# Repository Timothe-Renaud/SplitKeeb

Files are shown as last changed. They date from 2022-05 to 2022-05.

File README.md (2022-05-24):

## SplitKeeb

Repo global de recherche sur les possibles creation de clavier macniques personnalisé type "split".
 Credit a tout les auteurs sauf moi c'est juste que j'ai la mega flemme de cherché leur depots H24
 
Liste des ref necessaire pours monter un ergodone:

 - [ ] keycaps *76 or 80 - anywere you want
 - [ ] Switches *76 or 80 - anywere you want
 - [ ] PCB *2 (2pieces or 1 set of two) - jlpcb.com + gerber files for the pcb
 - [ ] 1 expander mcp23018-E/SP
 - [ ] 2 socket TRRS 3,5mm type FC68129 or 2 CP-43514-ND 
 - [ ] 1 teensy 2,0 without / withoutpins - https://fr.aliexpress.com/item/4001105190306.html?spm=a2g0o.cart.0.0.39ad3c00QT3ftt&mp=1
 - [ ] 24 pins - https://fr.aliexpress.com/item/32552698181.html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,scm-url:1007.13339.169870.0,pvid:e1cd3605-2846-4530-83bc-7d73d2fb3bb8,tpp_buckets:668%230%23131923%2347_668%23888%233325%2313_668%232846%238116%232002_668%232717%237559%2365_668%231000022185%231000066059%230_668%233468%2315618%23985
 - [ ] Diodes *76 or *80 (those are NOT  surface mount) 1N4148 DO-35 - https://fr.aliexpress.com/item/32947233235.html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,searchweb201602_,searchweb201603_
 - [ ] 2 resistances 2,2k ohm, 5% [RRRGold] - https://fr.aliexpress.com/item/32847096736.html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,searchweb201602_,searchweb201603_
 - [ ] 3 leds like T1 3mm - https://fr.aliexpress.com/item/32620034766.html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,searchweb201602_,searchweb201603_
 - [ ] 3 resistances 220 ohm, [ 5% RRBlackGold ] - https://fr.aliexpress.com/item/32847096736.html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,searchweb201602_,searchweb201603_
 - [ ] 1 condensator ceramic 100 nanoF ou 0,1*µF - https://fr.aliexpress.com/item/32971478818.html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,searchweb201602_,searchweb201603_
 - [ ] 1 usb mini b female (the metal thingy)
 - [ ] 1 USB cable male A to male mini B
 - [ ] 1 USB mini B plugUSB mini B plug
 - [ ] jack cable 3,5mm TRRS
 - [ ] case [ or 3d printed yourself ]

 TUTO:
 - http://www.geekymartian.com/articles/building-an-ergodox/
 - 
 TODO:
  - mettre les vraix lien vers les createur & auteur des designe etc

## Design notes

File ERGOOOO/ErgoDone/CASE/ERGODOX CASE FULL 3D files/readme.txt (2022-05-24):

lien des files https://www.thingiverse.com/thing:2533064/files

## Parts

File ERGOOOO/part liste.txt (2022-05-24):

Parts list:

    1x Pair of pcbs (one for each hand) - kk
    1x Teensy USB Board, Version 2.0 - kk
    24x Teensy header pins, male (unless pre-installed)
    1x Microcontroleur MCP23018-E/SP I/O expander - kk
    76-80x 1N4148 diodes, SOD-123 package (Surface mount) or DO-35,(0.3” pitch) (through hole) (again, the amount needed will depend on your layout)
    2x 2.2k Ω resistors (red, red, red)
    3x 3mm T1 LEDs
    3x 220 Ω resistors, or match to LED. (red, red, brown)
    5x Short jumpers (You can also use the clipped off legs from your resistors)
    1x 0.1 µF ceramic capacitor (marked “104” for 10*104 picofarad). Not strictly necessary but suggested
    1x USB mini B connector WM17115
    1x USB mini B plug with short cable (such as H2955)
    1x USB cable male A to male mini B
    2x 3.5 mm TRRS sockets, CP-43514. FC68129 will also work if its extra pins are snipped off
    1x Cable with two 3.5 mm TRRS plugs
    76-80x Cherry MX switches, (depending on your layout)
    76-80x MX Keycaps

+++++https://www.ebay.com/sch/i.html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

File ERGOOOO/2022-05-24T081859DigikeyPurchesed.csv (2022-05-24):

Index | Quantity | Part Number | Manufacturer Part Number | Description | Customer Reference | Available | Backorder | Unit Price | Extended Price EUR
1 | 5 | MCP23018-E/SP-ND | MCP23018-E/SP | IC I/O EXPANDER I2C 16B 28SDIP |  | 5 | 0 | 2,06000 | 10,30
2 | 5 | WM17115-ND | 0548190519 | CONN RCPT USB2.0 MINI B 5P R/A |  | 5 | 0 | 2,11000 | 10,55
3 | 11 | CP-43514-ND | SJ-43514 | CONN JACK 4COND 3.5MM R/A |  | 11 | 0 | 0,85800 | 9,44
4 | 6 | BC2665CT-ND | K104K10X7RF5UH5 | CAP CER 0.1UF 50V X7R RADIAL |  | 0 | 6 | 0,29000 | 1,74
5 | 25 | 220QBK-ND | CFR-25JB-52-220R | RES 220 OHM 5% 1/4W AXIAL |  | 25 | 0 | 0,04520 | 1,13
6 | 25 | 2.2KQBK-ND | CFR-25JB-52-2K2 | RES 2.2K OHM 5% 1/4W AXIAL |  | 25 | 0 | 0,04520 | 1,13

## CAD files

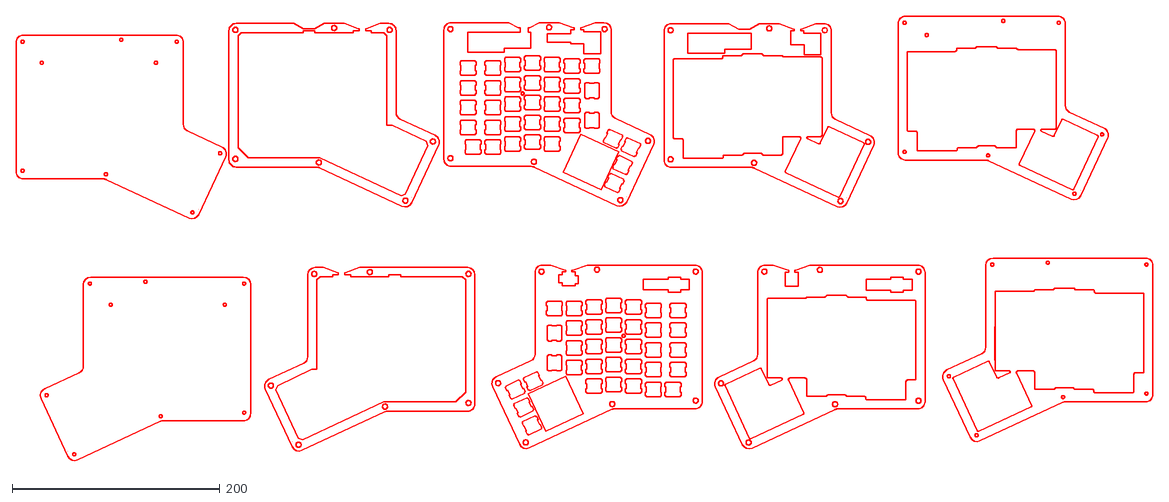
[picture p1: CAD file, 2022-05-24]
ERGOOOO/ErgoDone/CASE/ErgoDoneCase/ergodonecaseoriginal_standard.dxf
1095.3 x 429.0

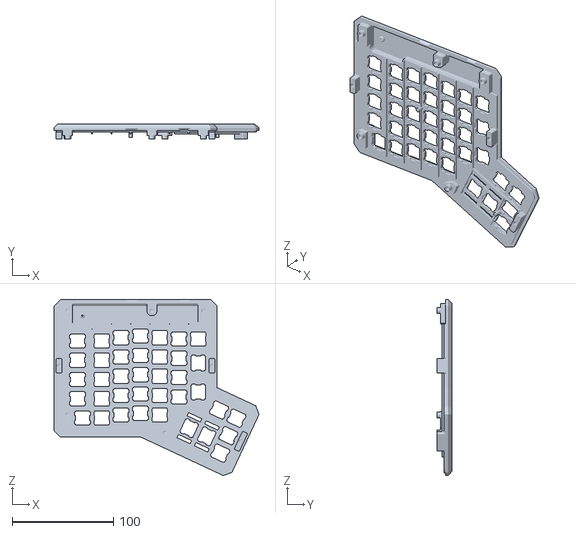
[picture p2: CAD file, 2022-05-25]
ERGOOOO/ErgoDone/CASE/ERGODOX CASE FULL 3D files/MergePlateTopRight.stl
202.4 x 15.2 x 173.8

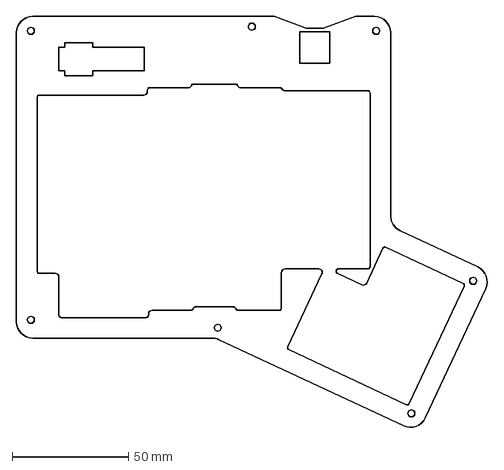
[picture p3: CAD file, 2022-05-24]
ERGOOOO/ErgoDox/ErgoDox Acrylic Case/ErgoDOX Acrylic Case - Designed by Litster/Standard/Left/ErgoDOX Case Layer 2 Spacer - Left.dxf
202.8 x 177.8 mm

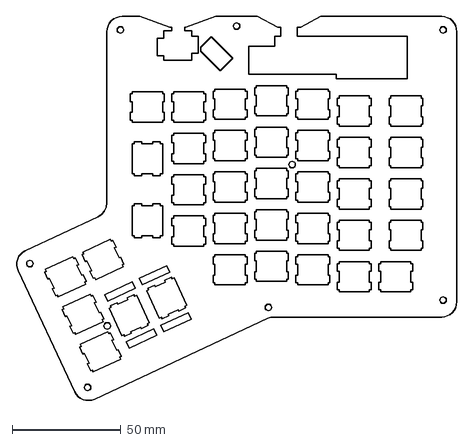
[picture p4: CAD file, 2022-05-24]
ERGOOOO/ErgoDox/ErgoDox Acrylic Case/ErgoDOX Acrylic Case - Designed by Litster/Standard/Right/ErgoDOX Case Layer 3 Plate - Right.dxf
202.8 x 177.8 mm

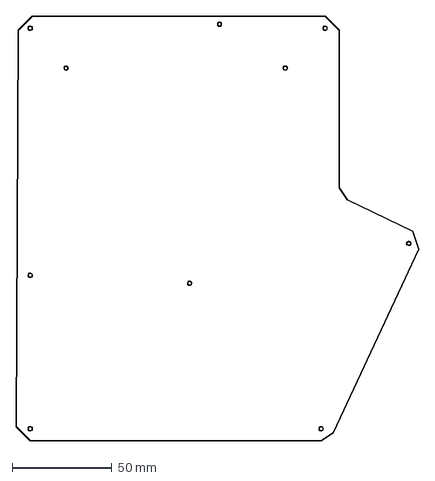
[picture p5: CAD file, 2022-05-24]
ERGOOOO/ErgoDox/ErgoDox Acrylic Case/ErgoDOX Acrylic Case - Designed by Litster/with Wrist Rest/Left/ErgoDOX Case Layer 5 Bottom - Left.dxf
202.0 x 213.0 mm

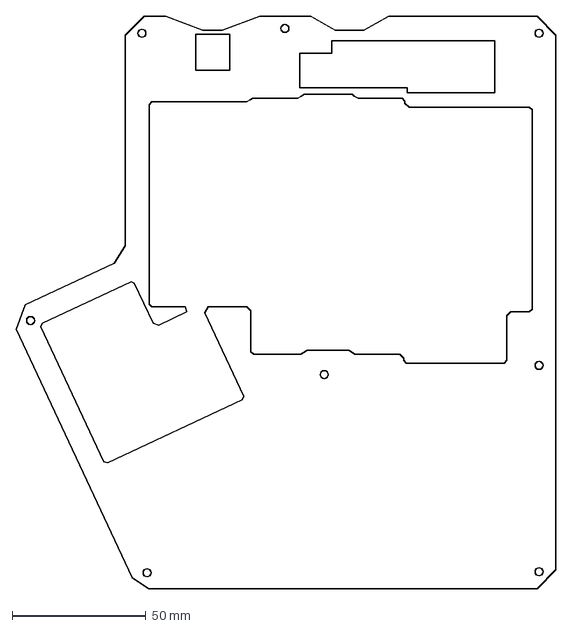
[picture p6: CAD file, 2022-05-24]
ERGOOOO/ErgoDox/ErgoDox Acrylic Case/ErgoDOX Acrylic Case - Designed by Litster/with Wrist Rest/Right/ErgoDOX Wrist Rest Case Layer 2 Spacer - Right.dxf
202.0 x 214.1 mm

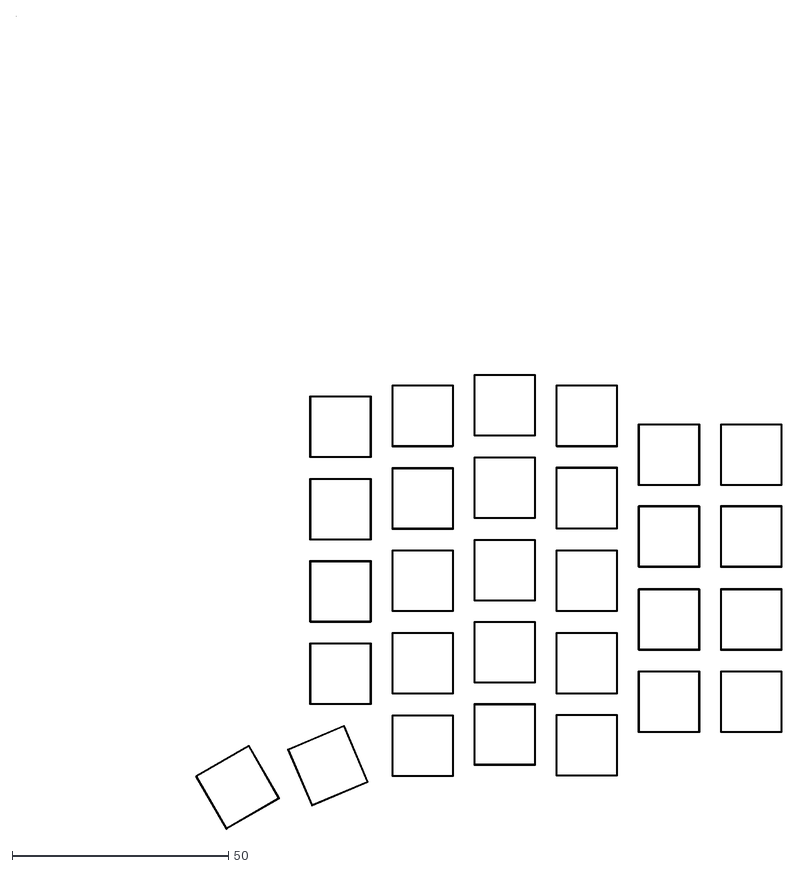
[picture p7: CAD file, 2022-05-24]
OtherTypeOf Keyboard/SOFLE/Design/v2/SofleKeyboard-Eco2_User.dxf
177.2 x 188.0

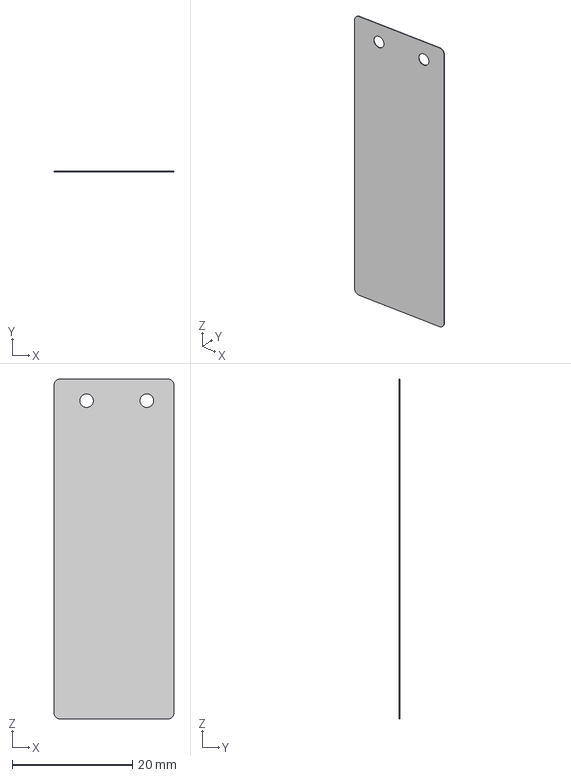
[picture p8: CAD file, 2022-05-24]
OtherTypeOf Keyboard/SOFLE/Sofle_v2/Case/sofle_v2_oled_cover_0.1.step
19.9 x 0.1 x 56.5 mm

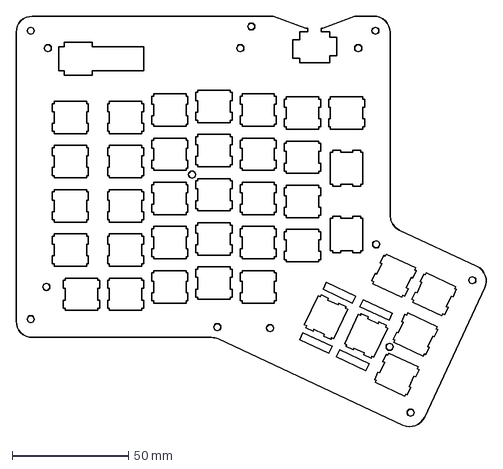
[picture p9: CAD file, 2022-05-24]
ERGOOOO/ErgoDox/ErgoDox Acrylic Case/ErgoDOX Acrylic Case - Designed by Litster/Standard/Left/ErgoDOX Case Layer 3 Plate - Left.dxf
202.8 x 177.8 mm

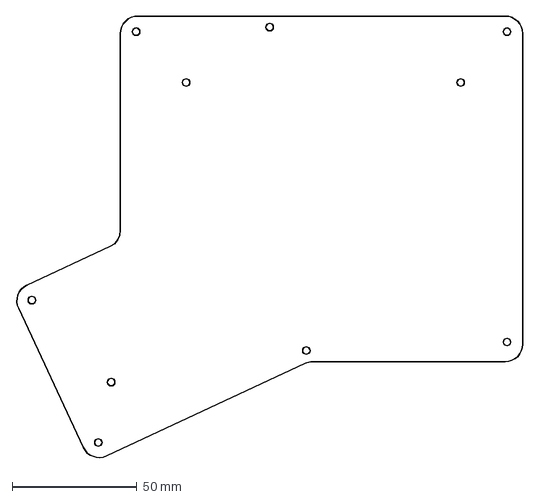
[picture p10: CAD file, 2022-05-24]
ERGOOOO/ErgoDox/ErgoDox Acrylic Case/ErgoDOX Acrylic Case - Designed by Litster/Standard/Right/ErgoDOX Case Layer 5 Bottom - Right.dxf
202.8 x 177.8 mm

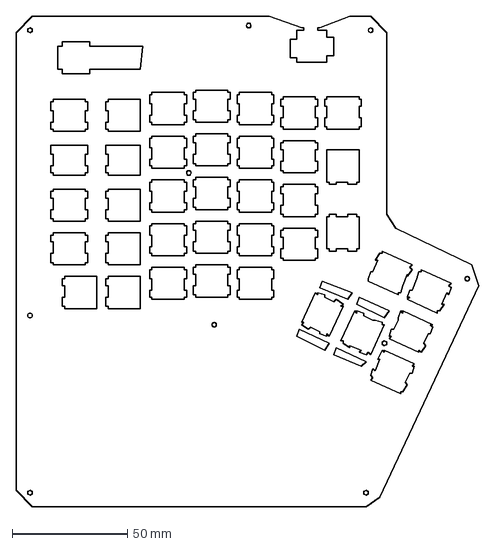
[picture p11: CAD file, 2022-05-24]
ERGOOOO/ErgoDox/ErgoDox Acrylic Case/ErgoDOX Acrylic Case - Designed by Litster/with Wrist Rest/Left/ErgoDOX Case Layer 3 Plate - Left.dxf
201.0 x 213.0 mm

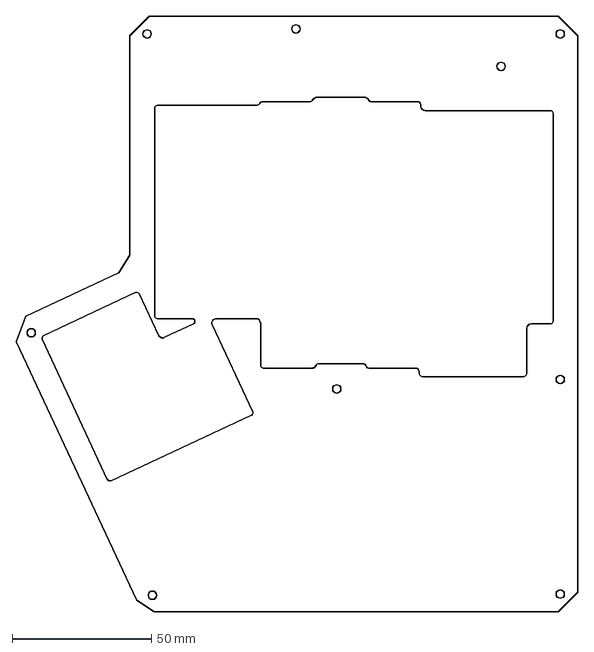
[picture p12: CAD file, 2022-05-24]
ERGOOOO/ErgoDox/ErgoDox Acrylic Case/ErgoDOX Acrylic Case - Designed by Litster/with Wrist Rest/Right/ErgoDOX Wrist Rest Case Layer 1 Top - Right.dxf
202.0 x 214.1 mm

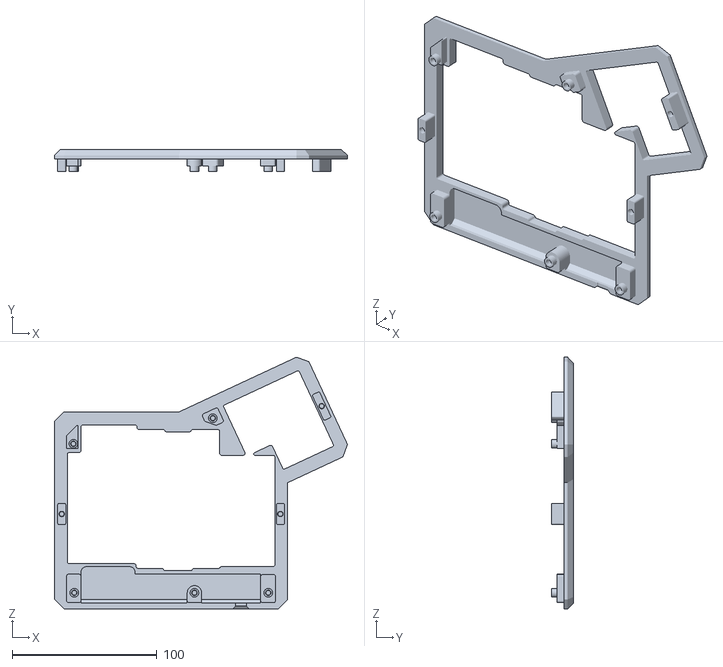
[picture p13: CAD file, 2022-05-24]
ERGOOOO/ErgoDone/CASE/ERGODOX CASE FULL 3D files/LeftTop.stl
202.4 x 15.2 x 173.8

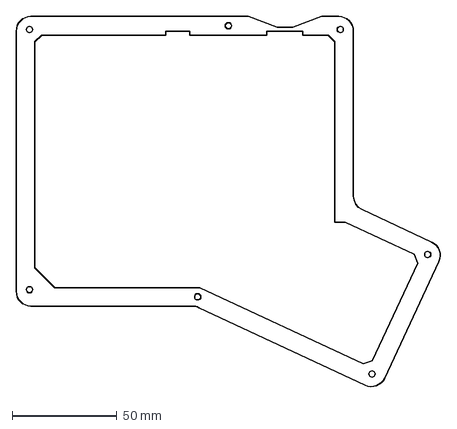
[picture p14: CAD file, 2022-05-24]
ERGOOOO/ErgoDox/ErgoDox Acrylic Case/ErgoDOX Acrylic Case - Designed by Litster/Standard/Left/ErgoDOX Case Layer 4 Spacer - Left.dxf
202.8 x 177.8 mm

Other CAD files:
ERGOOOO/ErgoDone/CASE/ERGODOX CASE FULL 3D files/MergePlateTopLeft.stl
ERGOOOO/ErgoDox/ErgodoxCaseEcoMode/MergePlateTopLeft.stl
ERGOOOO/ErgoDox/ErgoDox Acrylic Case/ErgoDOX Acrylic Case - Designed by Litster/Standard/Right/ErgoDOX Case Layer 1 Top - Right.dxf
ERGOOOO/ErgoDone/CASE/ERGODOX CASE FULL 3D files/LeftPlate.stl
ERGOOOO/ErgoDone/CASE/ERGODOX CASE FULL 3D files/RightPlate.stl
ERGOOOO/ErgoDone/CASE/ERGODOX CASE FULL 3D files/RightTop.stl
ERGOOOO/ErgoDox/ErgoDox Acrylic Case/ErgoDOX Acrylic Case - Designed by Litster/Standard/Left/ErgoDOX Case Layer 1 Top - Left.dxf
ERGOOOO/ErgoDox/ErgoDox Acrylic Case/ErgoDOX Acrylic Case - Designed by Litster/Standard/Left/ErgoDOX Case Layer 5 Bottom - Left.dxf
ERGOOOO/ErgoDox/ErgoDox Acrylic Case/ErgoDOX Acrylic Case - Designed by Litster/Standard/Right/ErgoDOX Case Layer 2 Spacer - Right.dxf
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

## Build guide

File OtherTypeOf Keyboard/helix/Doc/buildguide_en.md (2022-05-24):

# Helix Beta Build Guide

## Parts

The list below is for one half. To build both halves, you will need two sets of these parts.

| Name | Quantity | Notes |
| ---- | ---- | --- |
| PCB | 1 | |
| Pro Micro | 1 | |
| TRRS Jack | 1 | |
| Tactile Switch | 1 | |
| Spring-loaded pin headers 12-pin | 2 | Regular headers will also work |
| Plate (Acrylic or Stainless) | 1 set | |
| Display Cover Plate | 1 | |
| M2 Spacer 4mm | 6 | For low-profile switches |
| M2 Spacer 7mm | 6 | For MX-style switches |
| M2 Spacer 8mm | 2 | |
| M2 Screw 3mm| 14 | |
| M2 Low Profile Screw 5mm| 2 | |
| Rubber Bump-Ons | 6 |  |
| Diodes | 32 | SMD diodes are required for low-profile switches. |
| Keyswitches | 32 | Either Cherry MX or Kailh Low-Profile compatible |
| Keycaps | 32 | Whichever caps suit the switches |
| 3.5mm Aux Cable | 1 | For the split connection |
| MicroUSB Cable | 1 | |
| Insulating Sheet | 1 | For stainless steel plates (Optional) |
| WS2812B Strip (6 LEDs) | 1 | For underglow (Optional) |
| SK6812mini | 32 | For backlight (Optional) |
| OLED Module | 1 | For OLED display (Optional) |
| Socket, 4-Pin | 1 | For OLED display (Optional) |
| Headers, 4-Pin | 1 | For OLED display (Optional) |

## Necessary Tools

| Name | Notes |
| ---- | ---- |
| Soldering Iron | If using backlight LEDs, it must be temperature-controllable. |
| Thin solder | ~0.8mm diameter recommended |
| Tweezers | For SMD part assembly |

## Selecting Options
Before beginning assembly, it will be necessary to decide on the options for the build.

### Row Quantity (5 or 4)
By breaking away the bottom row, you can select the row quantity.

### LED Selection (Underglow or Backlight)
Either the per-key backlight or below-PCB underglow may be selected.

## Building the Helix

The guide will focus on the left half. For the right, simply flip the PCB.

Imgur

__It is strongly recommended to read the ENTIRE build guide first before beginning work.__

### Preparing the PCB

If installing the optional OLED display, jumpers must be connected.
Please solder the four jumpers on the __upper side__ of the PCB on both halves.
(Do not solder jumpers on both the front and rear.)

Imgur

### Installing Parts

#### Diodes

Install diodes onto the __bottom__, whether through-hole or surface mount.  Note: if using choc low profile switches surface mount diodes are recommended as through hole diode legs would need to be flush on the top of the board to allow the top plate to sit correctly.  See issue [22](https://github.com/MakotoKurauchi/helix/issues/22) for details and work arounds.

Make sure all diodes are installed in the correct orientation.
Even when the silk label is invisible, all diodes face the same orientation.

Imgur

Imgur

#### Backlight LED (Optional)

Backlight LEDs are installed from the **bottom** of the PCB. Verify the orientation of the LEDs when installing - the largest pad should align with the corner marked with the circle on the silkscreen layer.

There are some places where this silkscreen is invisible; however, all LEDs of each row face the same orientation. However, **not all rows share the same orientation** (they switch orientation by 180 degrees each row).

Using a variable temperature soldering iron, solder the LEDs into place at roughly 220C (428F). __Overheating the LEDs will destroy the LEDs.__

Imgur

Imgur

An efficient method is to solder the largest pads on the entire row, then to do the rest of the pads.

#### TRRS Jack

Install from the topside following the silkscreen.

Imgur

#### Reset Switch

Install from the topside as marked by silkscreen.

Imgur

#### Pro Micro

Solder the spring loaded header to the pro micro, making sure that the bottom side faces upwards.

Imgur

The recommended orientation is the following.

Imgur

The smaller windows should be on the Pro Micro side.
Also, install so both sets of headers have the small windows facing the same orientation.

Imgur

Imgur

Installing in the wrong orientation or applying significant force before soldering will lead to the pins ejecting. Also, the legs are easily bent; please take care when inserting and removing the Pro Micro from the PCB.

With the bottom side up, insert the header-loaded Pro Micro onto the through-hole pads. Even without soldering, it should lock into place.

Imgur

#### OLED Module (Optional)

Install sockets on the topside, and solder the headers onto the OLED module.
Install the OLED module so it covers the Pro Micro below.

Imgur

Imgur

#### RGB Underglow Strip

After verifying orientation, either solder into place or solder using jumper wires.

Imgur

#### Switches

Install switches to the plate, then to the PCB, and solder.
Be careful of solder bridges when other parts are close by.

Imgur

* At this point, it is recommended to flash the [firmware](firmware_en.md), and to verify that everything functions properly.

### Final Assembly

Install two 8mm standoffs on the topside, and screw into place.

Imgur

Using 4mm standoffs on low-profile and 7mm for MX, secure the bottom plate into place as to sandwich the PCB.

Imgur

Install the display-protecting plate using the low-profile screws.

Imgur

Install bump-ons.

Imgur

The build is complete.

Imgur

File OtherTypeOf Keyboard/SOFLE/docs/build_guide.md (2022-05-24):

---
layout: default
title: Sofle Keyboard - build guide (v1/v2)
---

This guide suits both version **V1** and **V2** of the standard (**non-RGB**) Sofle Keyboard. Most of the photos are for v1 and the differences are explained in the text as needed.

The **RGB** version has [dedicated build guide][rgbbuildguide].

The **Choc** version has [dedicated build guide][chocbuildguide].

If you don't have all the necessary parts, please read about [how to source the parts][sourcing].

## Bill of materials

The following is needed to build the keyboard. You can find [links for the most of the components in the sourcing parts section][sourcing].

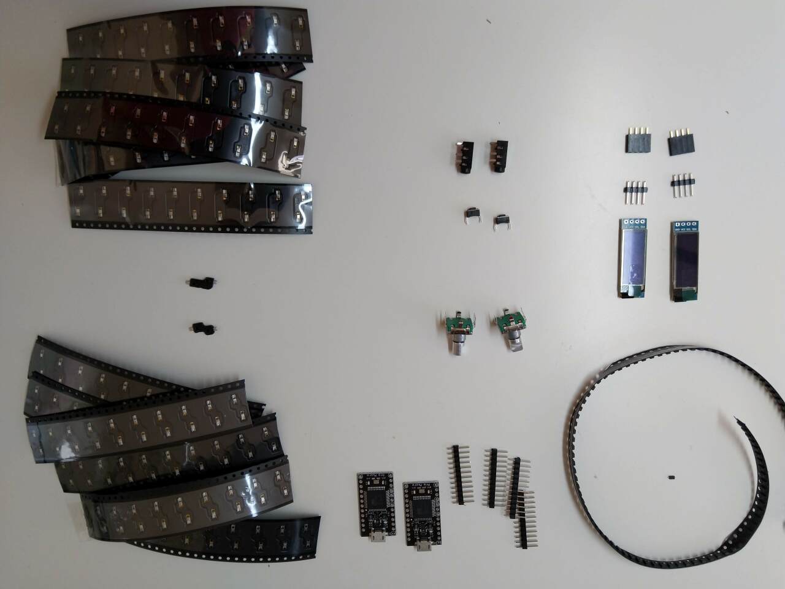
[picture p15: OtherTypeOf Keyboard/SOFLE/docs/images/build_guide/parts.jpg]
SofleKeyboard parts


- **2 PCBs** (see [sourcing][sourcing])
- **2 top plates**, **2 bottom plates** for a sandvich-case build. (see [sourcing][sourcing])
- **58 keyboard switch sockets by Kailh**. The PCB supports either sockets for traditional MX switches or sockets for Kailh Choc switches. **Note that version 2 supports only MX.** They are available on Aliexpress, KBDFans and others. 
- **58 keyboard switches** of your preference, either MX or [Kailh Choc][choc]. Just make sure you have matching sockets for them. **Note that version 2 supports only MX**.
- **58 keycaps**. You can use either all in `1u` size but it looks nicer with two `1.5u` for the thumb keys.
- **58 diodes  1N4148W**. They are surface mount diodes in SOD123 package.
- **2 TRRS connectors**. The same type which is used for Corne, Lily58 etc. Technically even TRS should work[^1] if you stick to (default) serial communication. 
- **2 tactile buttons** through-hole, 2 pins. Technically optional: you can use metal tweezers whenever you need to reset the microcontroller. There's also a reset key on default layout so as long as you have firmware flashed and working you shouldn't need reset button on the board. 
- **1 TRRS cable**. TRS should work[^1] if you stick with Serial. 
- **10 (+4) M2 spacers**. 10 are going to hold the bottom and the top together. Their height depends on which switches you use. A build guide Lily58 Pro suggests `4mm` for Choc and `7mm` for MX. I was not able to get `7mm`, but `6mm` worked well for me with MX switches. I used brass ones but you can also buy nicer from anodised aluminium. Another 4 would be needed to hold transparent OLED cover but even though there are mounting holes in the PCB.
- **20 (+8) M2 screws**. 20 are going to hold the boards together (via spacers). I used some I had in my stock so I am not going to tell you exact length. But they need to be long enough to fix a `1.6mm` thick PCB to the spacer and short enough so two of them can fit in one spacer (might be trickier with 4mm spacers for Choc switches)
- **8 - 10 adhesive rubber feet**. They are really important, trust me.
- **2 ssd1306 128x32 OLED display module**. Very common everywhere. 
- **2 OLED covers** Optional. OLED cover should be cut from transparent acrylic. Source file for [version 1 is avalalble in the repostiory](https://github.com/josefadamcik/SofleKeyboard/tree/master/Sofle_v1/Case). There is no OLED cover for version 2 available yet.
- **2 Rotary encoders EC11**, optional. So far I have used only one but 2 are supported. If you are not sure take EC11E. Some other variants (EC11K) may have some additional plastic pins for and require mounting holes for them (which are not included on the PCB).
- **A matching knob** for each encoder. 
- **2 Pro Micro**board or clone. With 2x12 pins and ATmega32U4 microcontroller. Just make sure you **don't** buy something like Arduino Micro (a different pinout) or Arduino Mini (different microcontroller). You could also use Elite-C which basically Pro Micro with USB-C.
- **4x12 pin header (and optionally socket)** for Pro Micros. There are several ways how to mount Pro Micros to the board. Either the male PIN headers you most likely got with the board from the supplier could be used to solder it directly to the board. Build guides for Helix, Corne and Lily58 suggest [those spring pin headers][springpinheader] which are very compact and give you non-permanent connection (you can remove or replace Pro Micros). Another possible approach [is described at splitkb.com][promicrosocketing].
- **2x4 pin header (and optionally socket)** for OLEDs. I have used the most common 1x4 female pin sockets which are quite tall but they also fit the height of ProMicro with the sockets I have used. Unfortunately, the pin headers on my OLED modules (again those very common square male headers you would get with the modules) are loose in the sockets. It works but it's fiddly. I'll have to find a better solution.
- **Micro USB Cable** to connect the keyboard to a computer.

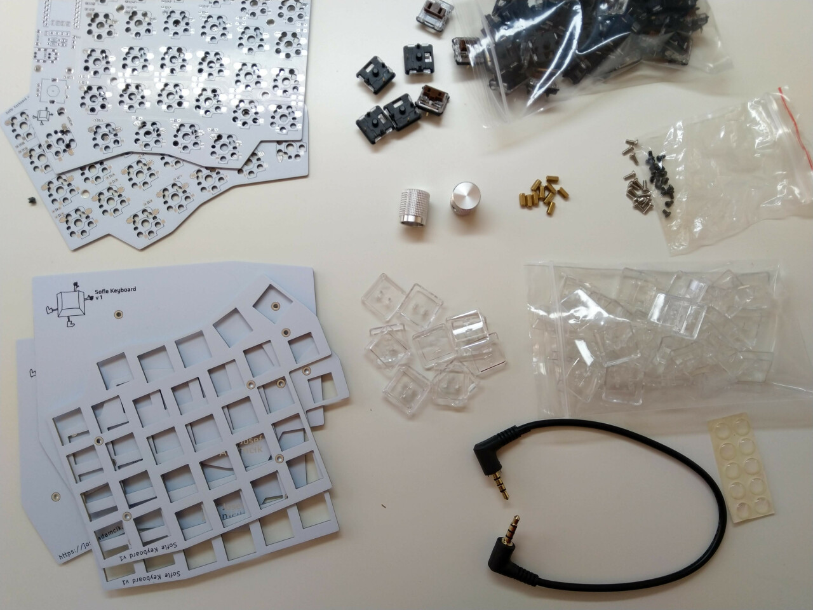
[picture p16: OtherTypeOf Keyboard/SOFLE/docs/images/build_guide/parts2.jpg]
SofleKeyboard parts 2


That's it. There are no RGB LEDs on the board. But if you really need underglow it is be possible to connect an RGB LED strip since there are 3 pads (VCC, GND and data) on the board. You would need to add support to the firmware on your own.

## Tools and materials

- soldering iron
- solder 
- good tweezers
- masking tape
- isopropyl-alcohol for cleaning 
- screwdriver

## Warnings and disclaimers

- Think twice, solder once. Desoldering is frustrating and it's easy to mess up things.
- Don't connect or disconnect the TRRS cable when the keyboard is powered. It may short out. Always disconnect the USB cable first.
- Be gentle with the USB on your microcontroller. They are easy to break.
- Keep in mind that this is a prototype of a DIY keyboard. It's not a polished product.

## Steps

### Prepare

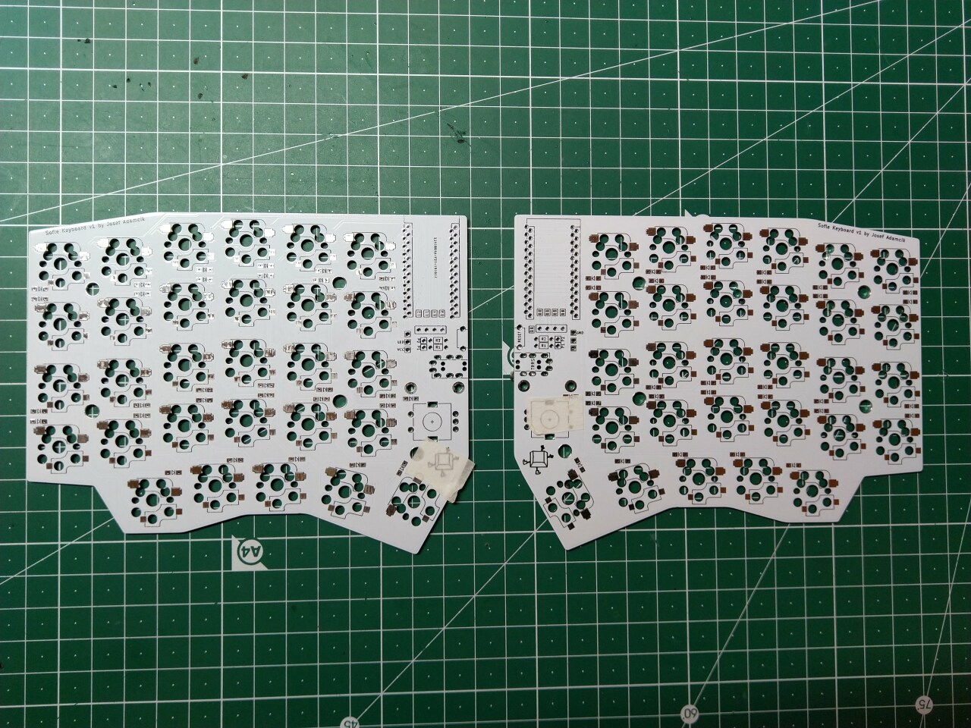
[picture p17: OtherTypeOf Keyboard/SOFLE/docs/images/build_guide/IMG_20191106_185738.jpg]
Step 1


Both sides of the keyboard ready. The front sides marked by pieces of tape in order to remember which side is which.

### Components on the backside 

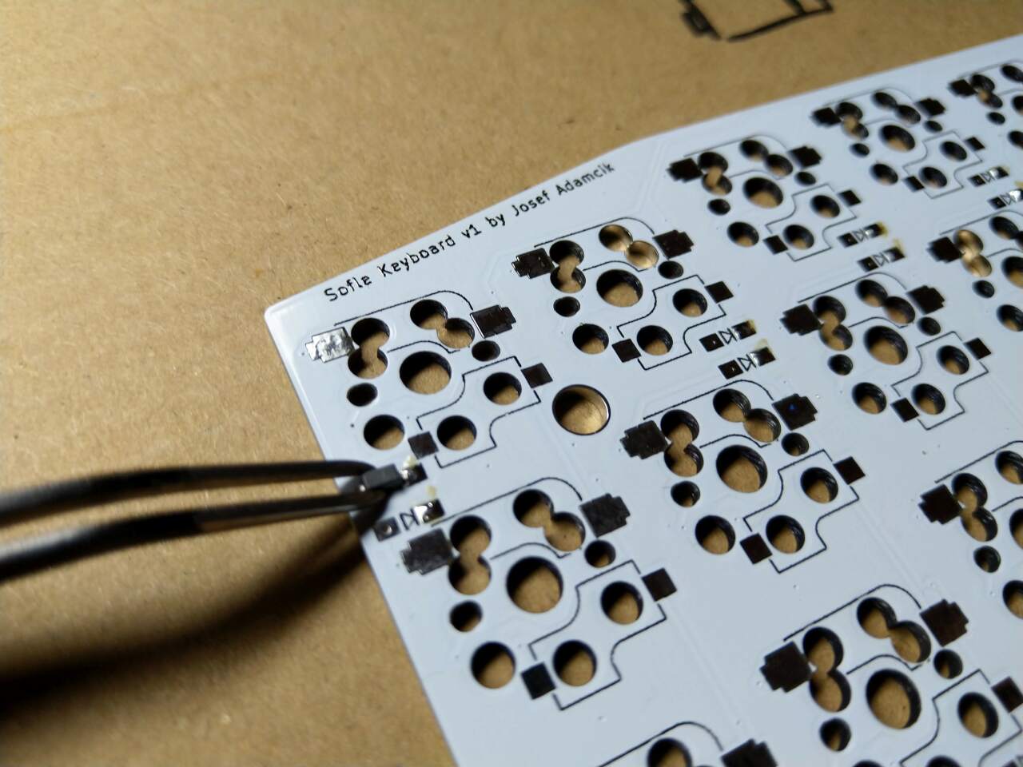
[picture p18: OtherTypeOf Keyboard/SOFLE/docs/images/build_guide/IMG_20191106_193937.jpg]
Step 2


Starting with the diodes. They belong to the backside of the PCB. Make sure you have orientation right - they are all oriented to the same side. The end with the thin line is Cathode (-) and it should go in the direction of the "arrow" symbol on the PCB.

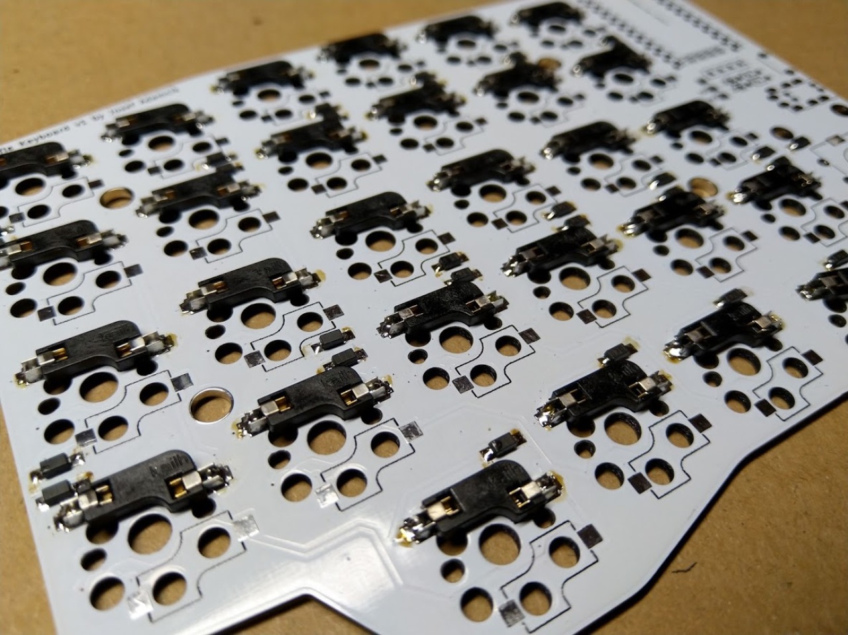
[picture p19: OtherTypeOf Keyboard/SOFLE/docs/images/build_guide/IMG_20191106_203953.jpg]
Step 3


Sockets for switches belong again on the back side, the same side as diodes. Make sure they are flush with PCB. Watch the markings on the silkscreen which show the correct orientation.

### Components on the front side

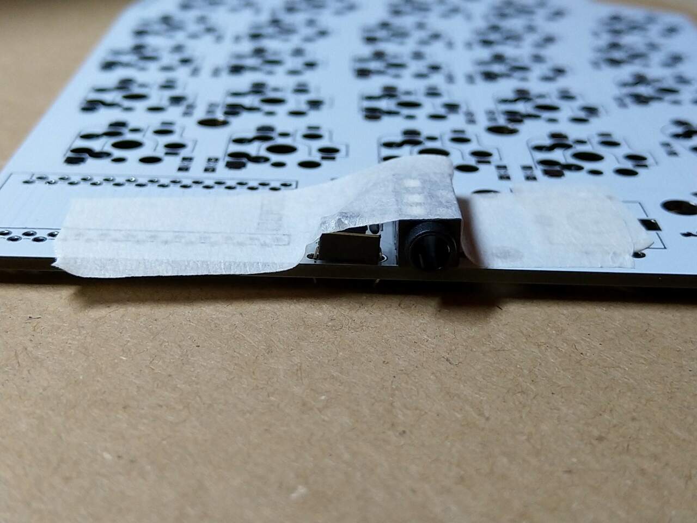
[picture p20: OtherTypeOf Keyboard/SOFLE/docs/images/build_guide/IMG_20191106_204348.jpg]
Step 4


Button and TRRS sockets belong to the top. Use a piece of tape to fix them and apply solder from the bottom side.

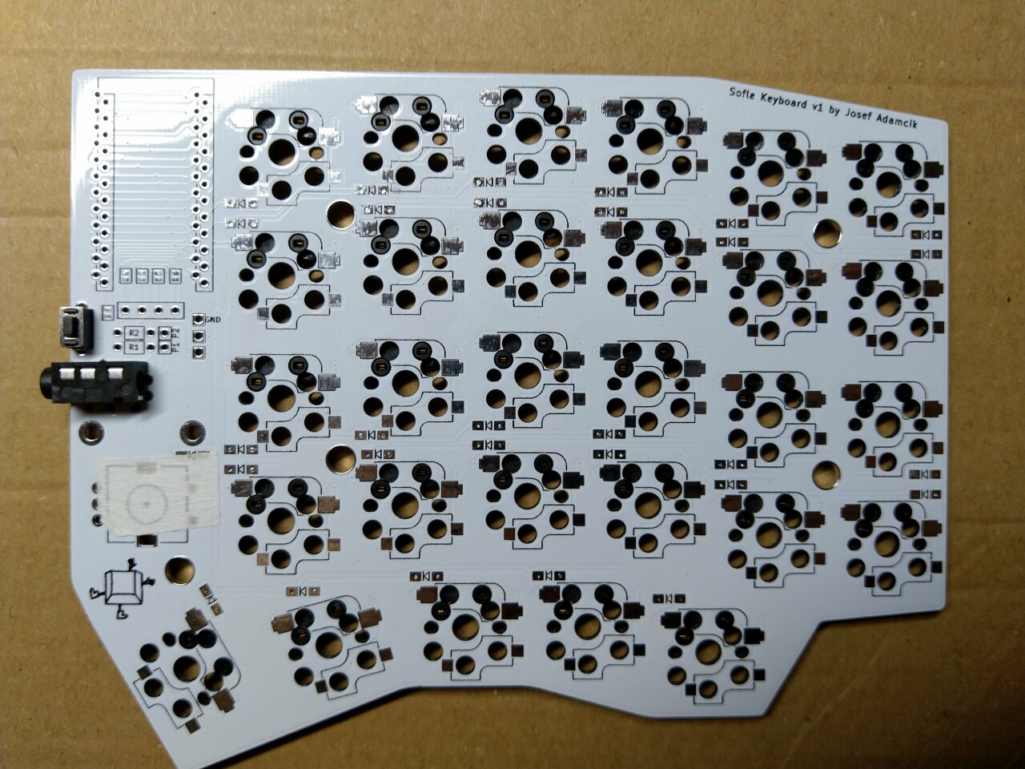
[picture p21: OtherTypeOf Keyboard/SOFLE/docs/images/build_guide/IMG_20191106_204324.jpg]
Step 5


This is how the right half should look from the top.

### Pro Micro and displays

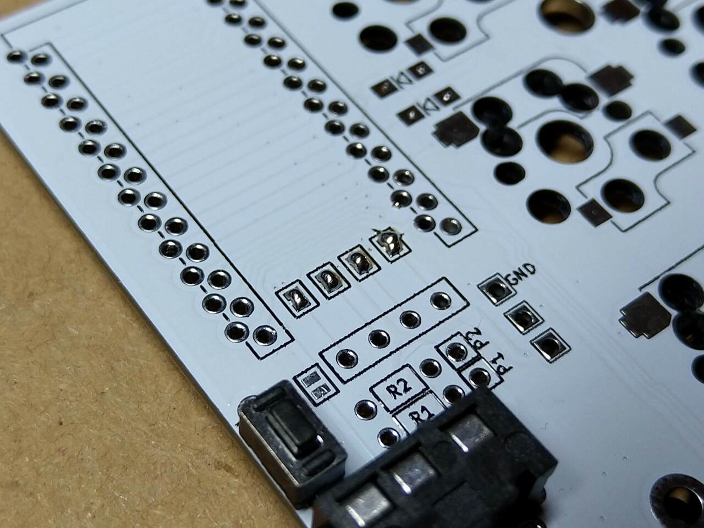
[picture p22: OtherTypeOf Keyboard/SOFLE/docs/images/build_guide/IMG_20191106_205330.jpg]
Step 6


Bridge 4 jumper pads on the top side. They are necessary for OLED support and if you don't socket you Pro Micro you will not be able to do it later.

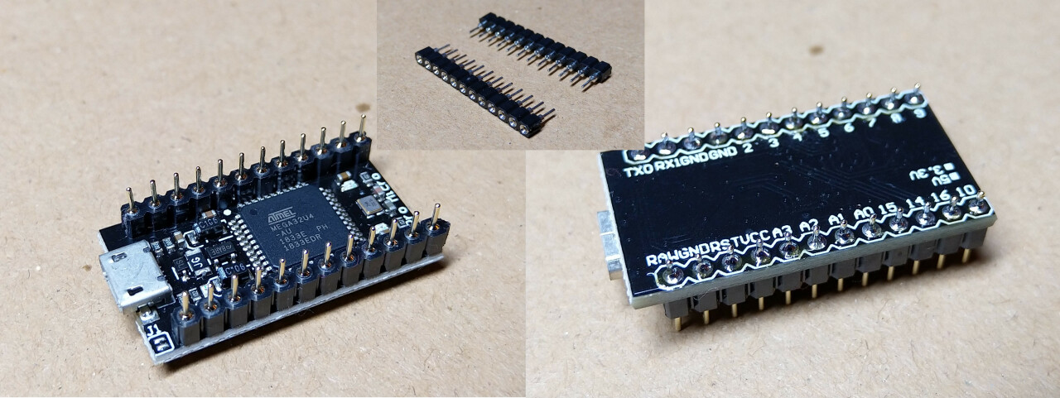
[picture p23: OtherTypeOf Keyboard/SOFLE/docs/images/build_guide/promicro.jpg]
Step 7


Prepare the Pro Micro. There are several ways how to do it. I have used rounded pin headers. A bit more information about [socketing of Pro Micro is on the sourcing parts page][sourcing]. 

**Keep in mind the orientation**: 

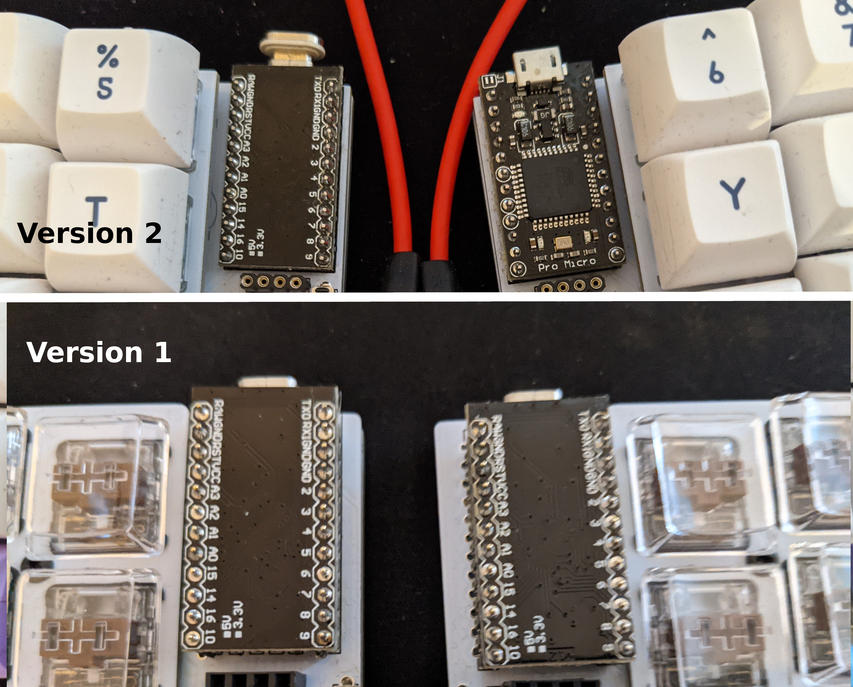
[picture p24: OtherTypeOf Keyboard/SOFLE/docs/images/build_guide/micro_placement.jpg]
Pro micro orienation


Version 1: the Pro Micro board should be mounted "bottom-up". Its clean side should be at the top, visible. The side with chips and other electronics should be at the bottom facing the main PCB. 

Version 2: The left side as for version 1. The right half has the pro micro mounted up-side up so it's mounted differently on each half. 

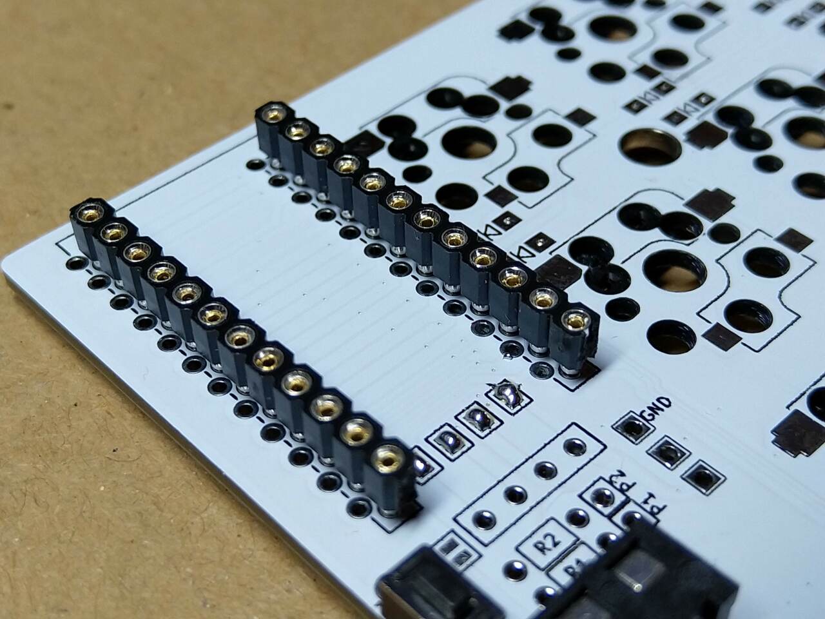
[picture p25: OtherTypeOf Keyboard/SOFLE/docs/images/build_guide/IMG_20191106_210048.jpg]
Step 8


And corresponding sockets (if used) on the front side of the board. Version 1: Make sure you insert them into the holes which are marked by the rectangles. Version 2: there's only one option so it is straightforward.

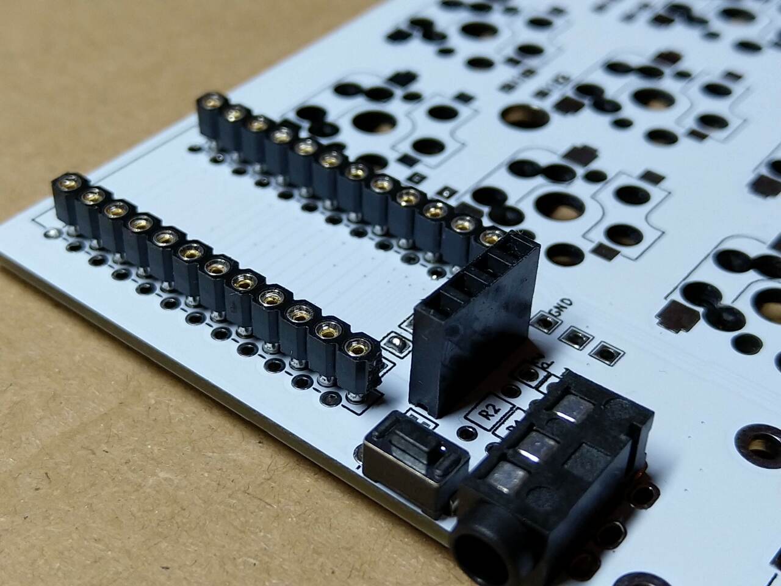
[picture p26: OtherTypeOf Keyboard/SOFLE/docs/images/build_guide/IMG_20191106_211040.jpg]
Step 9


Add socket for OLED display. Keep in mind height of your Pro Micro which may be different based on if/which socket's you have used for Pro Micro. Check everything before soldering.

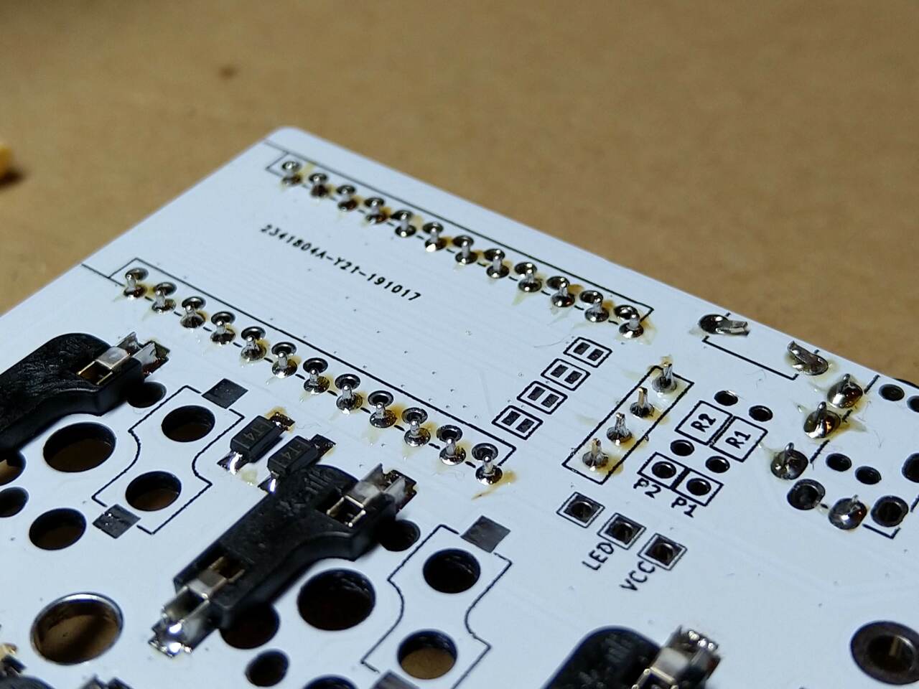
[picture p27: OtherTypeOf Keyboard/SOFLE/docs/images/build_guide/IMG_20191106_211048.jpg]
Step 10


This is how the backside (bottom) should look at this stage.

### First test

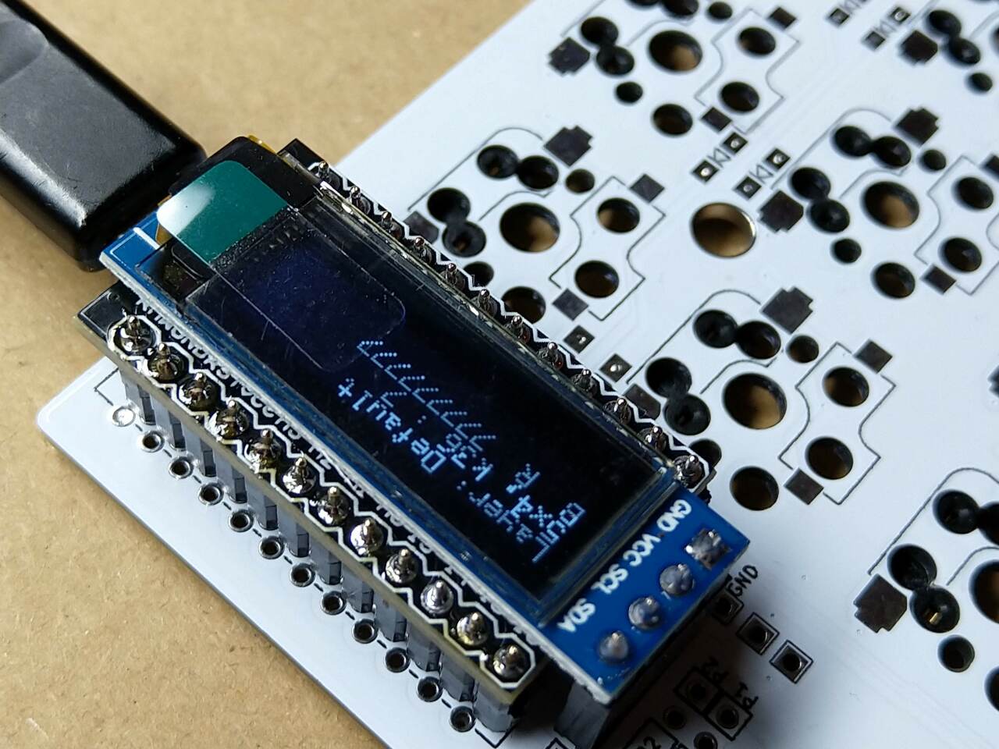
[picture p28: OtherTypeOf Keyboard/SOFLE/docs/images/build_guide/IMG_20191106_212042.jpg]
Step 11


Now it is already possible to connect the ProMicro and OLED display to the board, flash the firmware and check if all keys work using a piece of wire or tweezers.

### Rotary encoders

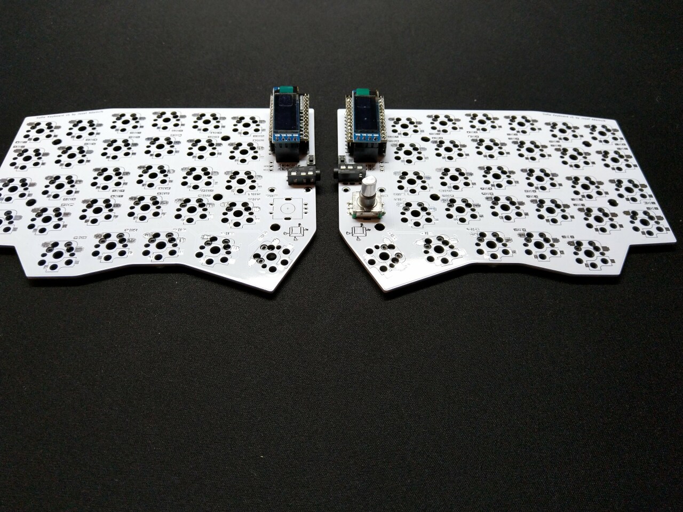
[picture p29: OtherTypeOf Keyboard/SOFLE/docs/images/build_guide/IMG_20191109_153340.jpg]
Step 12


Both halves assembled, a rotary encoder can be added on both, one or none. I have also cleaned flux residue from the back side using some isopropyl alcohol, cotton buds and paper towels.

### Keyboard switches and plates

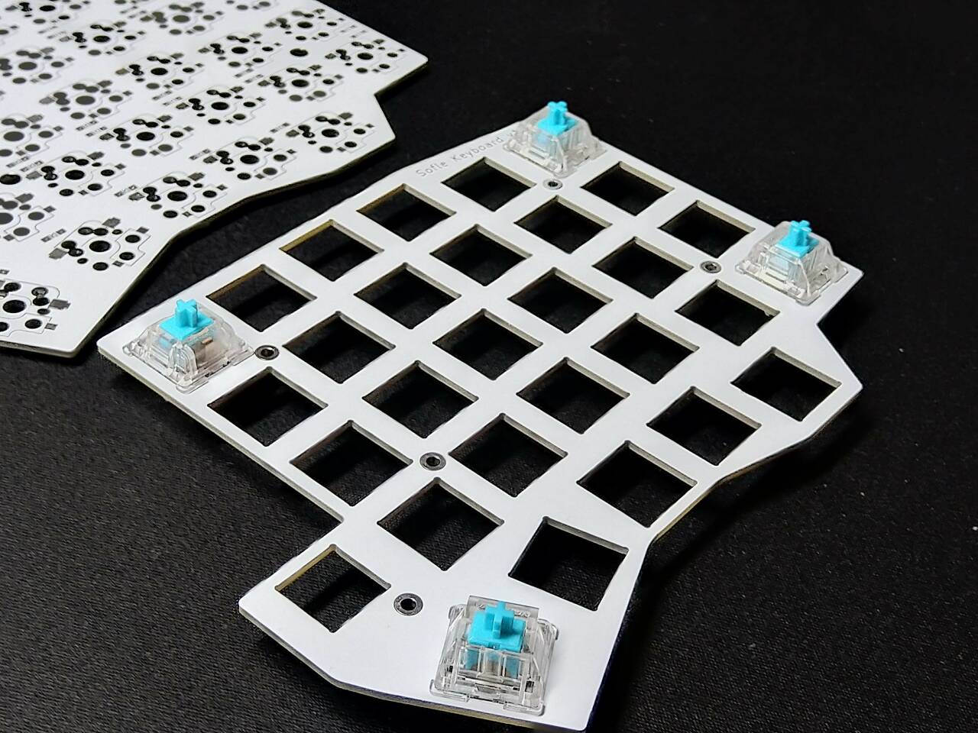
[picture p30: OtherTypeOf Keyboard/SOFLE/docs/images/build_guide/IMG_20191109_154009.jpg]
Step 14


Snap first switches into corners.

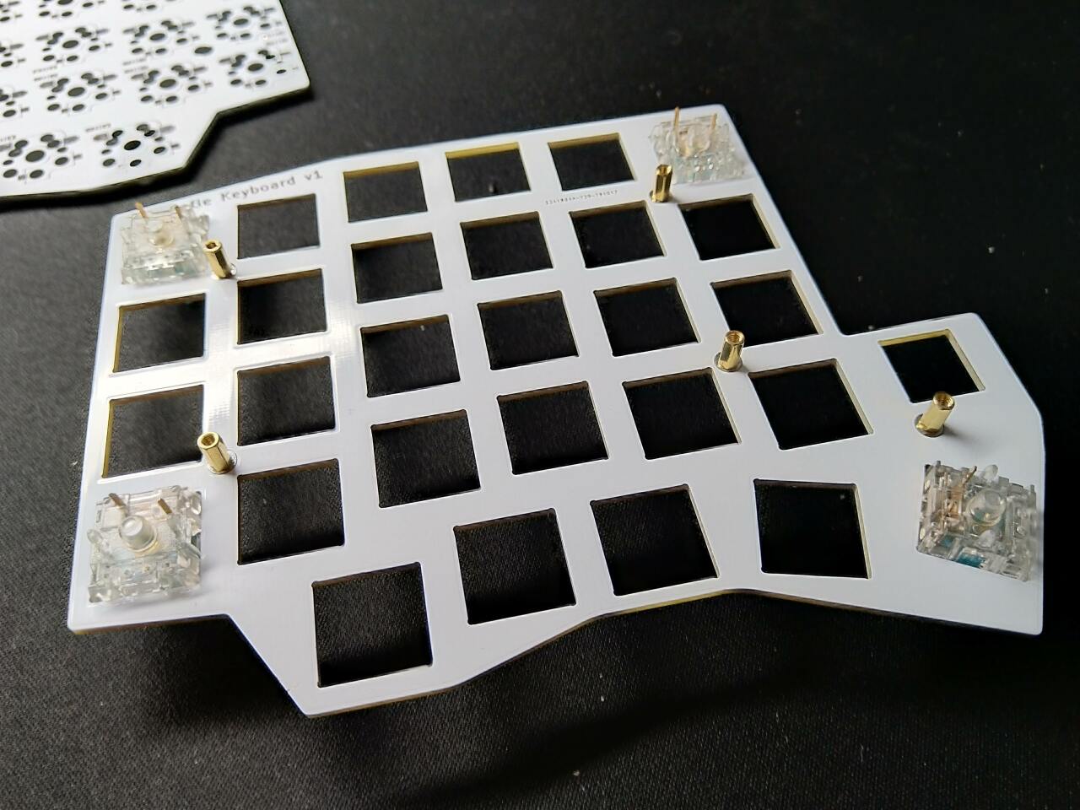
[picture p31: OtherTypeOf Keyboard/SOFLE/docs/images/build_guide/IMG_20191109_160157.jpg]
Step 15


Mount the stand-offs to the top plate.

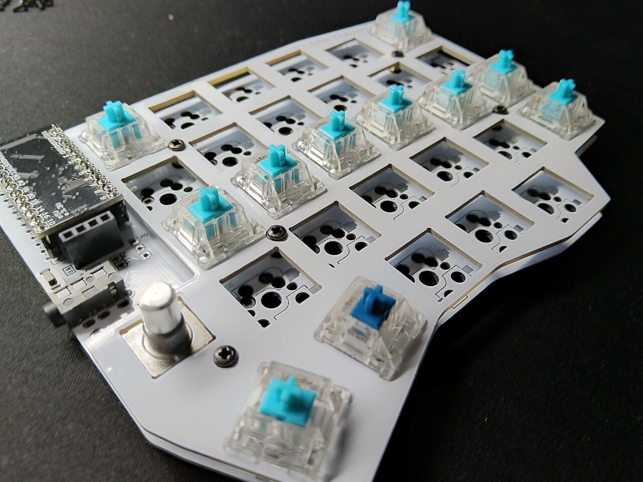
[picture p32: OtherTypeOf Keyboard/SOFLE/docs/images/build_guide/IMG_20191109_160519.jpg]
Step 16


Carefully snap the first switches to the sockets. Be careful so you don't bend their contacts. Add more.

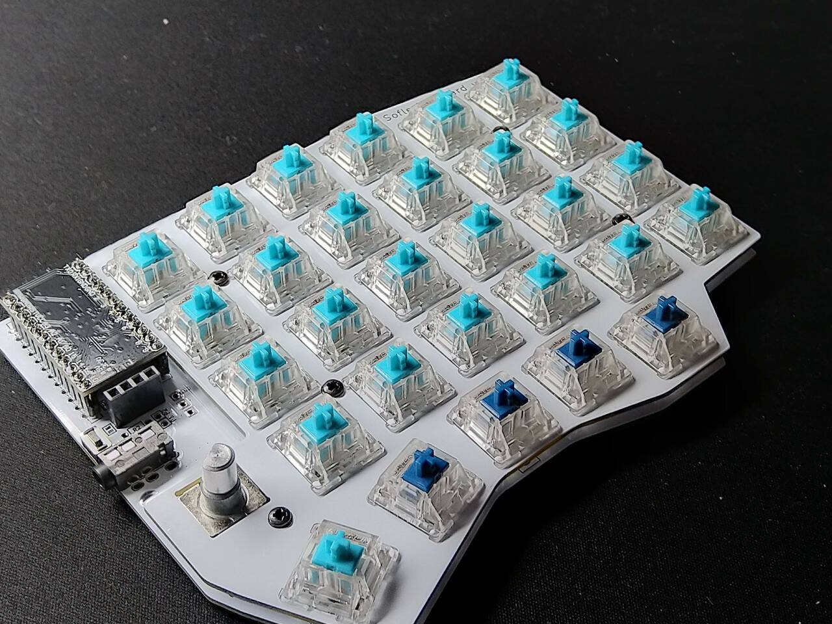
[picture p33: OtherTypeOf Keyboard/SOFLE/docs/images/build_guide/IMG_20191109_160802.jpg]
Step 17


Until they are all in place.

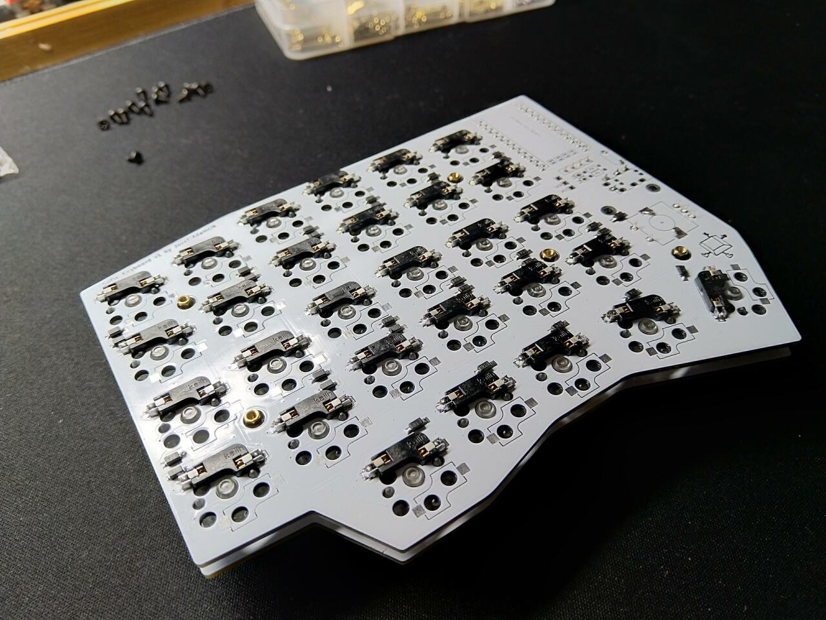
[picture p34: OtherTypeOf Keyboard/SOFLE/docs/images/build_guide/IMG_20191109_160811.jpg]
Step 18


Double-check the bottom. You should see all the contacts in sockets.

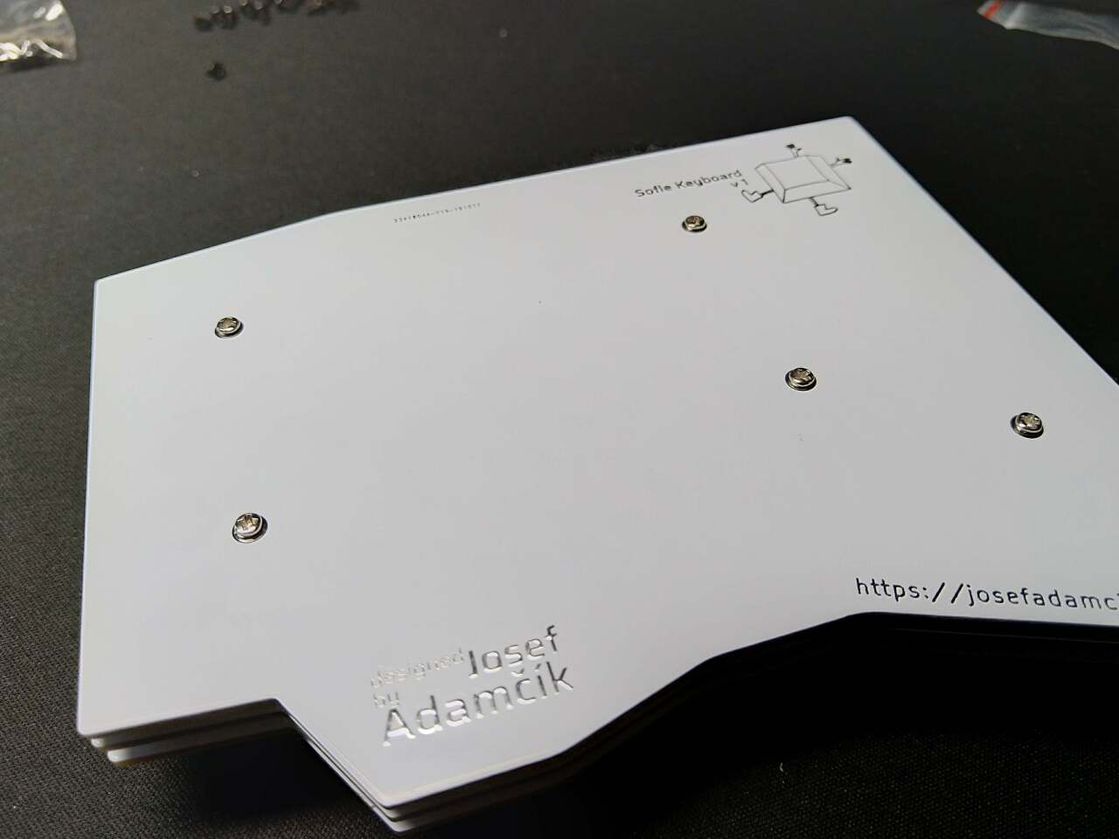
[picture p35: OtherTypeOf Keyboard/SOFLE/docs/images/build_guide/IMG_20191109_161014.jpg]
Step 19


And mount the bottom plate.

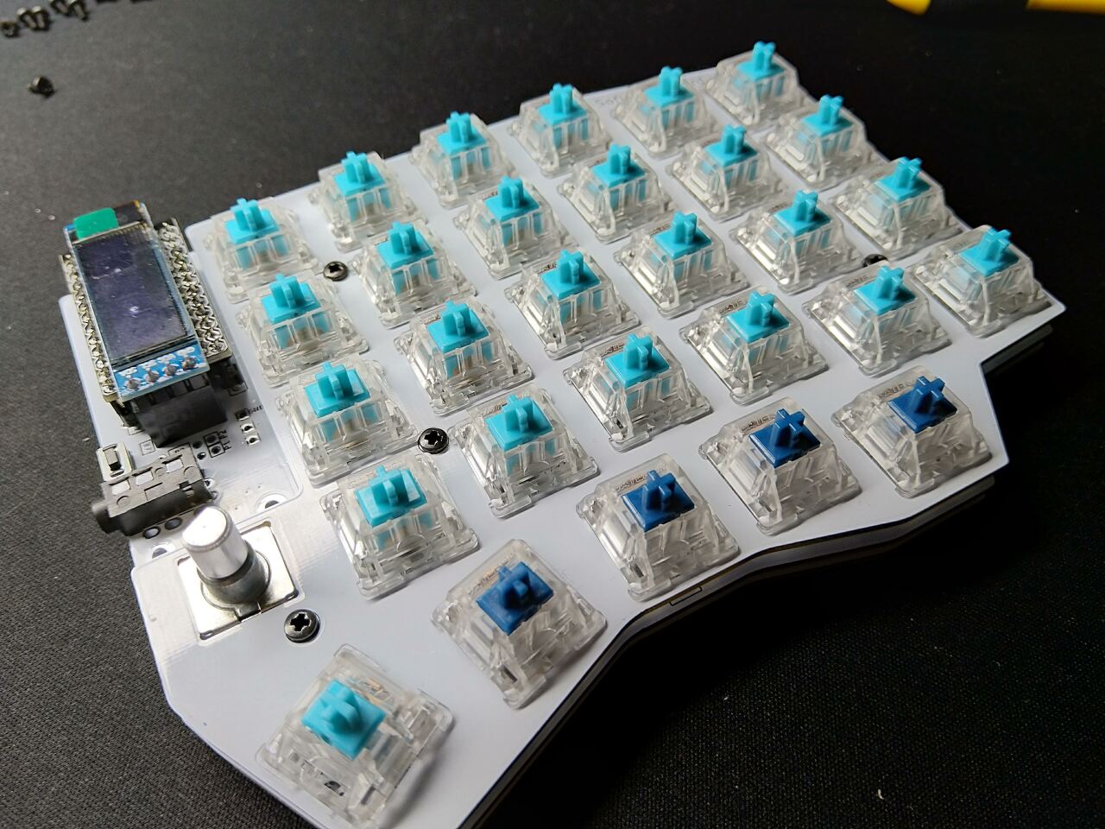
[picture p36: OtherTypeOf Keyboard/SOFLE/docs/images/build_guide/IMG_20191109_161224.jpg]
Step 20


Completed half of the keyboard waiting for keycaps.

### Finishing touches

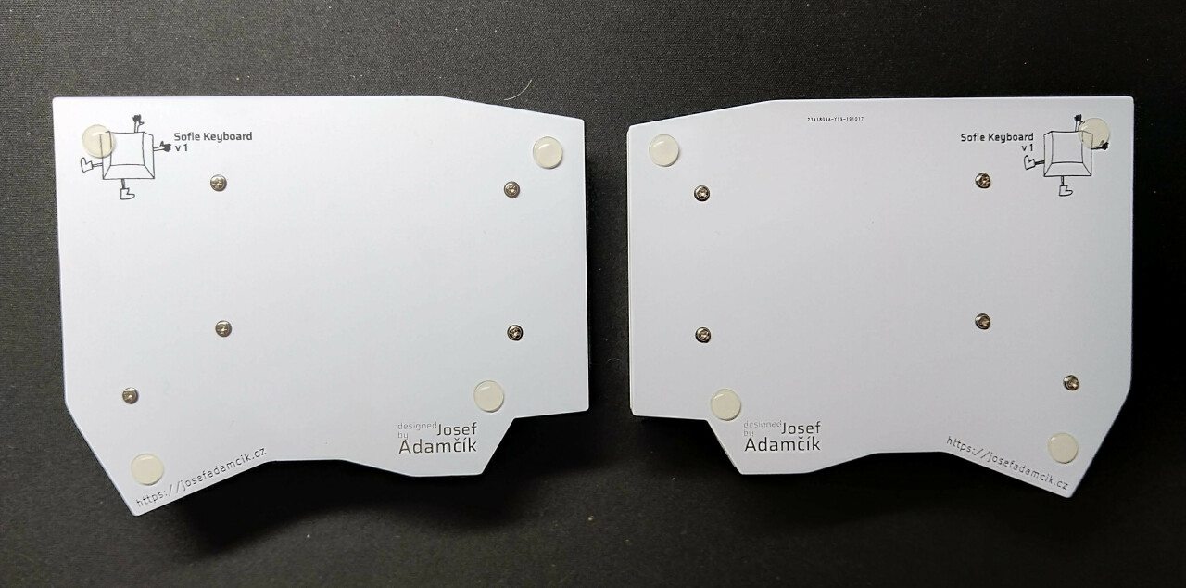
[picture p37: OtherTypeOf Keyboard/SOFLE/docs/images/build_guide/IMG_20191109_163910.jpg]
Step 21


Put at least 4 adhesive rubber feet in the corners so the keyboard is not moving when you type.

## Warnings and disclaimers

- Don't connect or disconnect the TRRS cable when the keyboard is powered. It may short out. Always disconnect the USB cable first.
- Be gentle with micro USB ports on your microcontrollers. They are easy to break.
- Keep in mind that this is a prototype of a DIY keyboard. It's not a polished product.

## Firmware and programming

Sofle keyboard uses [QMK Firmware][qmk_firmware] and support for the board is part of the main QMK repository. There's also a basic support in [QMK Configurator][qmk_configurator] but there's no default layout yet and encoders are not supported.

Suggested approach is to build the firmware yourself. You should be familiar with QMK and be able to make it work on your local environment. If not, please [follow the instructions in the documentation][qmkintro].

- Make sure your QMK environment [is setup][qmkintro].
- Make sure halves are not connected together with TRRS cable.
- Connect one half to USB, flash the firmware (always follow the actuall instructions in the QMK documentation! The command might look something like this: `qmk flash -kb sofle/rev1 -km default`). Use the reset button to reset the keyboard when you are asked to in console. 
- Connect the second half and flash it in the same way as the previous one.
- Disconnect the USB cable. Connect both halves together with TRRS cable.
- Connect USB cable to the **left** side[^2]. 
- Enjoy SofleKeyboard!

## Troubleshooting

### Elite-C v3.0

Elite-C v3.0 had problems when used with split boards (on both halves). Those are fixed in version 3.1. For v3.0 add `#define SPLIT_USB_DETECT` to `config.h` file. I don't have Elite-C so this is untested, but should work.

### Typing lag when used without OLED 

If you chose to not use OLED for both halves you should disable support for oled (set `OLED_DRIVER_ENABLE` to `no` in `keymaps/defualt/rules.mk`).

If you don't use OLED only on one half you are need to do **one** of the following to fix the lag:

- Solder pull-up resistors (4k7) to the PCB (R1, R2) without OLED.
- Use a workaround explained [in this issue][nooledlag].
- Stop using OLED completely and turn it off as described above.

## Modifications

### Inverted silkscreen

If you fancy an [inverted silkscreen there's a great guide available](https://github.com/josefadamcik/SofleKeyboard/issues/3#issuecomment-683192038).

## Links

- [Github with KiCad projects][soflegithub]
- [Layout in KeyboardLayout editor][soflelayout]
- [QMK Firmware][qmk_firmware]
- [QMK Configurator][qmk_configurator]

## Footnotes

[^1]: Serial is the default behaviour. If serial is used, you don't need TRRS cable (4 contacts, used for headphones with a microphone) but just TRS (stereo audio jack). 
[^2]: This can be changed, look for [setting handednesss][qmkhandedness] in QMK documentation.
[^3]: There was a design issue where the cutout for the encoder is big enough only for the base of the encoder but not for its legs. That is perfectly ok when you build the board with MX switches since the plate sits above the legs. But for low profile Kailh Choc switches there's no longer any gap between plates. If you have unfixed plate (the problem was fixed in v1.1.) and wish to use an encoder, you'll need to file off a bit of PCB material to get the legs of encoder through (see the guide above).

[layoutarticle]: <https://josef-adamcik.cz/electronics/in-search-of-the-best-custom-keyboard-layout.html> "In search of the best custom keyboard layout"
[introductionarticle]: <https://josef-adamcik.cz/electronics/let-me-introduce-you-sofle-keyboard-split-keyboard-based-on-lily58.html> "Let me introduce you SofleKeyboard - a split keyboard based on Lily58 and Crkbd"
[soflelayout]: http://www.keyboard-layout-editor.com/#/gists/76efb423a46cbbea75465cb468eef7ff "Sofle Keyboard layout at keyboard-layout-editor.com"
[soflegerber]: https://github.com/josefadamcik/SofleKeyboard/releases "SofleKeyboard - gerber files"
[qmk_firmware]: https://github.com/qmk/qmk_firmware/ "QMK firmware"
{:target="_blank"}
[qmk_configurator]: https://config.qmk.fm/#/sofle/rev1/LAYOUT "QMK configurator"
{:target="_blank"}
[springpinheader]: <https://yushakobo.jp/shop/a01mc-00/> "Spring pin headers - Japaneese"
{:target="_blank"}
[qmkprotonc]: https://qmk.fm/proton-c/ "QMK Proton-C"
{:target="_blank"}
[promicrosocketing]: <https://docs.splitkb.com/hc/en-us/articles/360011263059> "How do I socket a microcontroller? by splitkb.com"
{:target="_blank"}
[qmkintro]: <https://beta.docs.qmk.fm/tutorial/newbs_getting_started> "QMK getting started"
{:target="_blank"}
[qmkhandedness]: <https://docs.qmk.fm/#/feature_split_keyboard?id=setting-handedness> "QMK firmware - setting handedness"
{:target="_blank"}
[manufacturingproblems]: https://josef-adamcik.cz/electronics/corne-keyboard-build-log.html#manufacturing-at-jlcpcb---update-27112019 "Possible problems when manufacturing top plate for Corne"
[nooledlag]: https://github.com/qmk/qmk_firmware/issues/7522 "No OLED lag bug"
[soflegithub]: https://github.com/josefadamcik/SofleKeyboard "SofleKeyboard - KiCad project on Github.com"
[sourcing]: <{{ site.baseurl }}/sourcing_parts.html> "Sourcing parts"
[rgbbuildguide]: <{{ site.baseurl }}/build_guide_rgb.html> "Sofle RBG build guide"

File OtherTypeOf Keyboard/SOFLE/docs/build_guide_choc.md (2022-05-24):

---
layout: default
title: Sofle Keyboard - build guide (Choc)
---

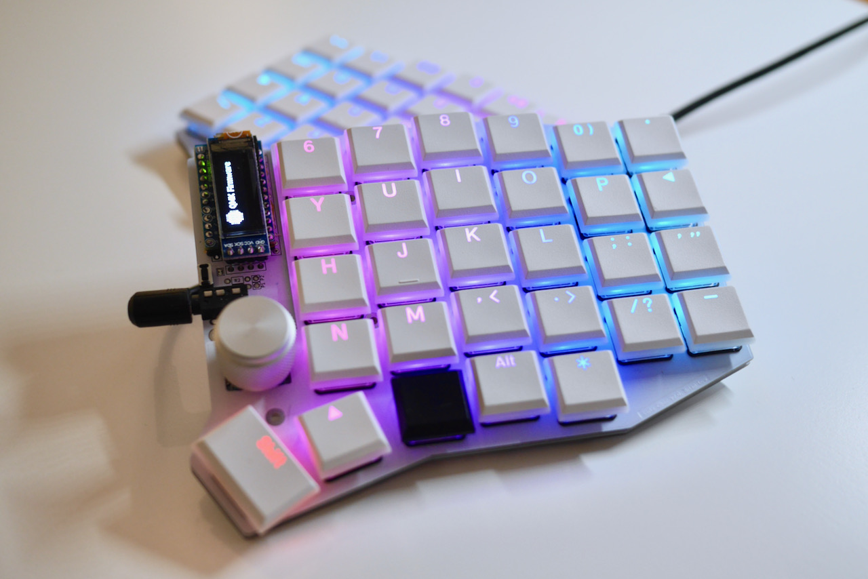
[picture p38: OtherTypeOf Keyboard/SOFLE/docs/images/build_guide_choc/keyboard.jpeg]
Keyboard

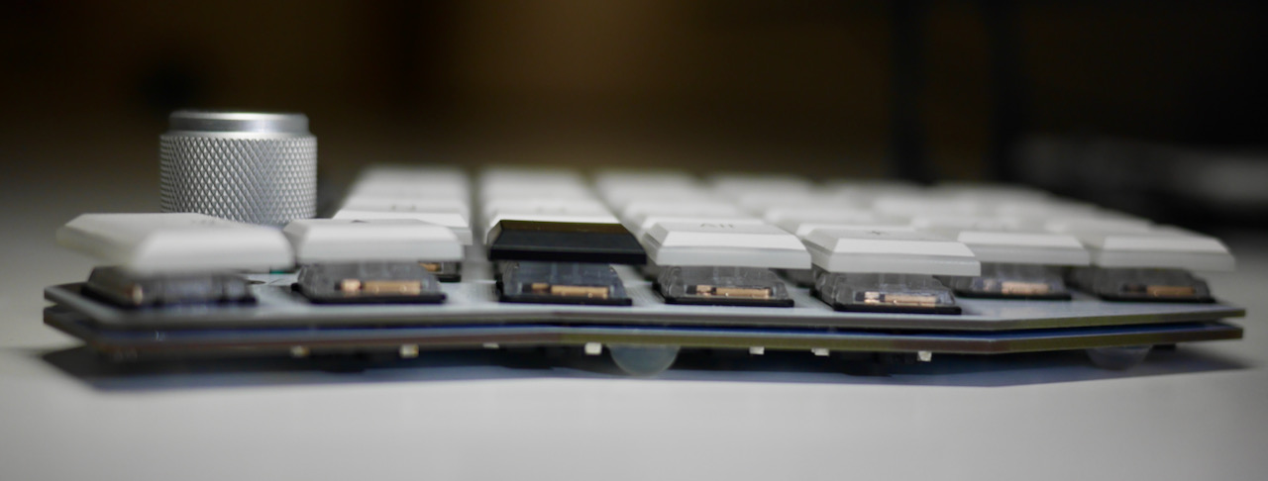
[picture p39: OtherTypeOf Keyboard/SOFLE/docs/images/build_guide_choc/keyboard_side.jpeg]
Keyboard Side View


The Sofle Choc is a variation of the Sofle with:

   - low-profile, Kailh Choc switches
   - hotswap sockets
   - per-key RGB
   - thin, 15mm from desktop to top of keycaps
   - Sofle RGB switch layout with pinky stagger in between v1 and v2

This version supports [Kailh Choc v1 switches](https://deskthority.net/wiki/Kailh_PG1350_series). Kailh hotswap sockets are required. Per-key RGB is optional and uses the relativey easy to solder SK6812 MINI-E LEDs.

The top plates are not compatible with Sofle v1, v2 or RGB versions. There is no bottom plate to minimize thickness.

The Sofle Choc was designed by [Brian Low](https://github.com/brianlow) and based on the excellent Sofle RGB by [Dane Evans](https://github.com/DaneEvans) which was based on the original Sofle v2 by [Josef Adamčík](https://github.com/josefadamcik).

## Updated Build Guide and Kits

I am maintaining a newer version of the build guide and usually have kits available at:

[http://choc.brianlow.com](http://choc.brianlow.com)

## Bill of materials

The following is needed to build the keyboard:

- **2 PCBs**. Send the zip from `/Gerbers/Choc_v2/choc-v2-gerber-pcb.zip` to a PCB fabrication service. The PCB should be 1.6mm thick [though 1.2mm may be better](https://github.com/josefadamcik/SofleKeyboard/issues/136#issuecomment-1045965676). Otherwise I used JLCPCB's default settings only customizing the PCB color. See [sourcing][sourcing].

- **2 top plates**. Send the zip `/Gerbers/Choc_v2/choc-v2-gerber-top.zip` to a PCB fabrication service. The top plate holds the switches in place. The top plate should be 1.2mm thick. Otherwise I used JLCPCB's default settings only customizing the PCB color. See [sourcing][sourcing].

- **2 Pro Micro** boards or clones. 5v, 2x12 pins, ATmega32U4 microcontroller. **Don't** buy the Arduino Micro (a different pinout) or Arduino Mini (different microcontroller). You could also use Elite-C which basically Pro Micro with USB-C.

- **4x 12 pin headers (and optional sockets)** for Pro Micros. There are several ways to mount Pro Micros to the board. The male pin headers you most likely got with the board can be used to solder it directly to the board. This makes it hard to replace the board if it fails. The micro-USB connector is known to tear off. I socketed the Pro Micro using the diode legs approach [described at splitkb.com][promicrosocketing] with two 12-pin female headers. This is the option descibed in the build guide here. Lastly, [these spring pin headers][springpinheader] are used on similar keyboards and should give a compact, non-permanent connection but have been out of stock for a long time.

- **58 Kailh Choc keyboard switches**. Must be [Kailh Choc v1 switches (PG1350)](https://deskthority.net/wiki/Kailh_PG1350_series) of any color. The `PG` prefix is often omitted. **Don't** buy [Kailh Choc v2](https://deskthority.net/wiki/Kailh_PG1353_series), [Kailh Mini Choc](https://deskthority.net/wiki/Kailh_PG1232_series) or [Cherry MX](https://deskthority.net/wiki/Cherry_MX).

- **58 Kailh Choc keyboard switch sockets**. Sockets are specific to the PG1350 switch. The PCB requires sockets. Switches cannot be soldered directly to the board.

- **58 keycaps**. You can use either all in `1u` size but it looks nicer with two `1.5u` for the thumb keys.

- **58 diodes 1N4148W**. Surface mount diodes in SOD123 package. Pick any common variation. I used `1N4148WTR` (Digi-Key 1655-1360-1-ND).

- **2 TRRS connectors**. The same type which is used for Corne, Lily58 etc. Technically even TRS should work if you stick to the default serial communication.

- **2 buttons** momentary, tactile, through-hole, 2 pins, I used one for DIP switches, 3x6x4.3mm. Technically optional: you can use metal tweezers whenever you need to reset the microcontroller.

- **1 TRRS cable**. TRS should work if you stick with the default serial communications.

- **8 - 10 silicone bumpers**. Used for feet to keep the keyboard from moving

- **Micro USB Cable** to connect the keyboard to a computer.

Optional components:

- **OLED/s**
  - **2 SSD1306 128x32 OLED display module**. 4-pin, I2C, 0.91". Very common.
  - **2x 4 pin header (and optionally socket)** for OLEDs. These came pre-soldered to the OLED unit. You can solder the OLED directly to the board. Ideally use a socket so you can replace and/or get at the ProMicro underneath. I found 4 pin female headers with half height (~4mm) insulation worked well
  - **2 OLED covers** This should be compatible with the Sofle RGB cover but have not verified

- **Rotary encoders**
  - **2 Rotary encoders EC11**. If you are not sure take EC11E. Some other variants (EC11K) may have some additional plastic pins for and require mounting holes for them which are not included on the PCB. Perfer short shaft. I used encoders with 10mm, D-shaped shaft and 30 positions from AliExpress. I also tried a high quality Bourns encoder (PEC11 series) but found it required a bit too much effort to twist.
  - **2 matching knobs** for each encoder. Make sure the knob matches the encoder's shaft diameter, depth and shape.
  - **2 diodes 1N4148W** the encoder shafts are pushable and can be used as configurable keys.

- **LEDs**
  - **58 SK6812 MINI-E RGB LEDs**. The LED body 3.2x2.8x1.7mm and with legs is 5.8x2.8. Avoid the non-MINI-E version without the legs. Purchase extra as they are delicate. I ended up replacing 6 during my build.

- **Resistors**
  - **2x 4.7kOhm through hole resistors** These only needed if you want to use the less common I2C communication protocol between halves. They are installed in the R1/R2 spots. I have not tested an I2C setup. The firmware on this page uses serial communication and does not require the resistors.

Components that are common on other Sofle variants but are **not** used on this Softle Choc: bottom plate, M2 spacers and screws.

## Tools and materials

- soldering iron and solder
- no-clean flux makes soldering easier
- solder wick or desoldering pump to correct mistakes
- good tweezers
- flush cutters to trim diode legs when socketing the ProMicro
- masking, kapton or electrical tape
- isopropyl-alcohol for cleaning
- screwdriver
- 1.5mm hex key for the set screw on the encoder knob
- mulitmeter for troubleshooting

## Steps

### Prepare

Make sure you know which side you are working on, and don't make two left hand sides by mistake. Stick a piece of tape on the front side of both PCBs to help remember.

This guide is written in the order I like to install components.

We will start with the components on the back, shortest to tallest:
  - diodes
  - LEDs
  - switch sockets

Then install the components on the front:
  - OLED jumpers
  - ProMicro & socket
  - OLED & socket
  - reset switch
  - TRRS connector
  - encoder

The order of assemby does not matter **except** for these 3 components because they stack on top of one another:
  1. the four OLED jumpers
  2. the Pro Micro
  3. the OLED screen

The build guides for the Sofle and Sofle RGB have some good tips and photos. However there are differences so use this page as your primary reference. In particular, use the ProMicro orientation described on this page.

### Switch Sockets and Diodes

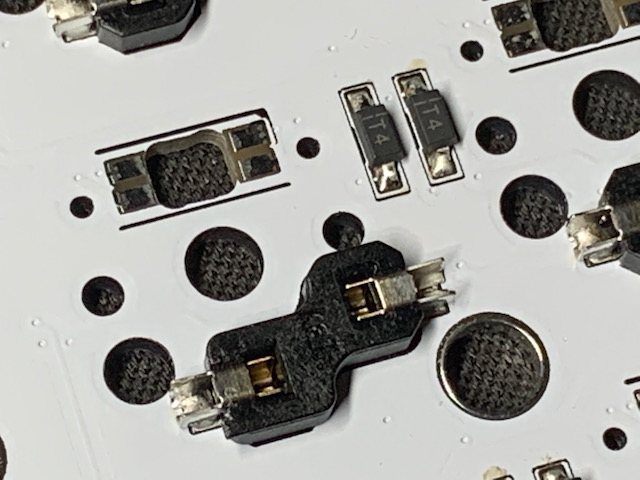
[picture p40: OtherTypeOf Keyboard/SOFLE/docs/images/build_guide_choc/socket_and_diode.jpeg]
Switch sockets and diodes


These components are placed on the back of the PCB.

Diodes must be oriented with the white band in the direction of the "arrow" symbol on the PCB. I typically tin one pad, place the diode on, apply the soldering iron to the diode leg until it melts the solder underneath and sinks flush with the PCB. Then come back and solder the other leg.

The sockets are the largest and easiest to solder. They are installed on the back of the PCB facing up towards the front of the PCB. Make sure they are flush with the PCB. Heat the metal connector, apply solder and look for the solder to wick down to the PCB. You want a solid joint since this may take some mechanical strain from switch installation and removal.

### The LEDs

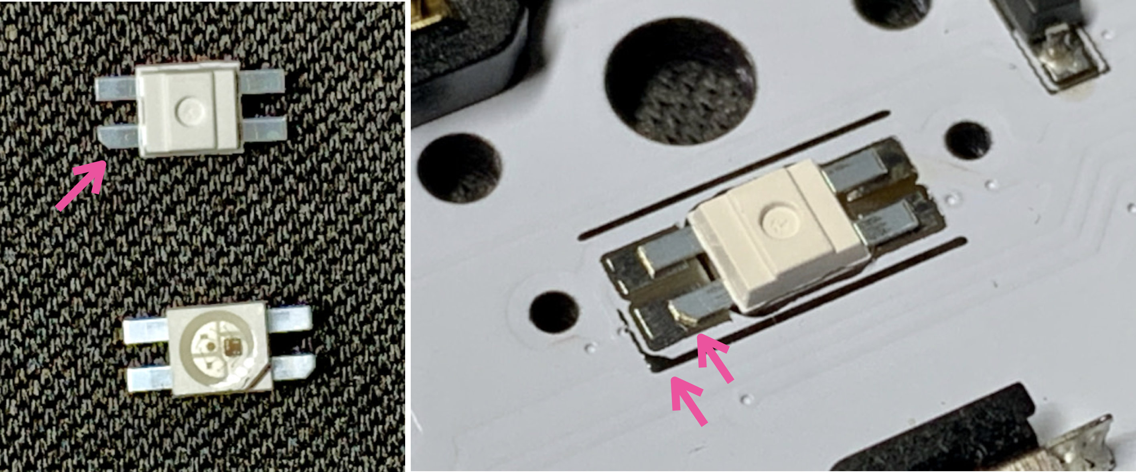
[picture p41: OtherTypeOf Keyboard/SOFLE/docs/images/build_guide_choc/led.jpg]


LEDs are placed on the back of the PCB. The lens should point up through the PCB so they shine into the bottom of the switch. One leg will have a diagonal cut. This cut leg should be aligned with the triangular marking on the PCB.

To solder: tin one pad, place the LED and hold using tweezers, apply heat to the leg until the solder melts and the LED is flush with the board. Now the remaining legs can be soldered without the component moving. The LEDs are sensitive to heat. Let the LED cool between soldering each leg. Use the lowest heat needed for your solder.

The LEDs are wired in one long chain. If a LED is not working, replace the LED and the LED preceeding it. Sometimes just the output of a LED is damaged. The full chain does not need to be installed if you want to test a partially built board.

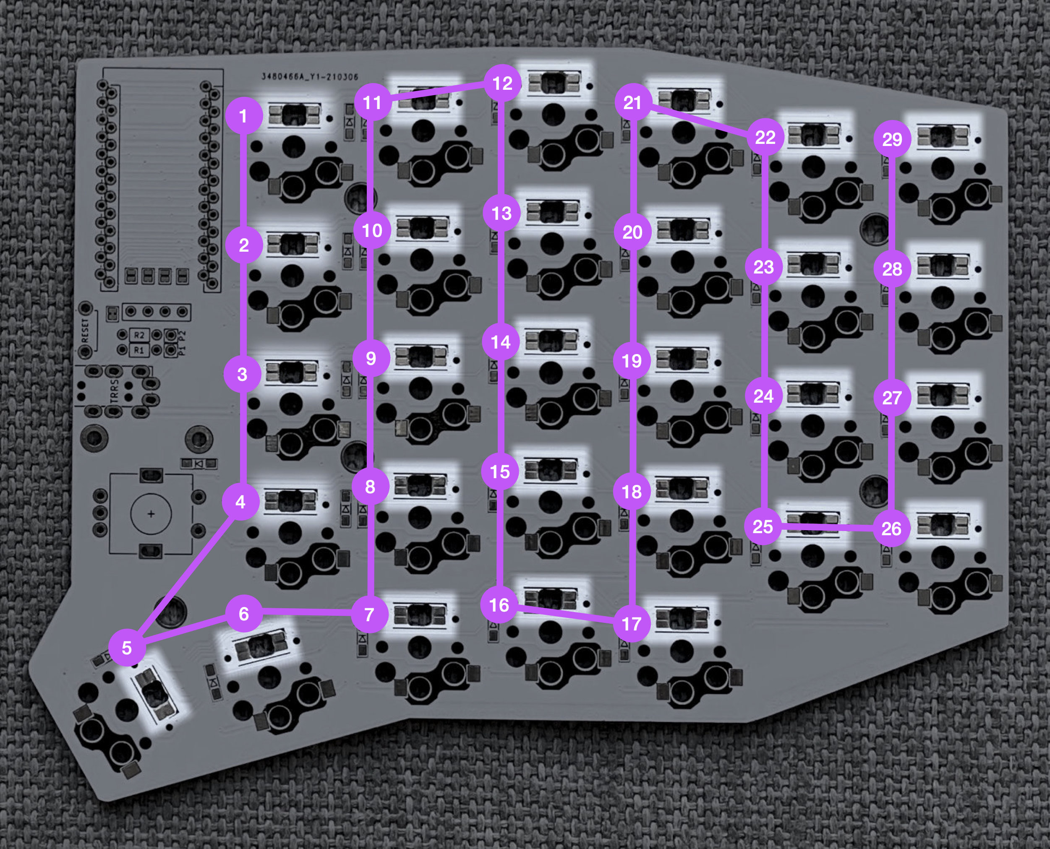
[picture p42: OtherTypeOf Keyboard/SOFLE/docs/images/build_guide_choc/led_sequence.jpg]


### OLED Jumpers

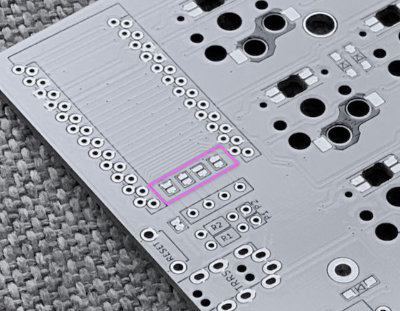
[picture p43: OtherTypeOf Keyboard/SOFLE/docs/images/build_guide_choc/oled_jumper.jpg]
OLED Jumpers


Now we move to the front of the PCB.

The jumpers in the photo should be bridged if using an OLED dispay. The jumpers may not be accessible later in the build depending on how the Pro Micro is attached. Bridge the jumpers on the top side of the board, the same side the ProMicro will be mounted on.

### Pro Micro

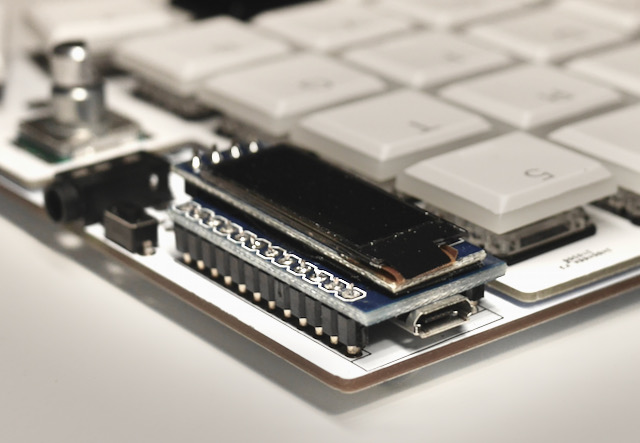
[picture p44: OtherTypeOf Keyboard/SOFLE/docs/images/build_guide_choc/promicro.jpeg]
Pro Micro


The Pro Micro is installed on the top of the board, upside down and in the marked holes.

* Top of the board: this is the side of the PCB opposite the diodes, LEDs and switch sockets
* Upside down: both Pro Micro components should face the PCB with the mostly plain back facing out
* Marked holes: there are two sets of holes in the PCB, use the holes with the rectangular outline on the top of the board

Double-check your work here. This step is hard to reverse if a mistake is made.

To install a socketed Pro Micro using the diode leg approach [from splitkb.com][promicrosocketing]:

  1. Install the 12-pin female headers on the top of the board in the outlined through holes. Use some tape to temporarily tack them in place. Flip the board over onto a flat, hard surface. While soldering the first pins, push down on the PCB to ensure the headers are perpendicular and fully seated.

  2. Flip the board upright again. Optionally place some tape over the sockets to protect against fusing parts together. Place the Pro Micro upside down on top. Push diodes though the Pro Micro holes, through the tape and seated into the socket below.

  3. Solder the legs to the Pro Micro. Snip off the legs above the Pro Micro.

If you ever need to remove the Pro Micro: do it by gently prying the board up in small increments, working your way around the board. Avoid pressure on the USB connector. The diode leags are quite weak and will usually bend if you pull the Pro Micro off in one action.

### OLED

Install the OLED so it overhangs the Pro Micro. I added electrican's tape to the bottom of the OLED module where it might contact the Pro Micro.

If you are socketing the OLED, install the 4 pin, half height female header on the top of the PCB. Then push the OLED pins into the socket. You may need to trim the OLED pins so the insulation on the female and male headers mate and the OLED sits just above the Pro Micro. The downside to socketing is the OLED isn't as secure in the half height socket. When turning the keyboard upside down I find the OLED will lever away from the Pro Micro somewhat.

### Solder misc components

Use tape to tack each component in place while flipping the board over to solder.

Solder the reset switch.

Solder the TRRS connector. You may need to bend the TRRS connector pins 90 degrees so they point down into the PCB. The R1 and R2 locations should remain empty.

Solder the encoder.

### Assemble

- Snap a few switches into the top plate, the corner switches work best

- Place the PCB on a flat surface. This will save some strain on the solder joints in the next step (though they should be able handle it).

- Carefully lower the top plate with switches on the main PCB and push into sockets. Ensure pins are aligned.

- Snap the remaining switches into the top plate pressing into the sockets.

- There are no standoff between the PCB and top plate

- Place the encoder knob on the shaft. Tighten the set screw with a hex key. A small screwdriver for glasses may do in a pinch.

- Optionally add oled covers

- Put at least 4 adhesive rubber feet in the corners so the keyboard is not moving when you type.

## Warnings and disclaimers

- Don't connect or disconnect the TRRS cable when the keyboard is powered. It may short out. Always disconnect the USB cable first.
- Be gentle with micro USB ports on your microcontrollers. They are easy to break.
- Keep in mind that this is a prototype of a DIY keyboard. It's not a polished product.

## Firmware and programming

The Sofle Choc uses [QMK Firmware][qmk_firmware]. Support is not in the main QMK repository [yet](https://github.com/qmk/qmk_firmware/pull/16736). Instead use the [brianlow/qmk_firmware](https://github.com/brianlow/qmk_firmware) fork.
Suggested approach is to build the firmware yourself. You should be familiar with QMK and be able to make it work on your local environment. If not, please [follow the instructions in the documentation][qmkintro]. Note QMK setup is fairly invasive (upgrade every homebrew package on your system) so you might want to consider the [QMK Docker image](https://beta.docs.qmk.fm/using-qmk/guides/development-environments/getting_started_docker) for compiling.

To flash:

- Clone [https://github.com/brianlow/qmk_firmware](https://github.com/brianlow/qmk_firmware)
- Switch to the `choc2` branch with `git checkout choc2`
- Make sure your QMK environment [is setup][qmkintro].
- Make sure halves are not connected together with TRRS cable.
- Connect one half to USB, flash the firmware (always follow the current instructions in the QMK documentation! The command might look something like this: `qmk flash -kb sofle_choc -km default`). Use the reset button to reset the keyboard when you are asked to in console. Some Pro Micros require double-clicking the reset button to enter bootloader mode.
- Connect the second half and flash it in the same way as the previous one.
- Disconnect the USB cable. Connect both halves together with TRRS cable.
- Connect USB cable to the **left** side.
- Enjoy SofleKeyboard!

There is also a firmware version that uses [VIA](https://caniusevia.com/). VIA allows you to quickly change your keymap without flashing or a QMK build environment. I highly recommend it for experimenting. There are few downsides:
- it doesn't support custom logic like a key for switching betwen Mac/Win
- the exporting/importing keymaps has some problems with some multi-chord keys though typically I don't find I need to export/import
- lighting configuration keys only seem to affect lighting on the master side. If you don't change lighting much, a workaround is to plug just the right side in to the computer, change the lighting then plug everrything back normally

To use the VIA firmware

- Clone https://github.com/brianlow/qmk_firmware
- Switch to the `choc-brian` branch with `git checkout choc-brian`
- When flashing use the `choc_brian` keymap: `qmk flash -kb sofle/rev1 -km choc-brian`
- Download the VIA app from https://caniusevia.com/, it should recognize the keyboard when it opens

## Troubleshooting

See the Sofle build guide.

## Links

- [Github with KiCad projects][soflegithub]
- [Layout in KeyboardLayout editor][soflechoclayout]
- [QMK Firmware][qmk_firmware]
- [QMK Configurator][qmk_configurator]

## Default layout

The default layout for the Sofle Choc is in the QMK fork and demonstrates some LED functions.

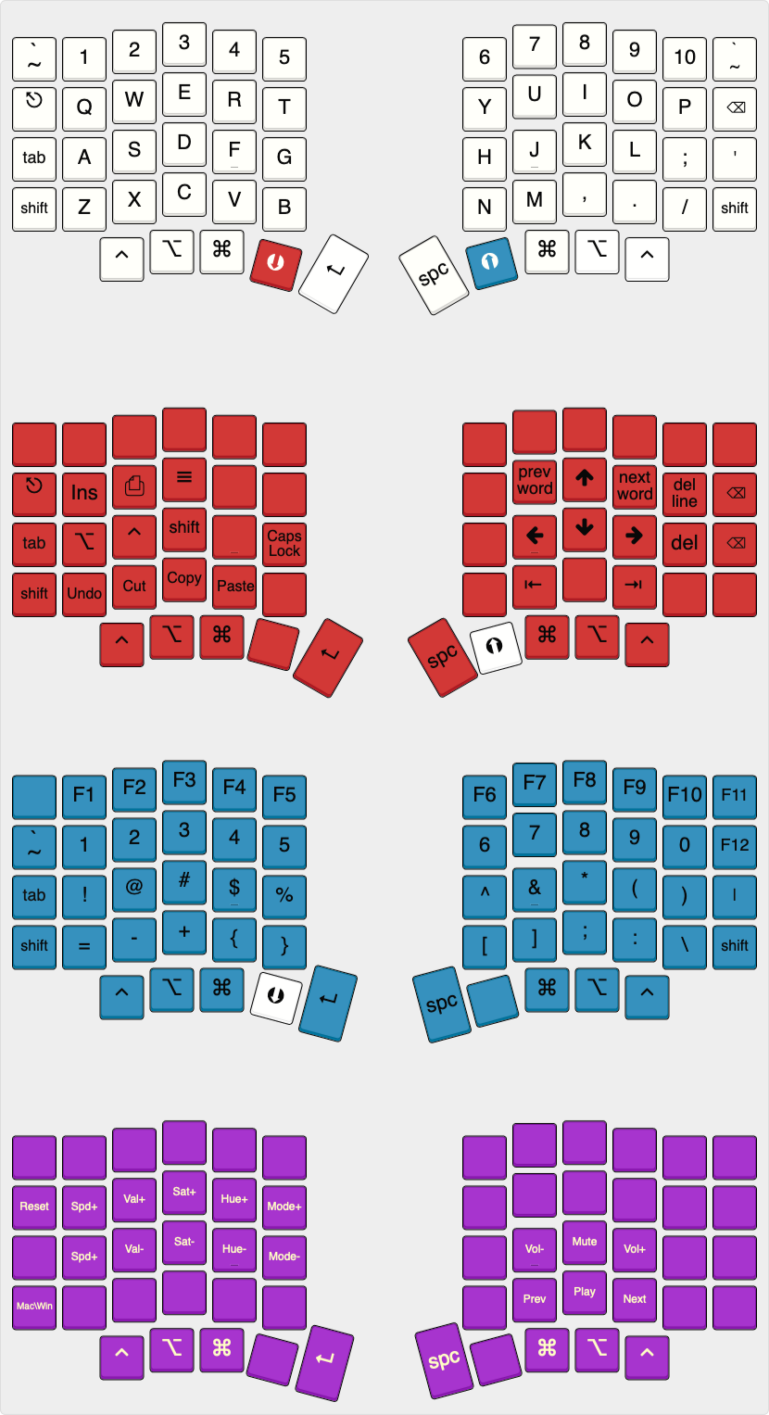
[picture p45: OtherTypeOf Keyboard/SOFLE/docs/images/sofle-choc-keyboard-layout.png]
Default layout for Sofle Choc Keyboard


## Images of keyboard

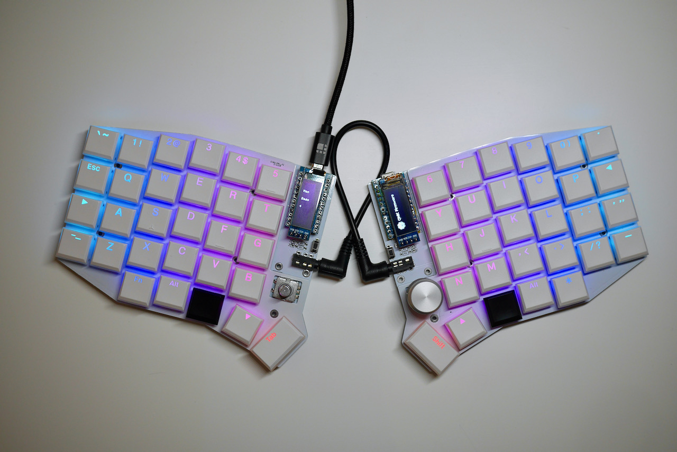
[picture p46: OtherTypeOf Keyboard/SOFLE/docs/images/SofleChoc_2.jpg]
Keyboard Photo 1


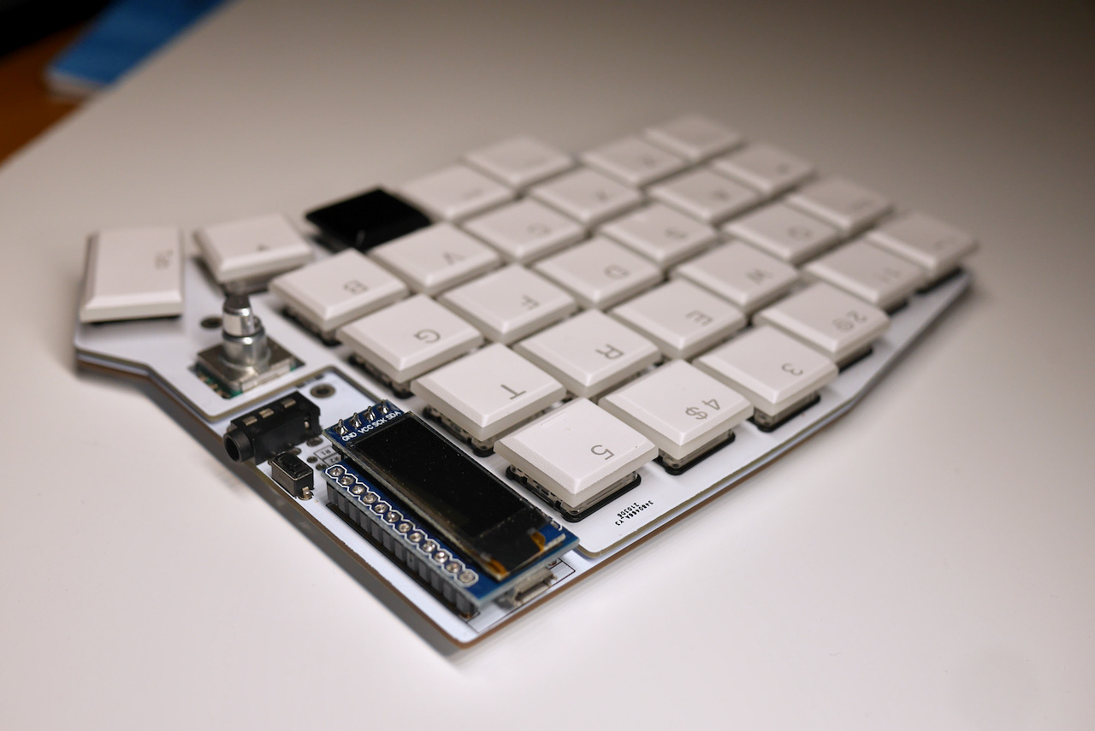
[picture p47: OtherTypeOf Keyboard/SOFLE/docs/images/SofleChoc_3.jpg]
Keyboard Photo 2


## Version History

* v2.1.1 - Top plate: moved the version label to less visible location, widened the area above the encoder. PCB version remains at v2.1
* v2.1 - First published version

## Footnotes
[layoutarticle]: <https://josef-adamcik.cz/electronics/in-search-of-the-best-custom-keyboard-layout.html> "In search of the best custom keyboard layout"
[introductionarticle]: <https://josef-adamcik.cz/electronics/let-me-introduce-you-sofle-keyboard-split-keyboard-based-on-lily58.html> "Let me introduce you SofleKeyboard - a split keyboard based on Lily58 and Crkbd"
[soflelayout]: http://www.keyboard-layout-editor.com/#/gists/76efb423a46cbbea75465cb468eef7ff "Sofle Keyboard layout at keyboard-layout-editor.com"
[soflechoclayout]: http://www.keyboard-layout-editor.com/#/gists/5604075ad16c10a8c634828c5911d2b6 "Sofle Choc Keyboard layout at keyboard-layout-editor.com"
[soflegerber]: https://github.com/josefadamcik/SofleKeyboard/releases "SofleKeyboard - gerber files"
[qmk_firmware]: https://github.com/qmk/qmk_firmware/ "QMK firmware"

[qmk_configurator]: https://config.qmk.fm/#/sofle/rev1/LAYOUT "QMK configurator"
[springpinheader]: <https://yushakobo.jp/shop/a01mc-00/> "Spring pin headers - Japanese"
[qmkprotonc]: https://qmk.fm/proton-c/ "QMK Proton-C"
[promicrosocketing]: <https://docs.splitkb.com/hc/en-us/articles/360011263059> "How do I socket a microcontroller? by splitkb.com"
[qmkintro]: <https://beta.docs.qmk.fm/newbs/newbs_getting_started> "QMK getting started"
[qmkhandedness]: <https://docs.qmk.fm/#/feature_split_keyboard?id=setting-handedness> "QMK firmware - setting handedness"
[manufacturingproblems]: https://josef-adamcik.cz/electronics/corne-keyboard-build-log.html#manufacturing-at-jlcpcb---update-27112019 "Possible problems when manufacturing top plate for Corne"
[nooledlag]: https://github.com/qmk/qmk_firmware/issues/7522 "No OLED lag bug"
[soflegithub]: https://github.com/josefadamcik/SofleKeyboard "SofleKeyboard - KiCad project on Github.com"
[sourcing]: <{{ site.baseurl }}/sourcing_parts.html> "Sourcing parts"

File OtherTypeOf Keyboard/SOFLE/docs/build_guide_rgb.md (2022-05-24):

---
layout: default
title: Sofle Keyboard - build guide (RGB)
---

The Sofle RGB is a copy of the Sofle V2 with the addition of up to 36 RGB leds per side. If you are just looking to try out that layout, and are using the cherry sockets only, then this will work for you. Please mind that the layout has slight modifications, mainly the pinkie stagger is less aggresive than for non-RGB Sofle V2.

This version rolls back the original pro-micro pinout (to the state it was for V1) and improves routing.

## This Build Guide

This build guide is based on a copy of the main [build guide][buildguide]. We suggest to revisit the main [build guide][buildguide] for general process and tips about technique. But this build guide is the main source of important details for your build - like Pro-Micro orientation, component placement etc.

**&#9888; Keyhive version: Pay attention, if you purchased Sofle RGB from Keyhive**

One keyboard vendor - Keyhive - is selling their own fork of Sofle RGB. This version is **modified** in way that makes it **incompatible** with the **firmware** for the official designs. Also this build guide no longer applies to their version. 

**&#9888; If you purchased their modified version, you have to use the firmware provided by the vendor and [the build guide provided by them as well][keyhivebuildguide].**

Please, don't report problems with the design by Keyhive and or firmware to the official Sofle Keyboard repository. Their modification is not part of the repository and therefore we can't fix any problems and we can't help with any problems you might have with the design. Contact the vendor instead. In the end, you are their client.

## Bill of materials

The following is needed to build the keyboard.

- **2 PCBs**, ** NOTE: ** There is an issue with the v2.0 boards. See the Troubleshooting section at the bottom of the page for further details if you were unlucky enough to get a board made with these files. 
- **2 top plates**, **2 bottom plates** for a sandwich-case build.

- **2 Pro Micro** board or clone. With 2x12 pins and ATmega32U4 microcontroller. Just make sure you **don't** buy something like Arduino Micro (a different pinout) or Arduino Mini (different microcontroller). You could also use Elite-C which basically Pro Micro with USB-C.
- **4x12 pin header (and optionally socket)** for Pro Micros. There are several ways how to mount Pro Micros to the board. Either the male PIN headers you most likely got with the board from the supplier could be used to solder it directly to the board. Build guides for Helix, Corne and Lily58 suggest [those spring pin headers][springpinheader] which are very compact and give you non-permanent connection (you can remove or replace Pro Micros). Another possible approach [is described at splitkb.com][promicrosocketing].

- **58 keyboard switch sockets by Kailh**. The PCB supports sockets for traditional MX switches. They are available on Aliexpress, KBDFans and others.
- **58 keyboard switches** of your preference, MX. Just make sure you have matching sockets for them.
- **58 keycaps**. You can use either all in `1u` size but it looks nicer with two `1.5u` for the thumb keys.
- **58 diodes  1N4148W**. They are surface mount diodes in SOD123 package.
- **2 TRRS connectors**. The same type which is used for Corne, Lily58 etc. Technically even TRS should work[^1] if you stick to (default) serial communication. 
- **2 tactile buttons** through-hole, 2 pins. Technically optional: you can use metal tweezers whenever you need to reset the microcontroller. There's also a reset key on default layout so as long as you have firmware flashed and working you shouldn't need reset button on the board. 
- **1 TRRS cable**. TRS should work if you stick with Serial. 
- **10 (+4) M2 spacers**. 10 are going to hold the bottom and the top together. Their height depends on which switches you use. A build guide Lily58 Pro suggests  `7mm` for MX. I was not able to get `7mm`, but `6mm` worked well for me with MX switches. I used brass ones but you can also buy nicer from anodised aluminium. 
- **20 (+8) M2 screws**. 20 are going to hold the boards together (via spacers). I used some I had in my stock so I am not going to tell you exact length. But they need to be long enough to fix a `1.6mm` thick PCB to the spacer and short enough so two of them can fit in one spacer (might be trickier with 4mm spacers for Choc switches)
- **8 - 10 adhesive rubber feet**. They are really important, trust me.
- **Micro USB Cable** to connect the keyboard to a computer.

**Optional**
- **OLED/s**
	- **2 ssd1306 128x32 OLED display module**. Very common everywhere. 
	- **2x 4 pin header (and optionally socket)** for OLEDs. I have used the most common 1x4 female pin sockets which are quite tall but they also fit the height of ProMicro with the sockets I have used. Unfortunately, the pin headers on my OLED modules (again those very common square male headers you would get with the modules) are loose in the sockets. It works but it's fiddly. I'll have to find a better solution.
	- **2 OLED cover** This is available in [the repository (oled_cover.svg)](https://github.com/josefadamcik/SofleKeyboard/tree/master/Sofle_RGB/Case/)
	
- **Rotary encoders**
	- **2 Rotary encoders EC11**, If you are not sure take EC11E. Some other variants (EC11K) may have some additional plastic pins for and require mounting holes for them (which are not included on the PCB).
	- **A matching knob** for each encoder. 
	
- **LEDs**
	- **SK6812 mini rgb leds (3.5mmx3.5mm size)** make sure that you get the style with irregular shaped pads that are flush to the led, and make very sure that you know what the pinout for your variant is. There are at least  2 common pinouts, thankfully just rotated 180 degrees, but for you the pin 1 marking may be on pin 3.
		- **2x forward facing layer indicator**
		- **12x rear facing drop lights**
		- **58x per key lights** 

## Tools and materials

- soldering iron
- solder 
- good tweezers
- masking tape
- isopropyl-alcohol for cleaning
- screwdriver

## Steps

### Prepare

Make sure you know which side you are working on, and don't make two left hand sides by mistake 

### The LEDs
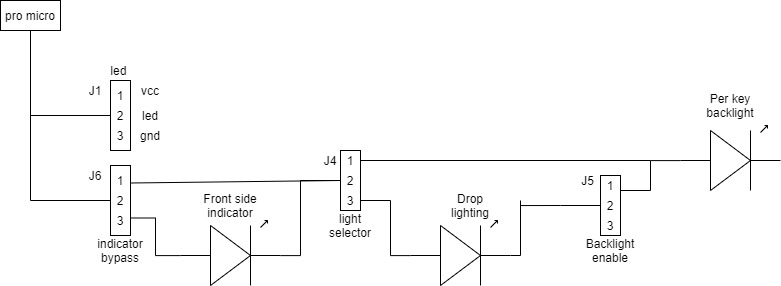
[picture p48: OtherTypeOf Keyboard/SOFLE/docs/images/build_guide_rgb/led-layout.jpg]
SofleKeyboard


Work out what leds you wish to have, I have endeavoured  to provide plenty of flexibility, and all led configurations are available using the headers available. If you wish to experiment, use 2.54mm headers and jumpers. If you know what you want, use a solder bridge to enable the leds required.  
The traditional LED header is available, and can be used alone, or theoretically fed back in to one of the other headers if so desired. 

Make sure you know which way around your leds are, different brands have different pin 1 positions. Thankfully it appears that the pad pattern underneath is consistent, so use it. I recommend doing one LED and testing it before continuing. This unfortunately suggests soldering the micro on first, despite it making the back side harder to solder. A good alternative would be to use an existing keyboard with leds to inject the signal and power through the LED header.

#### LED pinouts

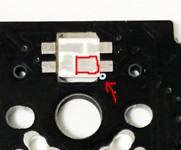
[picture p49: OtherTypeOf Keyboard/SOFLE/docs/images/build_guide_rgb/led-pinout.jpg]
LED pinout from the crkbd build guide. I've found this to be the only consistent method


The above picture is from the crkbd guide shows pin 4 on the table (the table is viewed from the top of the LED). 

**The sofle RGB uses the following table, with the silkscreen marking at pin 1 (Dout)**
| pin | net | net | pin |
| --- | --- | --- | --- |
| 1 | Dout | Vcc | 4 | 
| 2 | Gnd  | Din | 3 | 

Using the base pattern is the only consistent pattern between at least two different models with different pin 1 definitions and markings.

The following two datasheet excerpts show two versions of the led with different numbering pattern. But shows the same layout and net labels on the bottom.

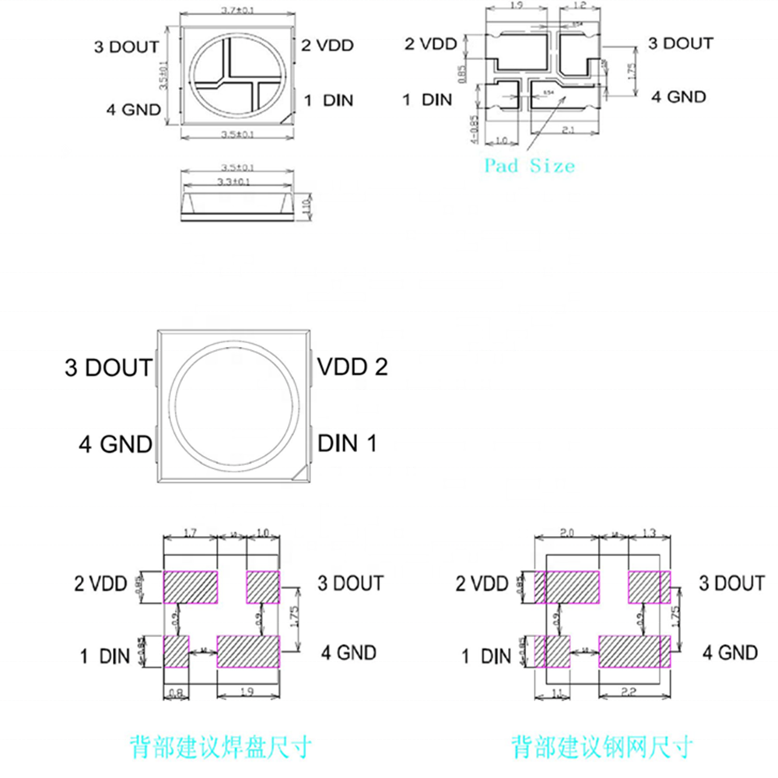
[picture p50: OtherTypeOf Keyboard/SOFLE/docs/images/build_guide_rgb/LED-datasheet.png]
datasheet


**Soldering** 

The surface mount LEDs are easier to solder, and there are only 1+6 of them on each side, so are a good place to start if you aren't used to soldering them. Use a fairly low temperature (240c) and lots of flux. Place the led in position, heat one of the pads on the board for several seconds before moving the iron to touch the pin on the led , then add solder. Moving the iron back and forth from the pin can help to flow the solder under the LED, 

I have added a single LED to the top surface to act as a layer indicator, this is enabled by bridging 2-3 on J6(indicator bypass).

To enable drop lighting, short pins 2-3 of J4(Light select), to enable only per key lighting short pins 1-2 of J4. 
If you wish to use per key lighting, you also need to short pins 1-2 of 5. 

| Indicator | Drop lighting | Per key 	| j6(Ind Bypass) 	| j4(Light select) 	|j5(Backlight) 	| 
| :---: | :---: | :---: | :---: | :---: | :---: |
|  N  |  N  |  N  | |	| |
|  N  |  N  |**Y**| 1-2 | 1-2 	| |
|  N  |**Y**|  N  | 1-2 | 2-3 	| |
|  N  |**Y**|**Y**| 1-2 | 2-3	| 1-2 |
|**Y**|  N  |  N  | 2-3 |	| |
|**Y**|  N  |**Y**| 2-3 | 1-2 	| |
|**Y**|**Y**|  N  | 2-3 | 2-3 	| |
|**Y**|**Y**|**Y**| 2-3 | 2-3	| 1-2 |

The per key lighting is painful and slow. For these it is definitely best to do them in order, and test regularly. Use as low a temperature as you can manage, place the board flat on a table, and drop an led in. Create a solder bridge from the led to the board, not spending too much time with the iron on the led (few seconds) otherwise it will burn out. 

If the part of the string stops working, resolder the last working one, and the first to fail, then if needed replace them. 

#### LED Layouts 
** Indicator + drop lighting  **
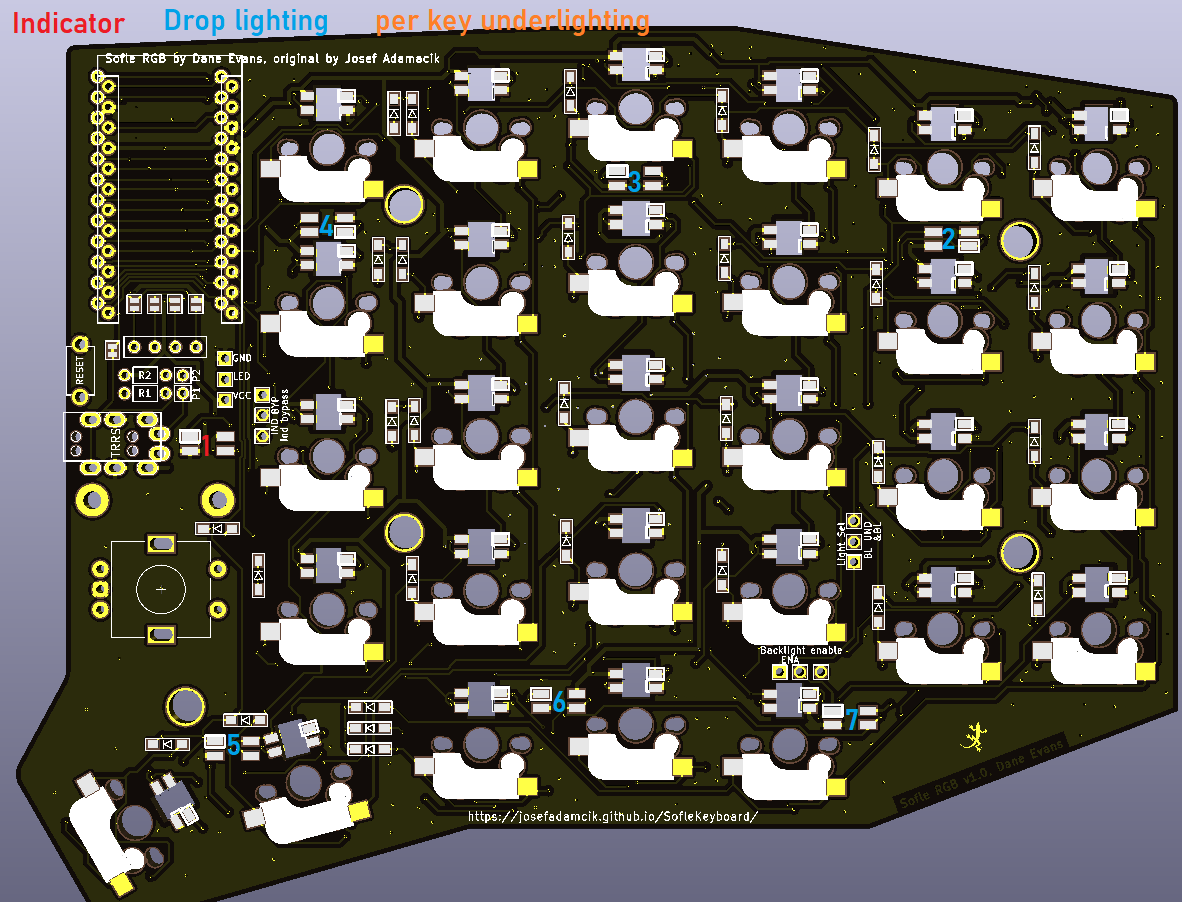
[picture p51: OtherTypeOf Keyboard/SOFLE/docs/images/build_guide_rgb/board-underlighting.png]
LED layout underlighting

** Indicator + per key lighting  **
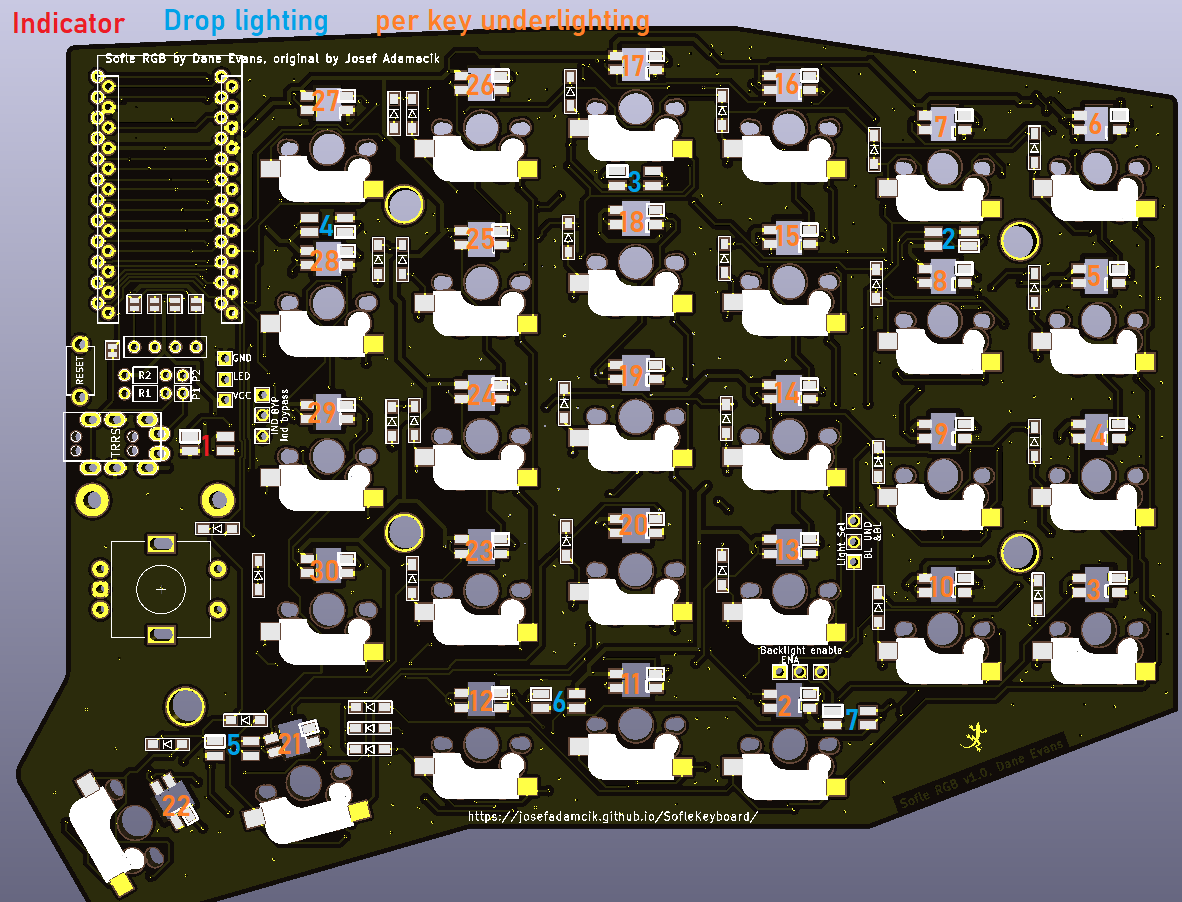
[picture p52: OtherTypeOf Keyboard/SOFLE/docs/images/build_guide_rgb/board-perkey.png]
LED layout per key

** Indicator + drop lighting + per key lighting **
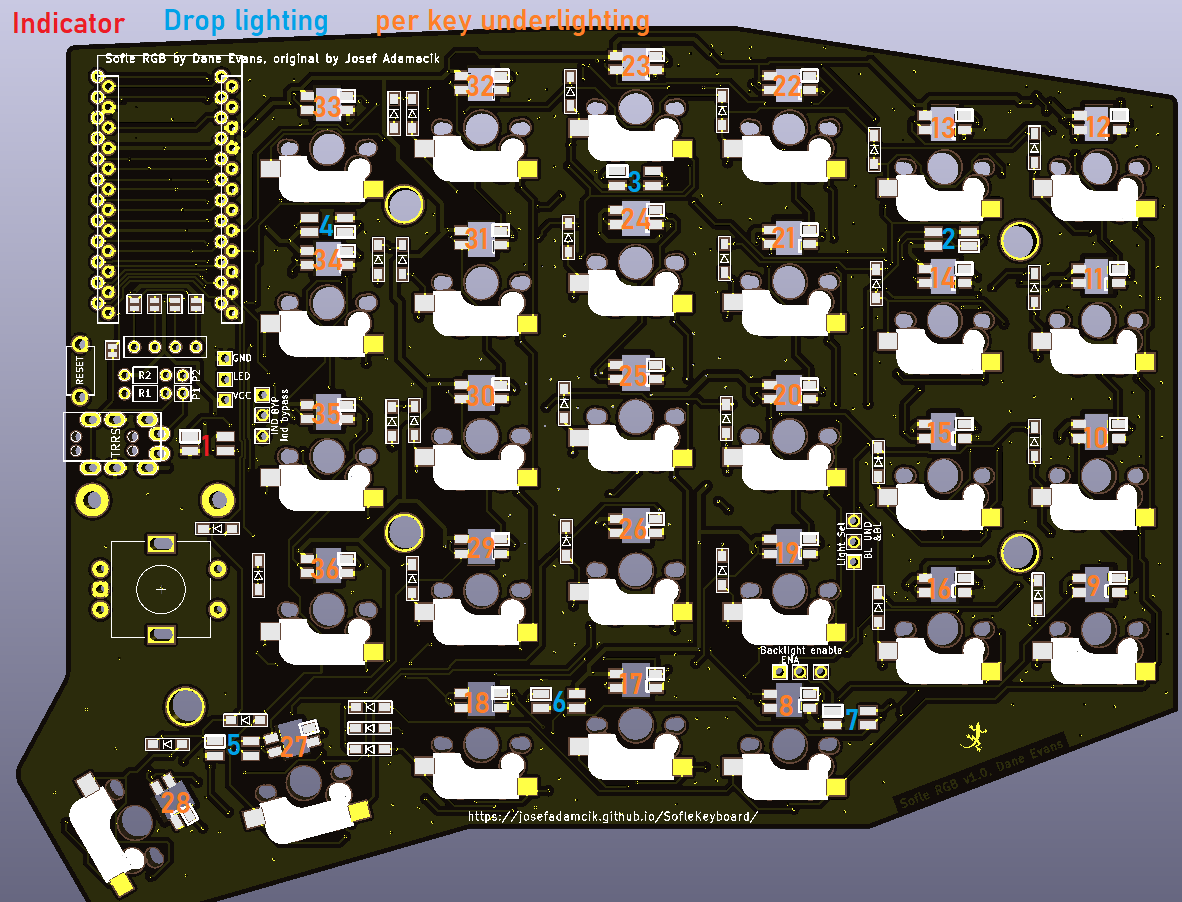
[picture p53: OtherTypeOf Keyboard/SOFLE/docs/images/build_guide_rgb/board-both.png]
LED layout both


### Components on the backside

- Start with the diodes. Make sure you have orientation right - they are all oriented to the same side. The end with the thin line is Cathode (-) and it should go in the direction of the "arrow" symbol on the PCB.

- Sockets for switches belong again on the back side, the same side as diodes. Make sure they are flush with PCB and match the orientation shown on the silkscreen. 

### Bridge the oled pads
This is done on the top side, all 4 solder bridges must be completed. This is easier before the pro micro headers are soldered 

### Components on the front side

- Button and TRRS sockets belong to the top. Use a piece of tape to fix them and apply solder from the bottom side.

### Pro Micro and displays

- The pro micro must be installed with the components facing the pcb, and the plain back side facing out. Theoretically I think these could be installed on the under side for a lower profile. 

Make sure that you use the outlined headers from whichever side of the board that you mount the micro on. 

- Install the oled so it sits over the pro micro 

### Rotary encoders

- Add rotary encoders last, they are big, and make soldering harder 

### Keyboard switches and plates

- Mount the stand-offs to the top plate.

- Snap first switches into corners of the plate.

- Carefully snap the first switches to the sockets. Be careful so you don't bend their contacts.

- Add the rest of the switches

- Mount the bottom plate.

### Finishing touches

- Install the rotary encoder knob.

- Optionally add oled covers

- Put at least 4 adhesive rubber feet in the corners so the keyboard is not moving when you type.

## Warnings and disclaimers

- Don't connect or disconnect the TRRS cable when the keyboard is powered. It may short out. Always disconnect the USB cable first.
- Be gentle with micro USB ports on your microcontrollers. They are easy to break.
- Keep in mind that this is a prototype of a DIY keyboard. It's not a polished product.

## Firmware and programming

Sofle keyboard uses [QMK Firmware][qmk_firmware] and support for the board is part of the main QMK repository. There's also a basic support in [QMK Configurator][qmk_configurator] but there's no encoder  or led support.

Suggested approach is to build the firmware yourself. You should be familiar with QMK and be able to make it work on your local environment. If not, please [follow the instructions in the documentation][qmkintro].

- Make sure your QMK environment [is setup][qmkintro].
- Make sure halves are not connected together with TRRS cable.
- Connect one half to USB, flash the firmware (always follow the actuall instructions in the QMK documentation! The command might look something like this: `qmk flash -kb sofle/rev1 -km rgb_default`). Use the reset button to reset the keyboard when you are asked to in console. 
- Connect the second half and flash it in the same way as the previous one.
- Disconnect the USB cable. Connect both halves together with TRRS cable.
- Connect USB cable to the **left** side. 
- Enjoy SofleKeyboard!

## Troubleshooting

See the Sofle build guide.

**V2.0 Boards** - There is a known issue on V2.0 boards with the LED circuit - a trace is missing to a via on the underside of the board (on top on the left half)

Symptoms: only the first 4 underglow LEDs will work, this will occur on both halves of the board, 

Remedy: This can be easily corrected by adding a wire between the via and the trace immediately above it in the picture. You may need to scrape off the solder mask on the via depending on which manufacturer you used. 
The other end can either be attached to the trace (after removing some mask), or the footprint/led itself. 

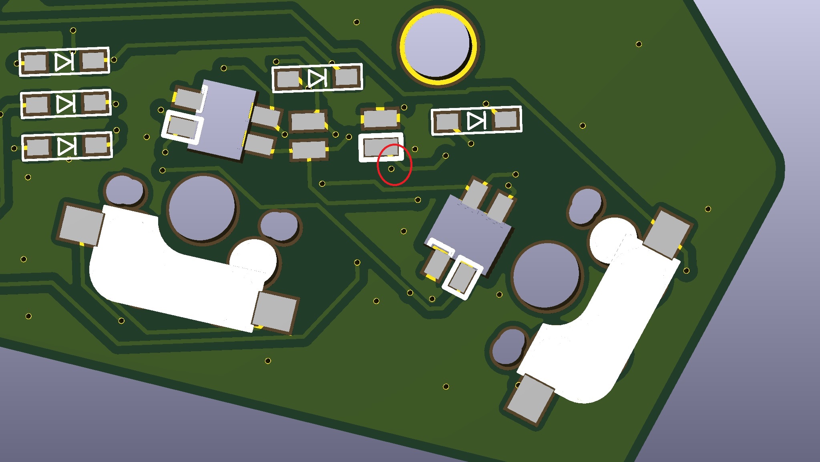
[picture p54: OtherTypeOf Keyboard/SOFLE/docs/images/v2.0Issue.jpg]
Problem Via, In the thumb cluster on the left half of the board.


This has been corrected in the v2.1 boards, and hopefully hasn't caught too many people out. Thanks to jmo808 for finding it, and apologies once again. 

## Links

- [Github with KiCad projects][soflegithub]
- [Layout in KeyboardLayout editor][soflelayout]
- [QMK Firmware][qmk_firmware]
- [QMK Configurator][qmk_configurator]

## Firmware 

SofleRGB uses [QMK firmware](https://qmk.fm/), it can use any Sofle keymap. 

## Default layout 

The default layout for the SofleRGB is in the qmk repo, and demonstrates some LED functions. 

Default layout for SofleRGB Keyboard

## Images of keyboard

SofleRGBKeyboard

SofleRGBKeyboard

SofleRGBKeyboard PCB

## Footnotes
[layoutarticle]: <https://josef-adamcik.cz/electronics/in-search-of-the-best-custom-keyboard-layout.html> "In search of the best custom keyboard layout"
[introductionarticle]: <https://josef-adamcik.cz/electronics/let-me-introduce-you-sofle-keyboard-split-keyboard-based-on-lily58.html> "Let me introduce you SofleKeyboard - a split keyboard based on Lily58 and Crkbd"
[soflelayout]: http://www.keyboard-layout-editor.com/#/gists/76efb423a46cbbea75465cb468eef7ff "Sofle Keyboard layout at keyboard-layout-editor.com"
[soflegerber]: https://github.com/josefadamcik/SofleKeyboard/releases "SofleKeyboard - gerber files"
[qmk_firmware]: https://github.com/qmk/qmk_firmware/ "QMK firmware"

[qmk_configurator]: https://config.qmk.fm/#/sofle/rev1/LAYOUT "QMK configurator"
[springpinheader]: <https://yushakobo.jp/shop/a01mc-00/> "Spring pin headers - Japaneese"
[qmkprotonc]: https://qmk.fm/proton-c/ "QMK Proton-C"
[promicrosocketing]: <https://docs.splitkb.com/hc/en-us/articles/360011263059> "How do I socket a microcontroller? by splitkb.com"
[qmkintro]: <https://beta.docs.qmk.fm/newbs/newbs_getting_started> "QMK getting started"
[qmkhandedness]: <https://docs.qmk.fm/#/feature_split_keyboard?id=setting-handedness> "QMK firmware - setting handedness"
[manufacturingproblems]: https://josef-adamcik.cz/electronics/corne-keyboard-build-log.html#manufacturing-at-jlcpcb---update-27112019 "Possible problems when manufacturing top plate for Corne"
[nooledlag]: https://github.com/qmk/qmk_firmware/issues/7522 "No OLED lag bug"
[soflegithub]: https://github.com/josefadamcik/SofleKeyboard "SofleKeyboard - KiCad project on Github.com"
[sourcing]: <{{ site.baseurl }}/sourcing_parts.html> "Sourcing parts"
[keyhivebuildguide]: <https://github.com/keyhive/build_guides/blob/master/docs/keyboards/sofle-rgb.md> "Sofle RGB Keyhive build guide"
[buildguide]: <{{ site.baseurl }}/build_guide.html> "Sofle V1/V2 build guide"

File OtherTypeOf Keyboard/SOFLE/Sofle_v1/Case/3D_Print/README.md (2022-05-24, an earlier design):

# Sofle Keyboard 3D Printed case

I added 3D printable STL files for Sofle Keyboard. Unfortunately, while I was trying to make sure that the board fits, Sofle v2 was launched and it doesn't work with the case I designed. If you still would like to use my case, you can find them under Sofle\_v1/case/3D\_print/ along with palm rests.

sample image

Case was CNC cut from STL file, palm rest was printed with ANYCUBIC i3 MEGA, PLA, 0.3mm layered.

plugging hole

I adjusted plug holes according to original sofle board. Instead of making it tight, I made the space large enough for better compatatibility.

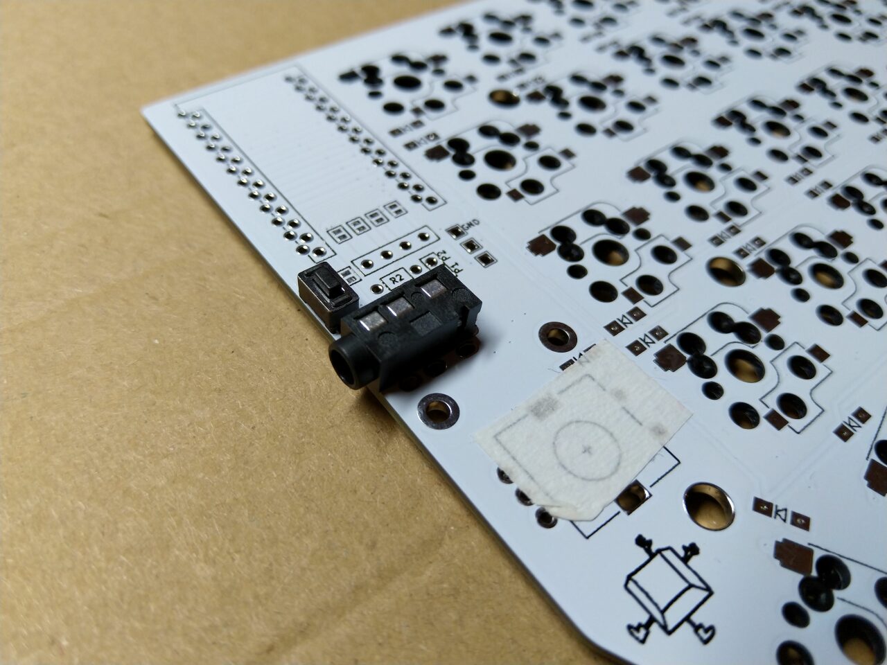
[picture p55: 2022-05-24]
OtherTypeOf Keyboard/SOFLE/docs/images/build_guide/IMG_20191106_204329.jpg

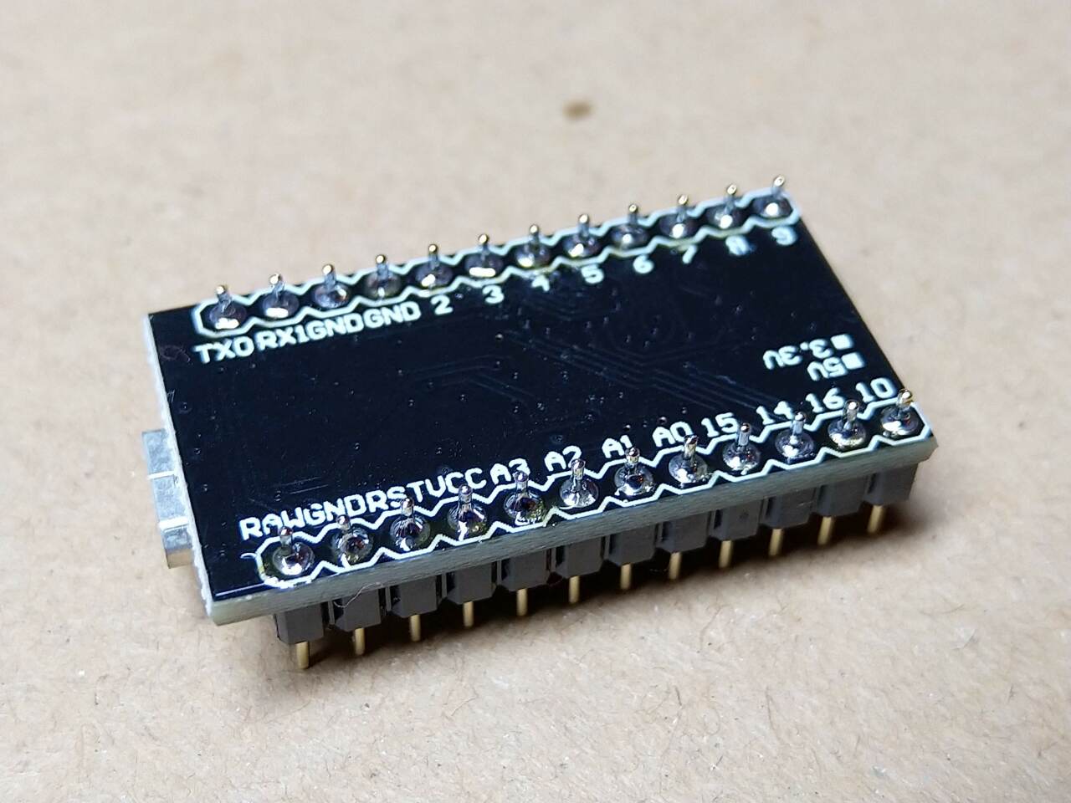
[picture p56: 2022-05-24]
OtherTypeOf Keyboard/SOFLE/docs/images/build_guide/IMG_20191106_205956.jpg

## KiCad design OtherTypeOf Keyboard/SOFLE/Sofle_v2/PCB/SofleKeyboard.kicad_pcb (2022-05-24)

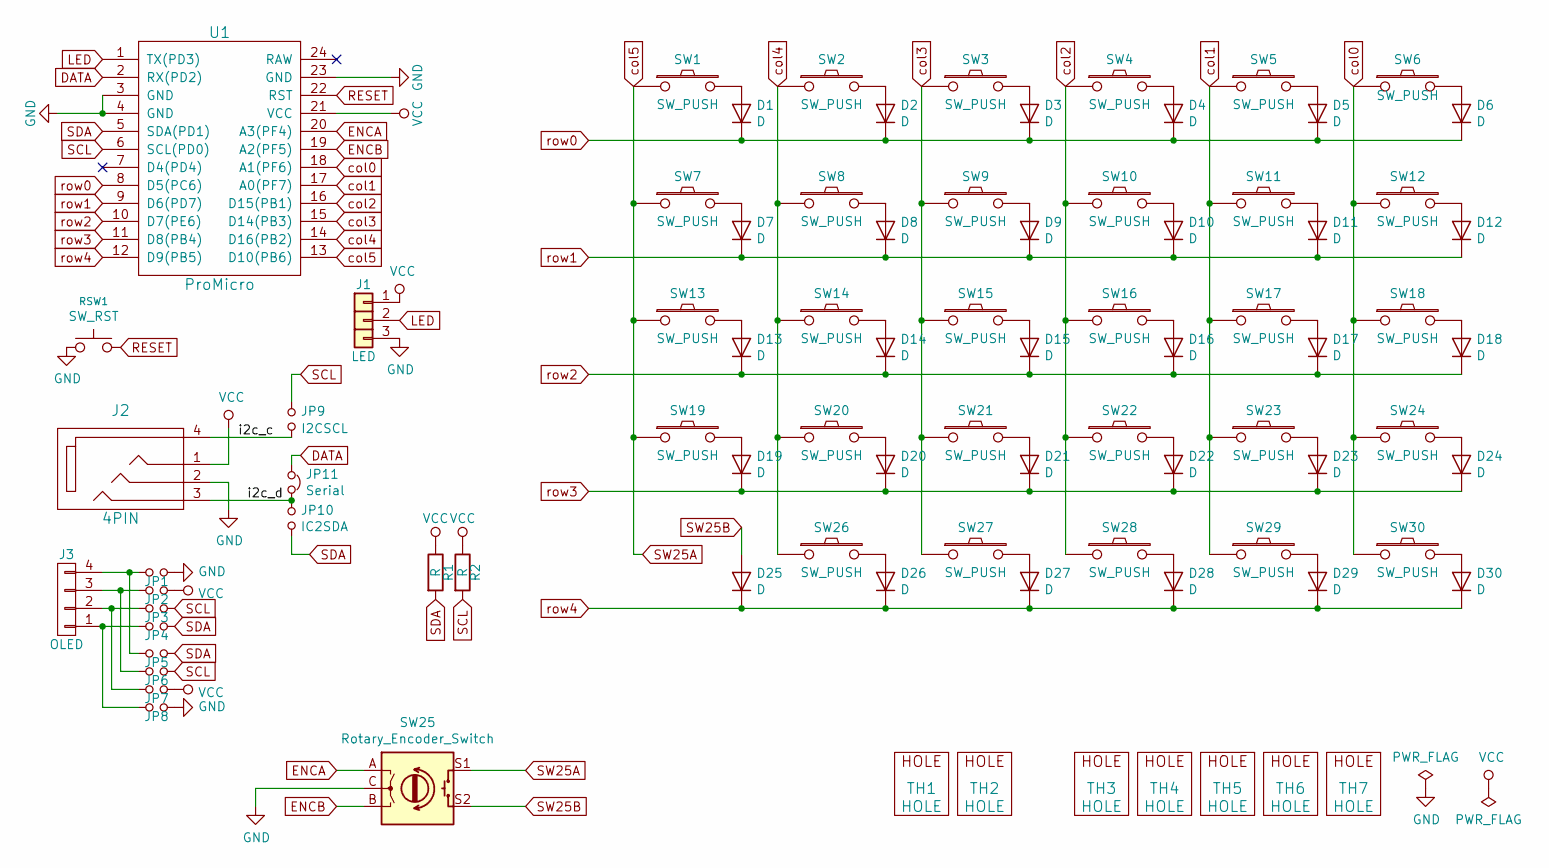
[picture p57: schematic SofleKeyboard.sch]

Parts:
D1, D2, D3, D4, D5, D6, D7, D8, D9, D10, D11, D12, D13, D14, D15, D16, D17, D18, D19, D20, D21, D22, D23, D24, D25, D26, D27, D28, D29, D30: D; Diode_SOD123
J1: LED
J2: 4PIN; MJ-4PP-9
J3: OLED; OLED_4Pin
JP1, JP2, JP3, JP4, JP5, JP6, JP7, JP8: Jumper_NO_Small; Jumper
JP9: I2CSCL; SolderJumper-2_P1.3mm_Open_TrianglePad1.0x1.5mm
JP10: IC2SDA; SolderJumper-2_P1.3mm_Open_TrianglePad1.0x1.5mm
JP11: Serial; SolderJumper-2_P1.3mm_Bridged2Bar_Pad1.0x1.5mm
R1, R2: R; R_1206_DoubleSided
RSW1: SW_RST; TACT_SWITCH_TVBP06
SW1, SW2, SW3, SW4, SW5, SW6, SW7, SW8, SW9, SW10, SW11, SW12, SW13, SW14, SW15, SW16, SW17, SW18, SW19, SW20, SW21, SW22, SW23, SW24, SW27, SW28, SW29, SW30: SW_PUSH; CherryMX_Hotswap
SW25: Rotary_Encoder_Switch; RotaryEncoder_Alps_EC11E-Switch_Vertical_H20mm-keebio_modif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
SW26: SW_PUSH; CherryMX_Hotswap_1.5
TH1, TH2: HOLE; M2_HOLE_PCB
TH3, TH4, TH5, TH6, TH7: HOLE; HOLE_M2_TH
U1: ProMicro; ArduinoProMicro-ZigZag-DoubleSided

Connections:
/i2c_c: J2.4, JP9.2
/i2c_d: J2.3, JP10.1, JP11.2
DATA: JP11.1, U1.2 (RX(PD2))
ENCA: SW25.A, U1.20 (A3(PF4))
ENCB: SW25.B, U1.19 (A2(PF5))
GND: J1.3, J2.2, JP1.2, JP8.2, RSW1.1, SW25.C, U1.3 (GND), U1.4 (GND), U1.23 (GND)
LED: J1.2, U1.1 (TX(PD3))
unnamed: D1.2 (A), SW1.2
unnamed: D2.2 (A), SW2.2
unnamed: D3.2 (A), SW3.2
unnamed: D4.2 (A), SW4.2
unnamed: D5.2 (A), SW5.2
unnamed: D6.2 (A), SW6.2
unnamed: D7.2 (A), SW7.2
unnamed: D8.2 (A), SW8.2
unnamed: D9.2 (A), SW9.2
unnamed: D10.2 (A), SW10.2
unnamed: D11.2 (A), SW11.2
unnamed: D12.2 (A), SW12.2
unnamed: D13.2 (A), SW13.2
unnamed: D14.2 (A), SW14.2
unnamed: D15.2 (A), SW15.2
unnamed: D16.2 (A), SW16.2
unnamed: D17.2 (A), SW17.2
unnamed: D18.2 (A), SW18.2
unnamed: D19.2 (A), SW19.2
unnamed: D20.2 (A), SW20.2
unnamed: D21.2 (A), SW21.2
unnamed: D22.2 (A), SW22.2
unnamed: D23.2 (A), SW23.2
unnamed: D24.2 (A), SW24.2
unnamed: D26.2 (A), SW26.2
unnamed: D27.2 (A), SW27.2
unnamed: D28.2 (A), SW28.2
unnamed: D29.2 (A), SW29.2
unnamed: D30.2 (A), SW30.2
unnamed: J3.1, JP4.1, JP8.1
unnamed: J3.2, JP3.1, JP7.1
unnamed: J3.3, JP2.1, JP6.1
unnamed: J3.4, JP1.1, JP5.1
RESET: RSW1.2, U1.22 (RST)
SCL: JP3.2, JP6.2, JP9.1, R2.2, U1.6 (SCL(PD0))
SDA: JP4.2, JP5.2, JP10.2, R1.2, U1.5 (SDA(PD1))
SW25A: SW1.1, SW7.1, SW13.1, SW19.1, SW25.S1, U1.13 (D10(PB6))
SW25B: D25.2 (A), SW25.S2
VCC: J1.1, J2.1, JP2.2, JP7.2, R1.1, R2.1, U1.21 (VCC)
col0: SW6.1, SW12.1, SW18.1, SW24.1, SW30.1, U1.18 (A1(PF6))
col1: SW5.1, SW11.1, SW17.1, SW23.1, SW29.1, U1.17 (A0(PF7))
col2: SW4.1, SW10.1, SW16.1, SW22.1, SW28.1, U1.16 (D15(PB1))
col3: SW3.1, SW9.1, SW15.1, SW21.1, SW27.1, U1.15 (D14(PB3))
col4: SW2.1, SW8.1, SW14.1, SW20.1, SW26.1, U1.14 (D16(PB2))
row0: D1.1 (K), D2.1 (K), D3.1 (K), D4.1 (K), D5.1 (K), D6.1 (K), U1.8 (D5(PC6))
row1: D7.1 (K), D8.1 (K), D9.1 (K), D10.1 (K), D11.1 (K), D12.1 (K), U1.9 (D6(PD7))
row2: D13.1 (K), D14.1 (K), D15.1 (K), D16.1 (K), D17.1 (K), D18.1 (K), U1.10 (D7(PE6))
row3: D19.1 (K), D20.1 (K), D21.1 (K), D22.1 (K), D23.1 (K), D24.1 (K), U1.11 (D8(PB4))
row4: D25.1 (K), D26.1 (K), D27.1 (K), D28.1 (K), D29.1 (K), D30.1 (K), U1.12 (D9(PB5))

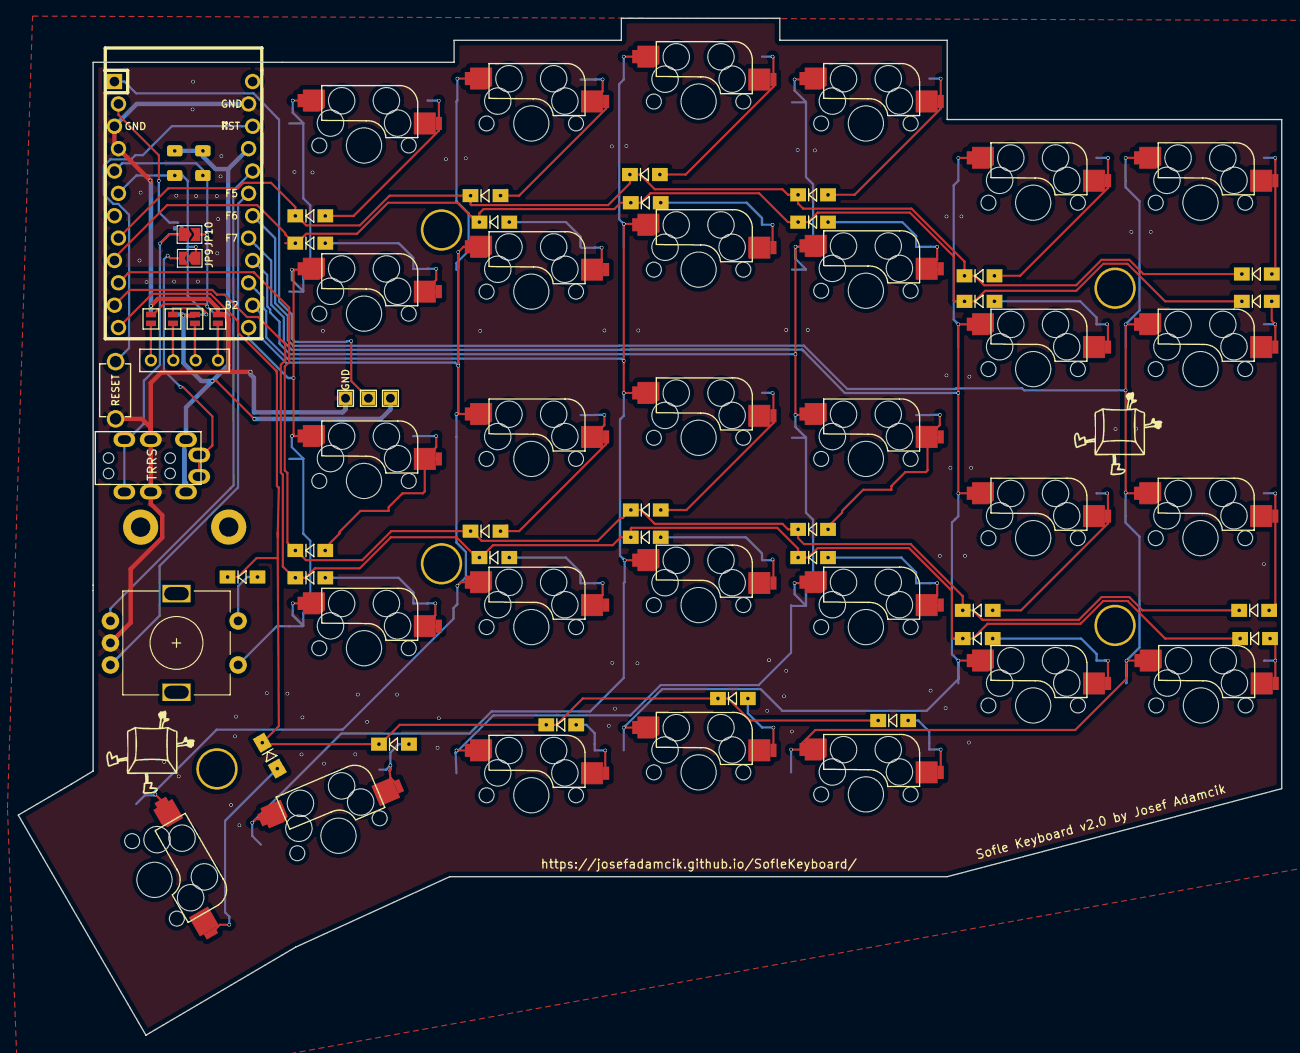
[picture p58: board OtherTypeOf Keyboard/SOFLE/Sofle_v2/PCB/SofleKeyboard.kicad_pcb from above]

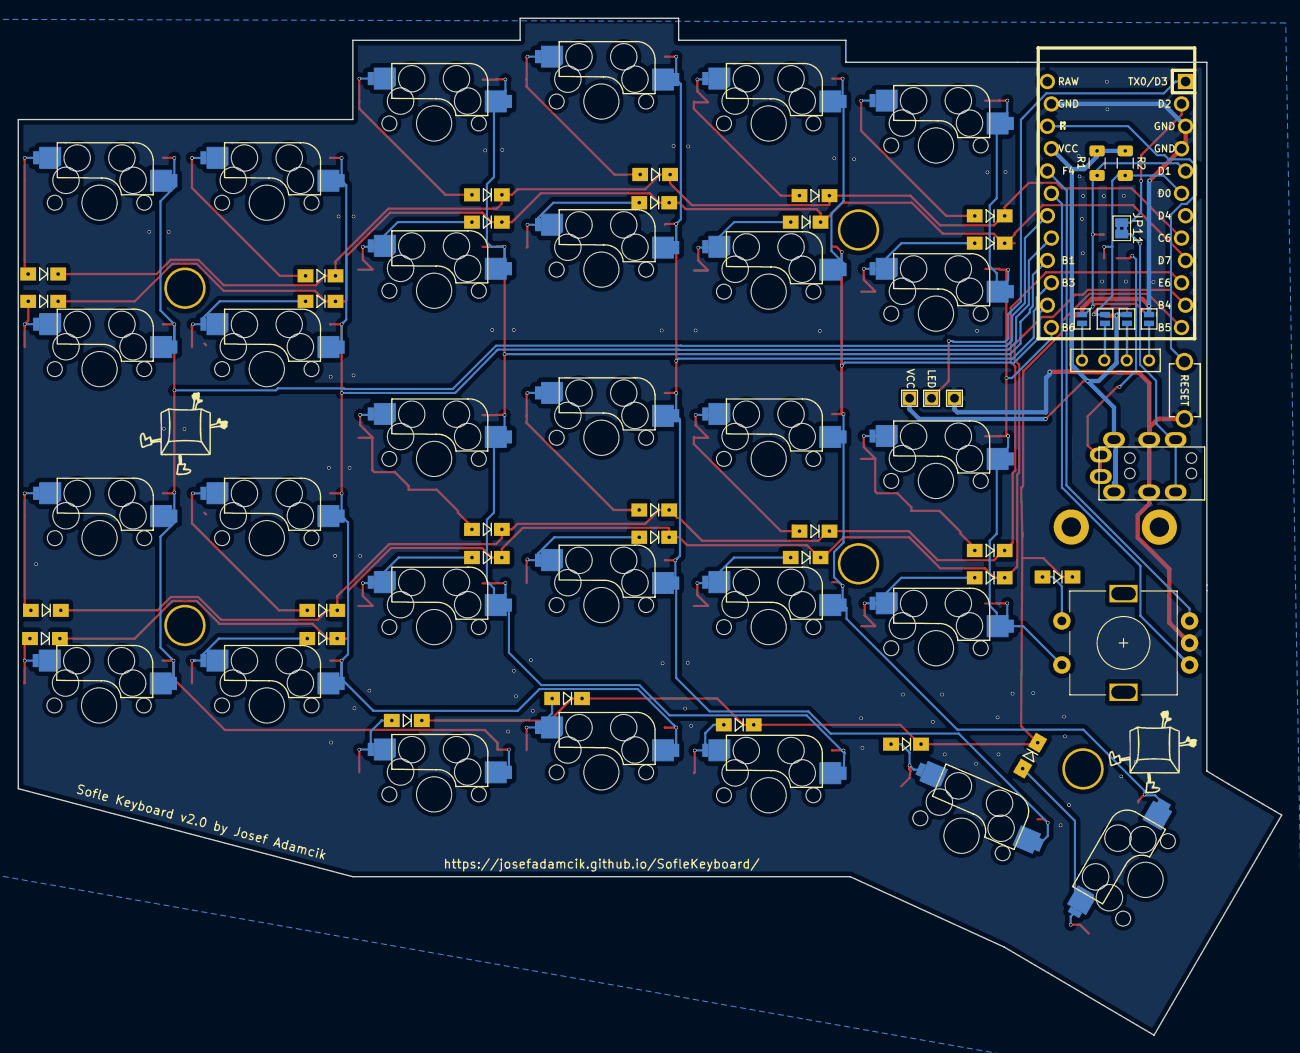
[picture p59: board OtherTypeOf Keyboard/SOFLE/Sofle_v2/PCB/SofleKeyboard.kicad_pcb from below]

Board: 2 copper layers, 143.5 x 115.5 mm, 89 parts (9 on the bottom side), 56 nets.

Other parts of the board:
Ref**: Val**; SofleLogoSmall
Ref**#2, Ref**#3, Ref**#4: Val**; SofleLogoSmall

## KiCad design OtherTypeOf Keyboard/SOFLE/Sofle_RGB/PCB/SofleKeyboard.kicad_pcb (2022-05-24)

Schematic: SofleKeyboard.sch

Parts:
D1, D2, D3, D4, D5, D6, D7, D8, D9, D10, D11, D12, D13, D14, D15, D16, D17, D18, D19, D20, D21, D22, D23, D24, D25, D26, D27, D28, D29, D30: D; crkbd-diode
D31, D32, D33, D34, D35, D36, D37: LED_sk2812_SM; SK6812MINI_underglow_dev
J1: LED
J2: 4PIN; MJ-4PP-9
J3: OLED; OLED_4Pin
J4: key leds; 3x1header
J5: backlight sel; 3x1header
J6: indicator bypass; 3x1header
JP1, JP2, JP3, JP4, JP5, JP6, JP7, JP8: Jumper_NO_Small; Jumper
P1, P2: i2c_pin; 1pin_conn
R1, R2: R; RESISTOR_mini
RSW1: SW_RST; TACT_SWITCH_TVBP06
SW1, SW2, SW3, SW4, SW5, SW6, SW7, SW8, SW9, SW10, SW11, SW12, SW13, SW14, SW15, SW16, SW17, SW18, SW19, SW20, SW21, SW22, SW23, SW24, SW26, SW27, SW28, SW29, SW30: SW_PUSH-MX_W_LED; SK6812MINI_and_cherry
SW25: Rotary_Encoder_Switch; RotaryEncoder_Alps_EC11E-Switch_Vertical_H20mm-keebio_modif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
TH1, TH2: HOLE; M2_HOLE_PCB
TH3, TH4, TH5, TH6, TH7: HOLE; HOLE_M2_TH
U1: ProMicro
W1: jumper; jumper_data

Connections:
/backlight: J4.1, J5.1, SW30.3
/i2c_c: J2.4, P1.1
/i2c_d: J2.3, P2.1, W1.2
/underglow: D33.3, J4.3
DATA: U1.2 (RX(PD2)), W1.1
ENCA: SW25.A, U1.20 (A3(PF4))
ENCB: SW25.B, U1.19 (A2(PF5))
GND: D31.2, D32.2, D33.2, D34.2, D35.2, D36.2, D37.2, J1.3, J2.2, JP1.2, JP8.2, RSW1.1, SW1.2, SW2.2, SW3.2, SW4.2, SW5.2, SW6.2, SW7.2, SW8.2, SW9.2, SW10.2, SW11.2, SW12.2, SW13.2, SW14.2, SW15.2, SW16.2, SW17.2, SW18.2, SW19.2, SW20.2, SW21.2, SW22.2, SW23.2, SW24.2, SW25.C, SW26.2, SW27.2, SW28.2, SW29.2, SW30.2, U1.3 (GND), U1.4 (GND), U1.23 (GND)
LED: J1.2, J6.2, U1.1 (TX(PD3))
unnamed: D1.2 (A), SW1.5
unnamed: D2.2 (A), SW2.5
unnamed: D3.2 (A), SW3.5
unnamed: D4.2 (A), SW4.5
unnamed: D5.2 (A), SW5.5
unnamed: D6.2 (A), SW6.5
unnamed: D7.2 (A), SW7.5
unnamed: D8.2 (A), SW8.5
unnamed: D9.2 (A), SW9.5
unnamed: D10.2 (A), SW10.5
unnamed: D11.2 (A), SW11.5
unnamed: D12.2 (A), SW12.5
unnamed: D13.2 (A), SW13.5
unnamed: D14.2 (A), SW14.5
unnamed: D15.2 (A), SW15.5
unnamed: D16.2 (A), SW16.5
unnamed: D17.2 (A), SW17.5
unnamed: D18.2 (A), SW18.5
unnamed: D19.2 (A), SW19.5
unnamed: D20.2 (A), SW20.5
unnamed: D21.2 (A), SW21.5
unnamed: D22.2 (A), SW22.5
unnamed: D23.2 (A), SW23.5
unnamed: D24.2 (A), SW24.5
unnamed: D26.2 (A), SW26.5
unnamed: D27.2 (A), SW27.5
unnamed: D28.2 (A), SW28.5
unnamed: D29.2 (A), SW29.5
unnamed: D30.2 (A), SW30.5
unnamed: D31.1, D34.3
unnamed: D31.3, D32.1
unnamed: D32.3, D33.1
unnamed: D34.1, D35.3
unnamed: D35.1, D36.3
unnamed: D36.1, J5.2
unnamed: D37.3, J6.3
unnamed: J3.1, JP4.1, JP8.1
unnamed: J3.2, JP3.1, JP7.1
unnamed: J3.3, JP2.1, JP6.1
unnamed: J3.4, JP1.1, JP5.1
unnamed: SW1.1, SW7.3
unnamed: SW1.3, SW2.1
unnamed: SW2.3, SW8.1
unnamed: SW3.1, SW9.3
unnamed: SW3.3, SW4.1
unnamed: SW5.3, SW6.1
unnamed: SW4.3, SW10.1
unnamed: SW10.3, SW16.1
unnamed: SW11.1, SW17.3
unnamed: SW5.1, SW11.3
unnamed: SW6.3, SW12.1
unnamed: SW12.3, SW18.1
unnamed: SW13.1, SW19.3
unnamed: SW7.1, SW13.3
unnamed: SW8.3, SW14.1
unnamed: SW14.3, SW20.1
unnamed: SW15.1, SW21.3
unnamed: SW9.1, SW15.3
unnamed: SW16.3, SW22.1
unnamed: SW17.1, SW23.3
unnamed: SW18.3, SW24.1
unnamed: SW20.3, SW26.1
unnamed: SW21.1, SW27.3
unnamed: SW22.3, SW28.1
unnamed: SW23.1, SW29.3
unnamed: SW24.3, SW30.1
unnamed: SW26.3, SW27.1
unnamed: SW28.3, SW29.1
RESET: RSW1.2, U1.22 (RST)
SCL: JP3.2, JP6.2, R2.2, U1.6 (SCL(PD0))
SDA: JP4.2, JP5.2, R1.2, U1.5 (SDA(PD1))
SW25A: SW1.6, SW7.6, SW13.6, SW19.6, SW25.S1, U1.13 (D10(PB6))
SW25B: D25.2 (A), SW25.S2
VCC: D31.4, D32.4, D33.4, D34.4, D35.4, D36.4, D37.4, J1.1, J2.1, JP2.2, JP7.2, R1.1, R2.1, SW1.4, SW2.4, SW3.4, SW4.4, SW5.4, SW6.4, SW7.4, SW8.4, SW9.4, SW10.4, SW11.4, SW12.4, SW13.4, SW14.4, SW15.4, SW16.4, SW17.4, SW18.4, SW19.4, SW20.4, SW21.4, SW22.4, SW23.4, SW24.4, SW26.4, SW27.4, SW28.4, SW29.4, SW30.4, U1.21 (VCC)
col0: SW6.6, SW12.6, SW18.6, SW24.6, SW30.6, U1.18 (A1(PF6))
col1: SW5.6, SW11.6, SW17.6, SW23.6, SW29.6, U1.17 (A0(PF7))
col2: SW4.6, SW10.6, SW16.6, SW22.6, SW28.6, U1.16 (D15(PB1))
col3: SW3.6, SW9.6, SW15.6, SW21.6, SW27.6, U1.15 (D14(PB3))
col4: SW2.6, SW8.6, SW14.6, SW20.6, SW26.6, U1.14 (D16(PB2))
lights: D37.1, J4.2, J6.1
row0: D1.1 (K), D2.1 (K), D3.1 (K), D4.1 (K), D5.1 (K), D6.1 (K), U1.8 (D5(PC6))
row1: D7.1 (K), D8.1 (K), D9.1 (K), D10.1 (K), D11.1 (K), D12.1 (K), U1.9 (D6(PD7))
row2: D13.1 (K), D14.1 (K), D15.1 (K), D16.1 (K), D17.1 (K), D18.1 (K), U1.10 (D7(PE6))
row3: D19.1 (K), D20.1 (K), D21.1 (K), D22.1 (K), D23.1 (K), D24.1 (K), U1.11 (D8(PB4))
row4: D25.1 (K), D26.1 (K), D27.1 (K), D28.1 (K), D29.1 (K), D30.1 (K), U1.12 (D9(PB5))

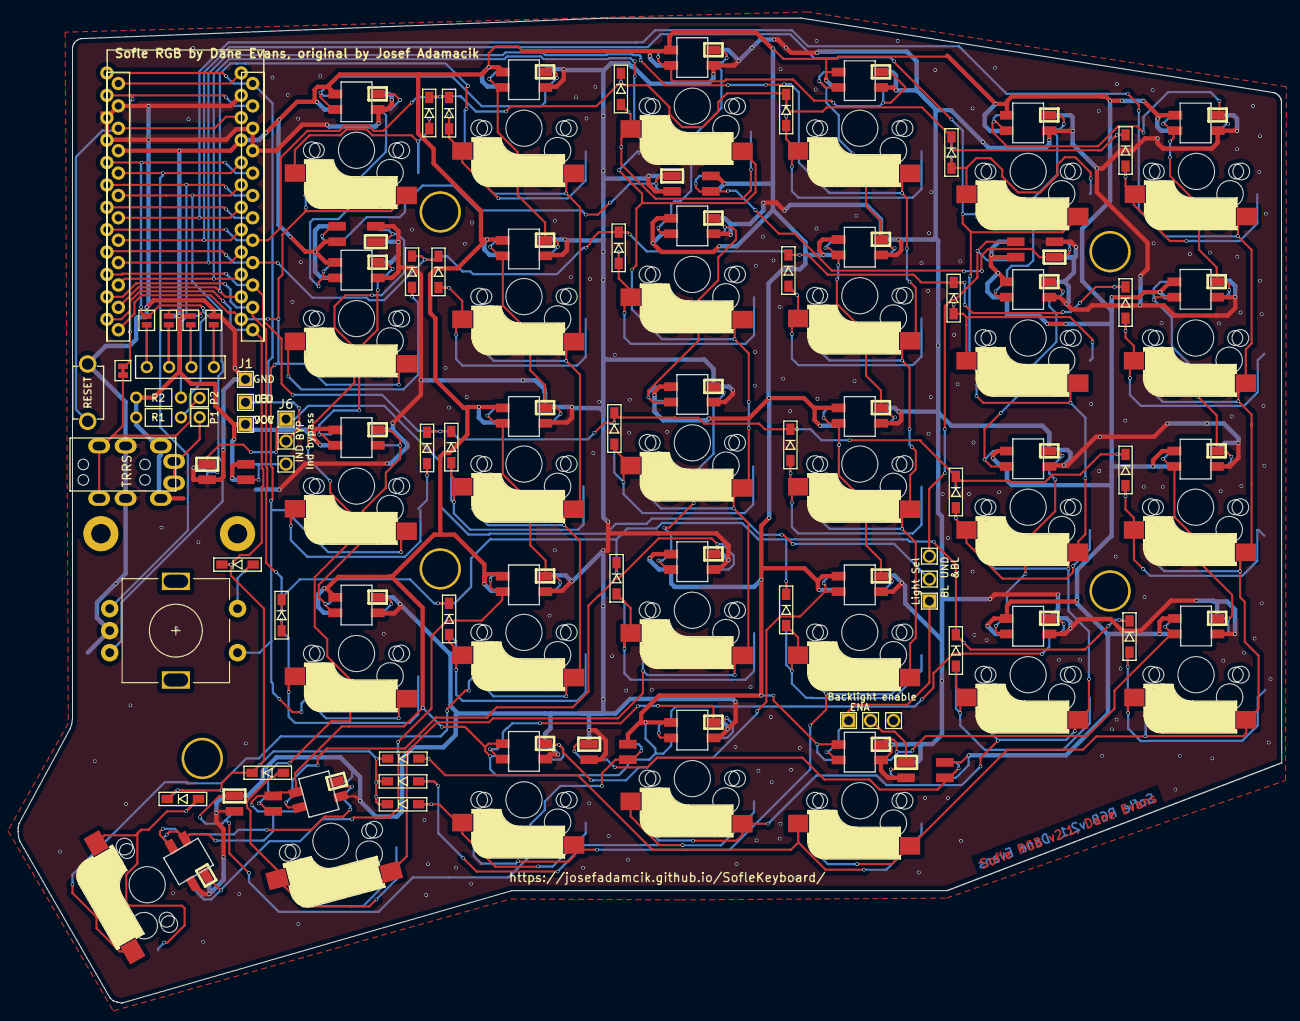
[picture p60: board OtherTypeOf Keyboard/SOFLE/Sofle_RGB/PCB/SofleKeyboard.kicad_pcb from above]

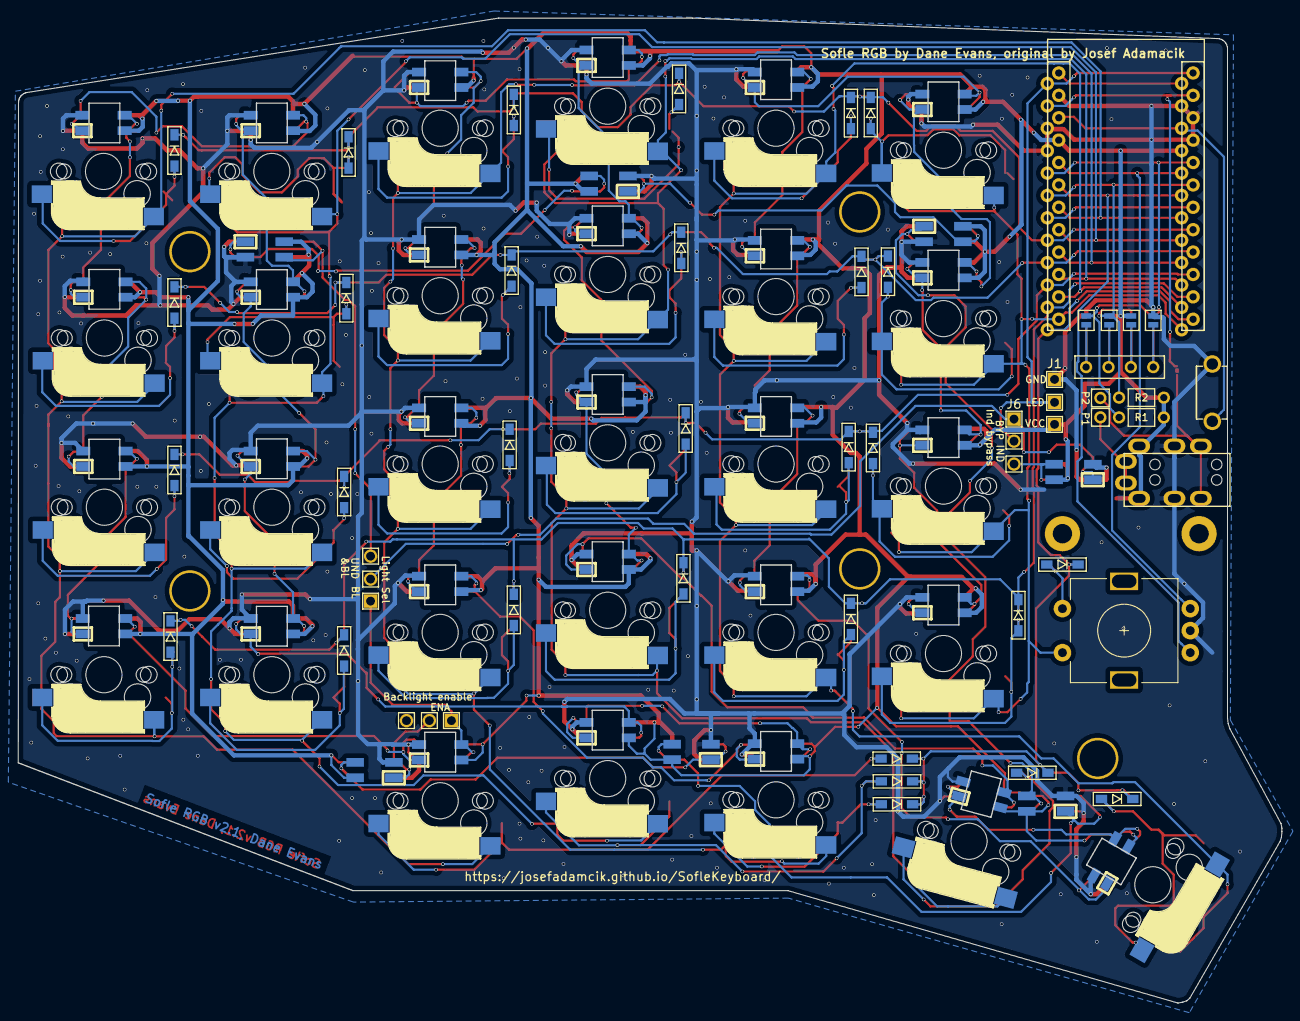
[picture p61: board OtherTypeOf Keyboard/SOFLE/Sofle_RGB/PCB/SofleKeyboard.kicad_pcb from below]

Board: 2 copper layers, 143.4 x 111.8 mm, 95 parts (4 on the bottom side), 94 nets.

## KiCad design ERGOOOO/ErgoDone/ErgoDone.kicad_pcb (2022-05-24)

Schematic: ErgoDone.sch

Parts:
C1: 0.1uF; C_Disc_D6_P5
D1, D3, D5, D7, D9, D11, D13, D15, D17, D19, D21, D23, D25, D27, D29, D31, D33, D35, D37, D39, D41, D43, D45, D47, D49, D51, D53, D55, D57, D59, D61, D63, D65, D67, D69, D71, D73, D75, D77, D79: DIODE; D_1206_L
D2, D4, D6, D8, D10, D12, D14, D16, D18, D20, D22, D24, D26, D28, D30, D32, D34, D36, D38, D40, D42, D44, D46, D48, D50, D52, D54, D56, D58, D60, D62, D64, D66, D68, D70, D72, D74, D76, D78, D80: DIODE; D_1206_R
D81, D82: DIODE; DIODE_SX
H99: MECHANICAL
J1: USB; USBMINImod
J2: 3.5mm; 4pin35mmAudio
J3, J4: JMP; 100PITCH1X3
LED_A1: LEDa; ERGO_LED-3MM
LED_B1: LEDb; ERGO_LED-3MM
LED_C1: LEDc; ERGO_LED-3MM
R1, R2: 2.2kΩ; ERGO_RESISTOR
RA1: LEDa; ERGO_RESISTOR
RB1: LEDb; ERGO_RESISTOR
RC1: LEDc; ERGO_RESISTOR
S1, S2: STAB200; STAB_PCB940
SW0:7: SW0:6; MX_FLIP_DIODE_NOSMD
SW0:8: SW0:5; MX_FLIP_DIODE_NOSMD
SW0:9: SW0:4; MX_FLIP_DIODE_NOSMD
SW0:10: SW0:3; MX_FLIP_DIODE_NOSMD
SW0:11: SW0:2; MX_FLIP_DIODE_NOSMD
SW0:12: SW0:1; MX_FLIP_DIODE_NOSMD
SW1:9: SW1:4; MX_FLIP_DIODE_NOSMD
SW1:10: SW1:3; MX_FLIP_DIODE_NOSMD
SW1:11: SW1:2; MX_FLIP_DIODE_NOSMD
SW1:12: SW1:1; MX_FLIP_DIODE_NOSMD
SW1:13: SW1:0; MX_FLIP_DIODE_NOSMD
SW2:7: SW2:6; MX_FLIP_DIODE_NOSMD
SW2:8: SW2:5; MX_FLIP_DIODE_NOSMD
SW2:9: SW2:4; MX_FLIP_DIODE_NOSMD
SW2:10: SW2:3; MX_FLIP_DIODE_NOSMD
SW2:11: SW2:2; MX_FLIP_DIODE_NOSMD
SW2:12: SW2:1; MX_FLIP_DIODE_NOSMD
SW2:13: SW2:0; MX_FLIP_XX_NOSMD
SW3:8: SW3:5; MX_FLIP_DIODE_NOSMD
SW3:9: SW3:4; MX_FLIP_DIODE_NOSMD
SW3:10: SW3:3; MX_FLIP_DIODE_NOSMD
SW3:11: SW3:2; MX_FLIP_DIODE_NOSMD
SW3:12: SW3:1; MX_FLIP_DIODE_NOSMD
SW3:13: SW3:0; MX_FLIP_XX_NOSMD
SW4:7: SW4:6; MX_FLIP_DIODE_NOSMD
SW4:8: SW4:5; MX_FLIP_DIODE_NOSMD
SW4:9: SW4:4; MX_FLIP_DIODE_NOSMD
SW4:10: SW4:3; MX_FLIP_DIODE_NOSMD
SW4:11: SW4:2; MX_FLIP_DIODE_NOSMD
SW4:12: SW4:1; MX_FLIP_DIODE_NOSMD
SW4:13: SW4:0; MX_FLIP_XX_NOSMD
SW5:7: SW5:6; MX_FLIP_DIODE_NOSMD
SW5:8: SW5:5; MX_FLIP_DIODE_NOSMD
SW5:9: SW5:4; MX_FLIP_DIODE_NOSMD
SW5:10: SW5:3; MX_FLIP_DIODE_NOSMD
SW5:11: SW5:2; MX_FLIP_DIODE_NOSMD
SW5:12: SW5:1; MX_FLIP_DIODE_NOSMD
SW5:13: SW5:0; MX_FLIP_XX_NOSMD
SX0:10: SX0:3; MX_FLIP
SX0:11: SX0:2; MX_FLIP
SX1:7: SX1:6; MX_FLIP
SX1:8: SX1:5; MX_FLIP
U1: ProMicro
U2: MCP23017

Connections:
/COL0: D71.2 (K), D72.2 (K), D73.2 (K), D74.2 (K), D75.2 (K), D76.2 (K), D77.2 (K), D78.2 (K), D79.2 (K), D80.2 (K), SW1:13.4, SW2:13.4, SW3:13.4, SW4:13.4, SW5:13.4, U1.11, U2.21
/COL1: D59.2 (K), D60.2 (K), D61.2 (K), D62.2 (K), D63.2 (K), D64.2 (K), D65.2 (K), D66.2 (K), D67.2 (K), D68.2 (K), D69.2 (K), D70.2 (K), SW0:12.4, SW1:12.4, SW2:12.4, SW3:12.4, SW4:12.4, SW5:12.4, U1.10, U2.22
/COL4: D23.2 (K), D24.2 (K), D25.2 (K), D26.2 (K), D27.2 (K), D28.2 (K), D29.2 (K), D30.2 (K), D31.2 (K), D32.2 (K), D33.2 (K), D34.2 (K), SW0:9.4, SW1:9.4, SW2:9.4, SW3:9.4, SW4:9.4, SW5:9.4, U1.7, U2.25
/COL5: D11.2 (K), D12.2 (K), D13.2 (K), D14.2 (K), D15.2 (K), D16.2 (K), D17.2 (K), D18.2 (K), D19.2 (K), D20.2 (K), D21.2 (K), D22.2 (K), D82.2, SW0:8.4, SW2:8.4, SW3:8.4, SW4:8.4, SW5:8.4, U1.2, U2.27
/COL6: D1.2 (K), D2.2 (K), D3.2 (K), D4.2 (K), D5.2 (K), D6.2 (K), D7.2 (K), D8.2 (K), D9.2 (K), D10.2 (K), D81.2, SW0:7.4, SW2:7.4, SW4:7.4, SW5:7.4, U1.1, U2.28
/COL10: D35.2 (K), D36.2 (K), D37.2 (K), D38.2 (K), D39.2 (K), D40.2 (K), D41.2 (K), D42.2 (K), D43.2 (K), D44.2 (K), D45.2 (K), D46.2 (K), SW0:10.4, SW1:10.4, SW2:10.4, SW3:10.4, SW4:10.4, SW5:10.4, U1.8, U2.24
/COL11: D47.2 (K), D48.2 (K), D49.2 (K), D50.2 (K), D51.2 (K), D52.2 (K), D53.2 (K), D54.2 (K), D55.2 (K), D56.2 (K), D57.2 (K), D58.2 (K), SW0:11.4, SW1:11.4, SW2:11.4, SW3:11.4, SW4:11.4, SW5:11.4, U1.9, U2.23
/LED_A: RA1.1, U1.12
/LED_B: RB1.1, U1.18
/LED_C: RC1.1, U1.20
/ROW0: SW0:7.1, SW0:8.1, SW0:9.1, SW0:10.1, SW0:11.1, SW0:12.1, SX0:10.1, SX0:11.1, U1.19, U2.7
/ROW1: SW1:9.1, SW1:10.1, SW1:11.1, SW1:12.1, SW1:13.1, SX1:7.1, SX1:8.1, U1.21, U2.6
/ROW2: SW2:7.1, SW2:8.1, SW2:9.1, SW2:10.1, SW2:11.1, SW2:12.1, SW2:13.1, U1.22, U2.5
/ROW3: SW3:8.1, SW3:9.1, SW3:10.1, SW3:11.1, SW3:12.1, SW3:13.1, U1.23, U2.4
/ROW4: SW4:7.1, SW4:8.1, SW4:9.1, SW4:10.1, SW4:11.1, SW4:12.1, SW4:13.1, U1.24, U2.3
/ROW5: SW5:7.1, SW5:8.1, SW5:9.1, SW5:10.1, SW5:11.1, SW5:12.1, SW5:13.1, U1.25, U2.2
/SCLM: J2.3, J2.5, R2.2, U1.6, U2.12
/SDAM: J3.1, J4.1, R1.2, U1.5, U2.13
GND: C1.2, J1.5, J3.3, J4.3, LED_A1.2, LED_B1.2, LED_C1.2, U1.3, U1.4, U1.28, U2.10, U2.15, U2.16, U2.17
unnamed: D1.1 (A), D2.1 (A), SW5:7.2, SW5:7.3
unnamed: D3.1 (A), D4.1 (A), SW4:7.2, SW4:7.3
unnamed: D5.1 (A), D6.1 (A), SW2:7.2, SW2:7.3
unnamed: D7.1 (A), D8.1 (A), D81.1, SX1:7.2
unnamed: D9.1 (A), D10.1 (A), SW0:7.2, SW0:7.3
unnamed: D11.1 (A), D12.1 (A), SW5:8.2, SW5:8.3
unnamed: D13.1 (A), D14.1 (A), SW4:8.2, SW4:8.3
unnamed: D15.1 (A), D16.1 (A), SW3:8.2, SW3:8.3
unnamed: D17.1 (A), D18.1 (A), SW2:8.2, SW2:8.3
unnamed: D19.1 (A), D20.1 (A), D82.1, SX1:8.2
unnamed: D21.1 (A), D22.1 (A), SW0:8.2, SW0:8.3
unnamed: D23.1 (A), D24.1 (A), SW5:9.2, SW5:9.3
unnamed: D25.1 (A), D26.1 (A), SW4:9.2, SW4:9.3
unnamed: D27.1 (A), D28.1 (A), SW3:9.2, SW3:9.3
unnamed: D29.1 (A), D30.1 (A), SW2:9.2, SW2:9.3
unnamed: D31.1 (A), D32.1 (A), SW1:9.2, SW1:9.3
unnamed: D33.1 (A), D34.1 (A), SW0:9.2, SW0:9.3
unnamed: D35.1 (A), D36.1 (A), SW5:10.2, SW5:10.3
unnamed: D37.1 (A), D38.1 (A), SW4:10.2, SW4:10.3
unnamed: D39.1 (A), D40.1 (A), SW3:10.2, SW3:10.3
unnamed: D41.1 (A), D42.1 (A), SW2:10.2, SW2:10.3
unnamed: D43.1 (A), D44.1 (A), SW1:10.2, SW1:10.3
unnamed: D45.1 (A), D46.1 (A), SW0:10.2, SW0:10.3, SX0:10.2
unnamed: D47.1 (A), D48.1 (A), SW5:11.2, SW5:11.3
unnamed: D49.1 (A), D50.1 (A), SW4:11.2, SW4:11.3
unnamed: D51.1 (A), D52.1 (A), SW3:11.2, SW3:11.3
unnamed: D53.1 (A), D54.1 (A), SW2:11.2, SW2:11.3
unnamed: D55.1 (A), D56.1 (A), SW1:11.2, SW1:11.3
unnamed: D57.1 (A), D58.1 (A), SW0:11.2, SW0:11.3, SX0:11.2
unnamed: D59.1 (A), D60.1 (A), SW5:12.2, SW5:12.3
unnamed: D61.1 (A), D62.1 (A), SW4:12.2, SW4:12.3
unnamed: D63.1 (A), D64.1 (A), SW3:12.2, SW3:12.3
unnamed: D65.1 (A), D66.1 (A), SW2:12.2, SW2:12.3
unnamed: D67.1 (A), D68.1 (A), SW1:12.2, SW1:12.3
unnamed: D69.1 (A), D70.1 (A), SW0:12.2, SW0:12.3
unnamed: D71.1 (A), D72.1 (A), SW5:13.2, SW5:13.3
unnamed: D73.1 (A), D74.1 (A), SW4:13.2, SW4:13.3
unnamed: D75.1 (A), D76.1 (A), SW3:13.2, SW3:13.3
unnamed: D77.1 (A), D78.1 (A), SW2:13.2, SW2:13.3
unnamed: D79.1 (A), D80.1 (A), SW1:13.2, SW1:13.3
unnamed: J2.1, J3.2
unnamed: J2.4, J4.2
unnamed: LED_A1.1, RA1.2
unnamed: LED_B1.1, RB1.2
unnamed: LED_C1.1, RC1.2
VCC: C1.1, J1.1, J2.2, J2.6, R1.1, R2.1, U1.26, U2.9, U2.18

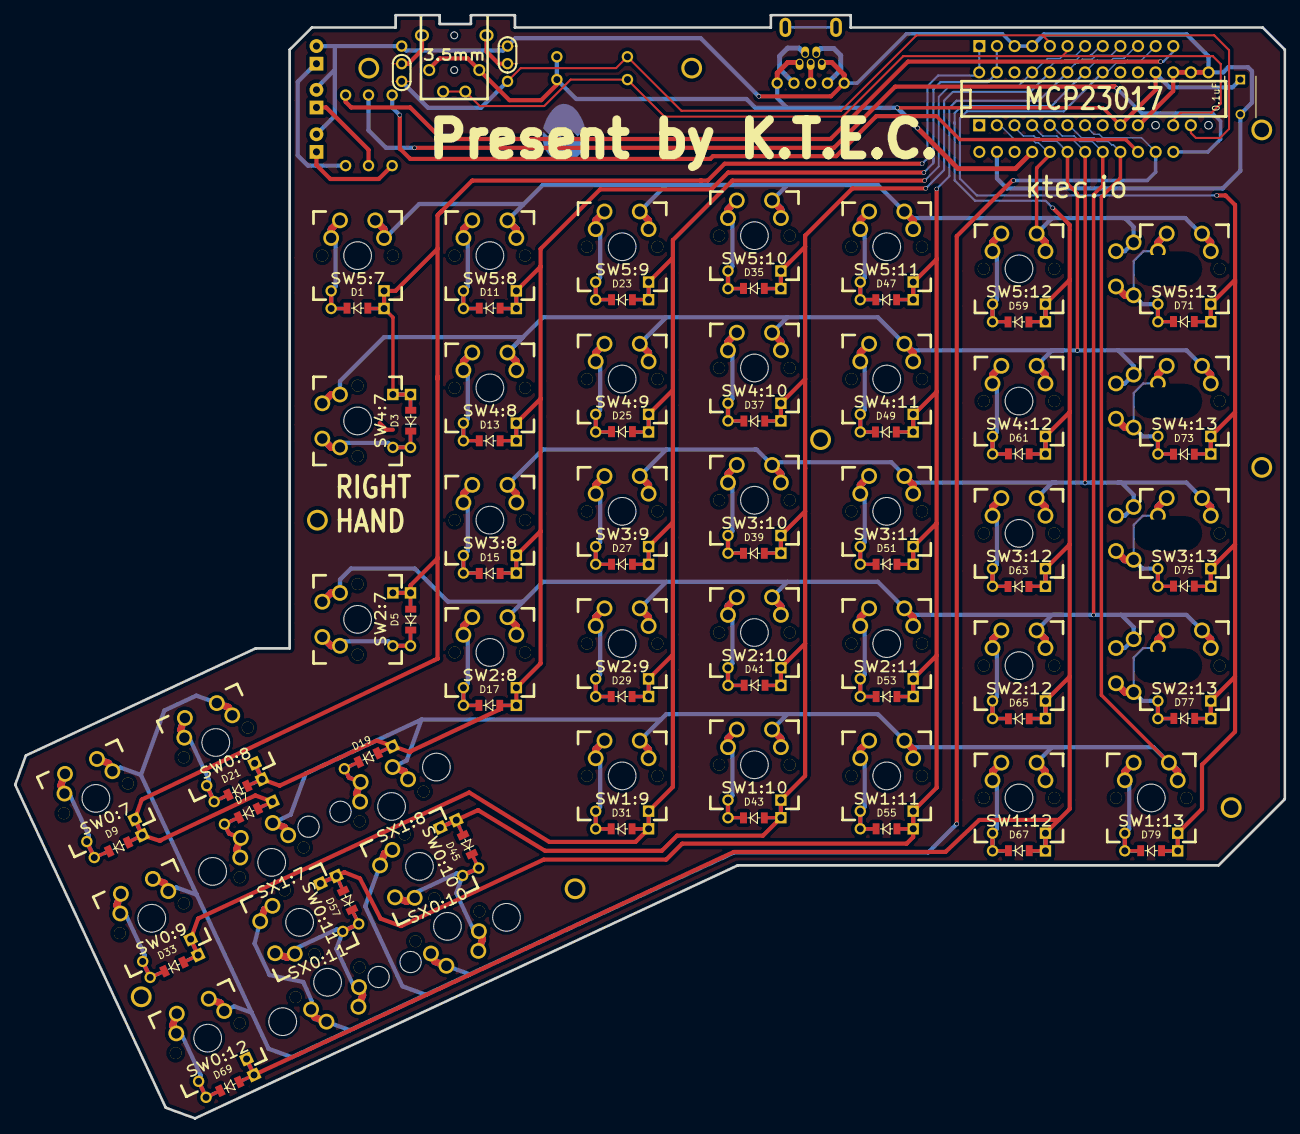
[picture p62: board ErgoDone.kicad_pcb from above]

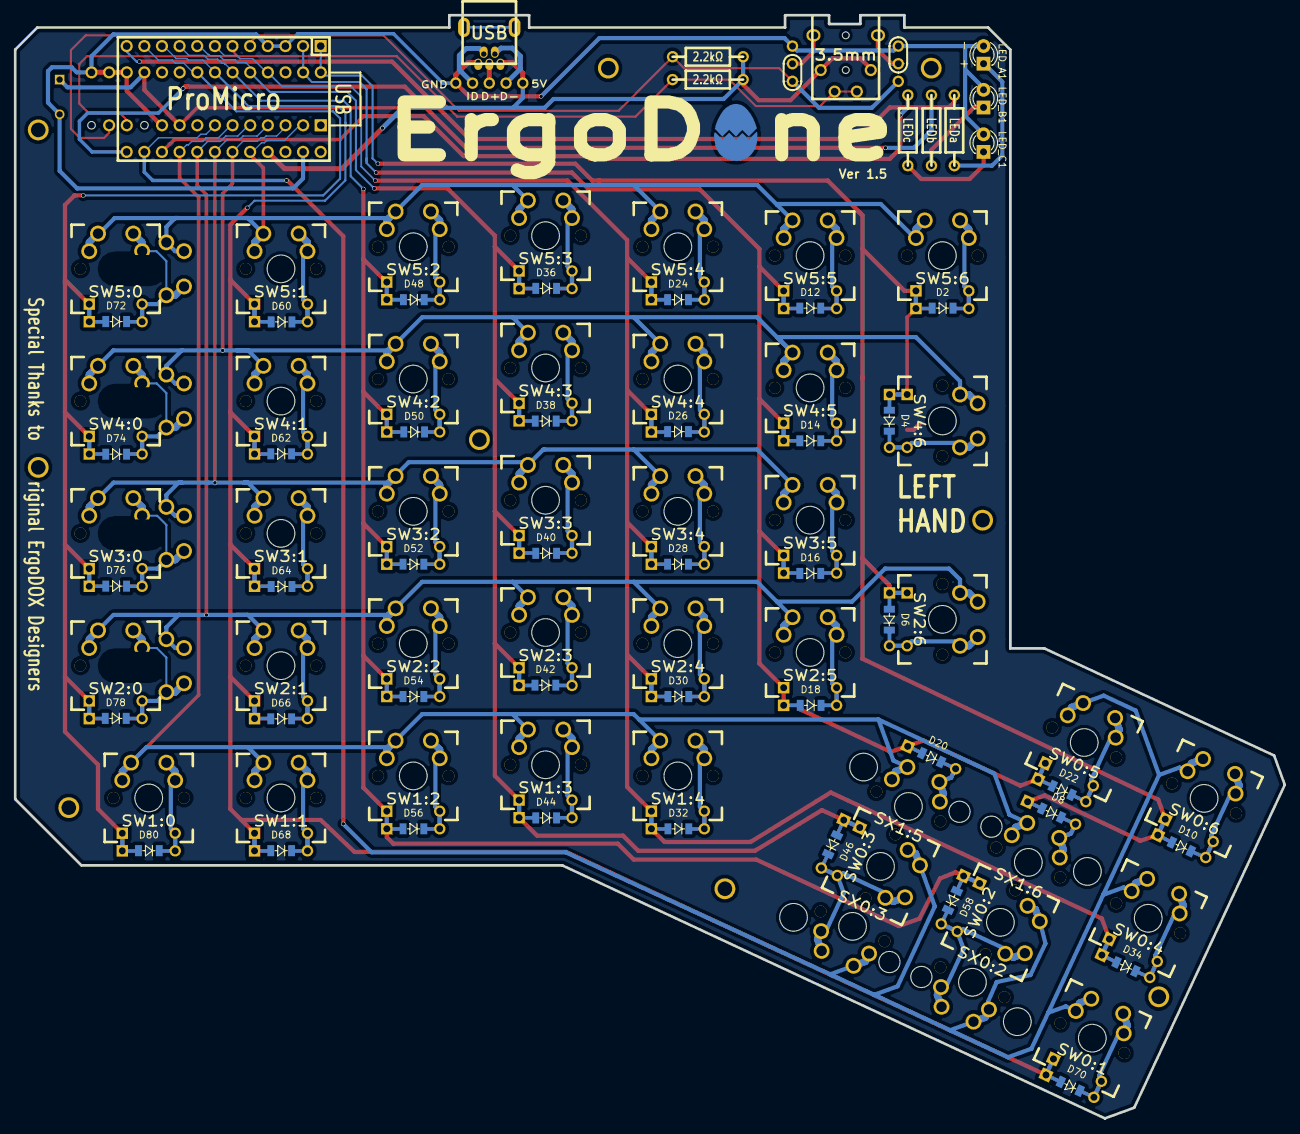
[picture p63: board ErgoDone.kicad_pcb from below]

Board: 2 copper layers, 182.8 x 158.9 mm, 141 parts (51 on the bottom side), 65 nets.

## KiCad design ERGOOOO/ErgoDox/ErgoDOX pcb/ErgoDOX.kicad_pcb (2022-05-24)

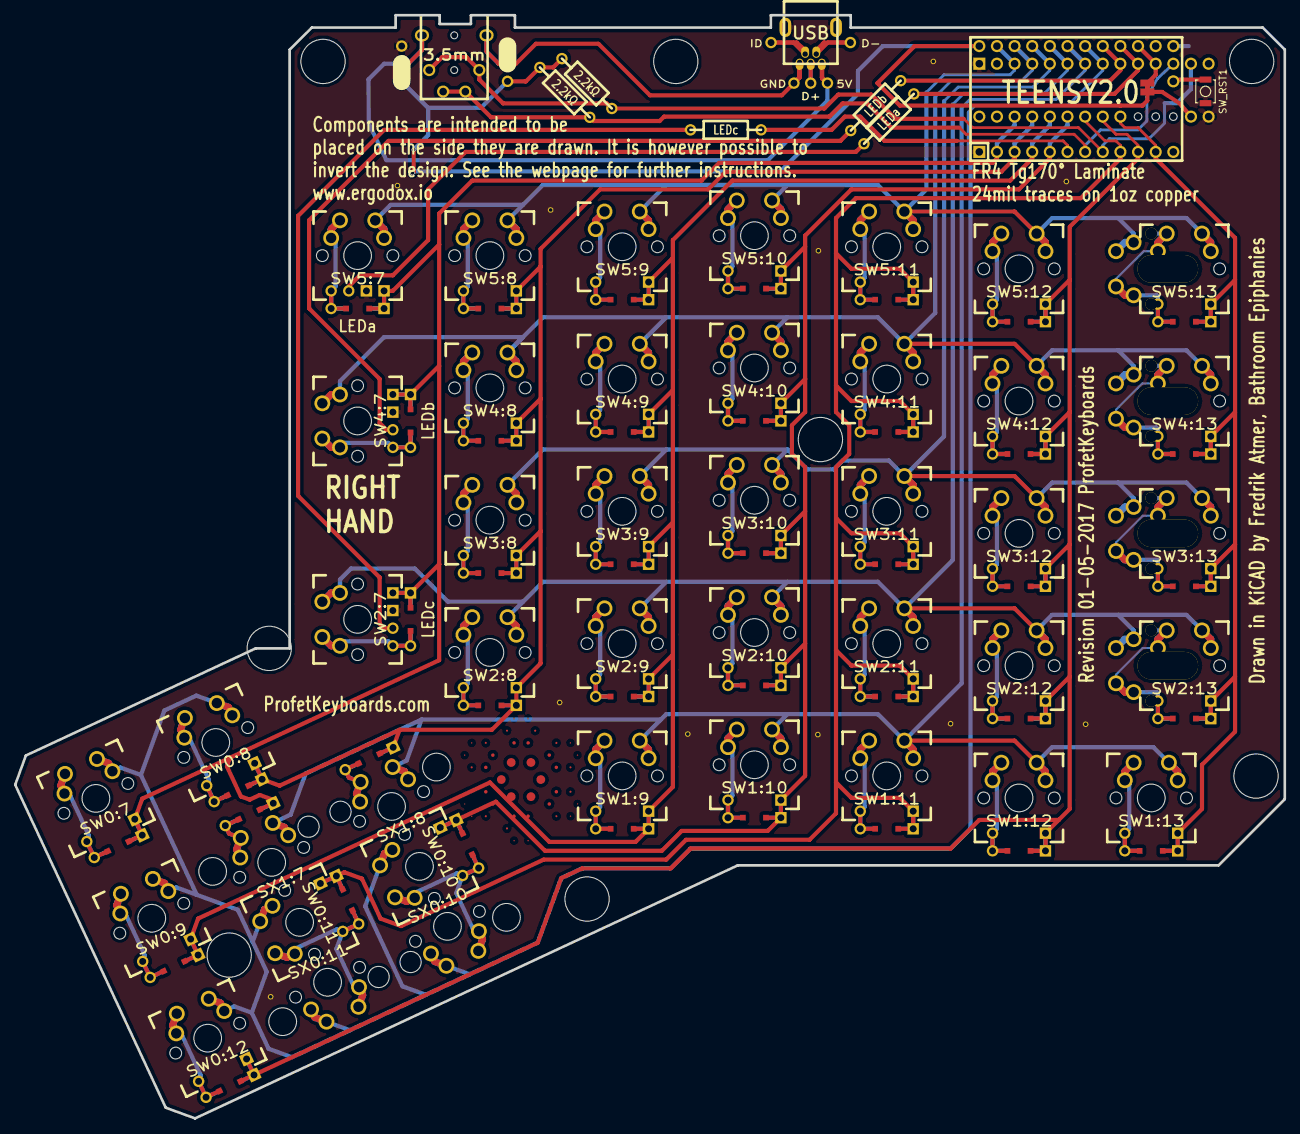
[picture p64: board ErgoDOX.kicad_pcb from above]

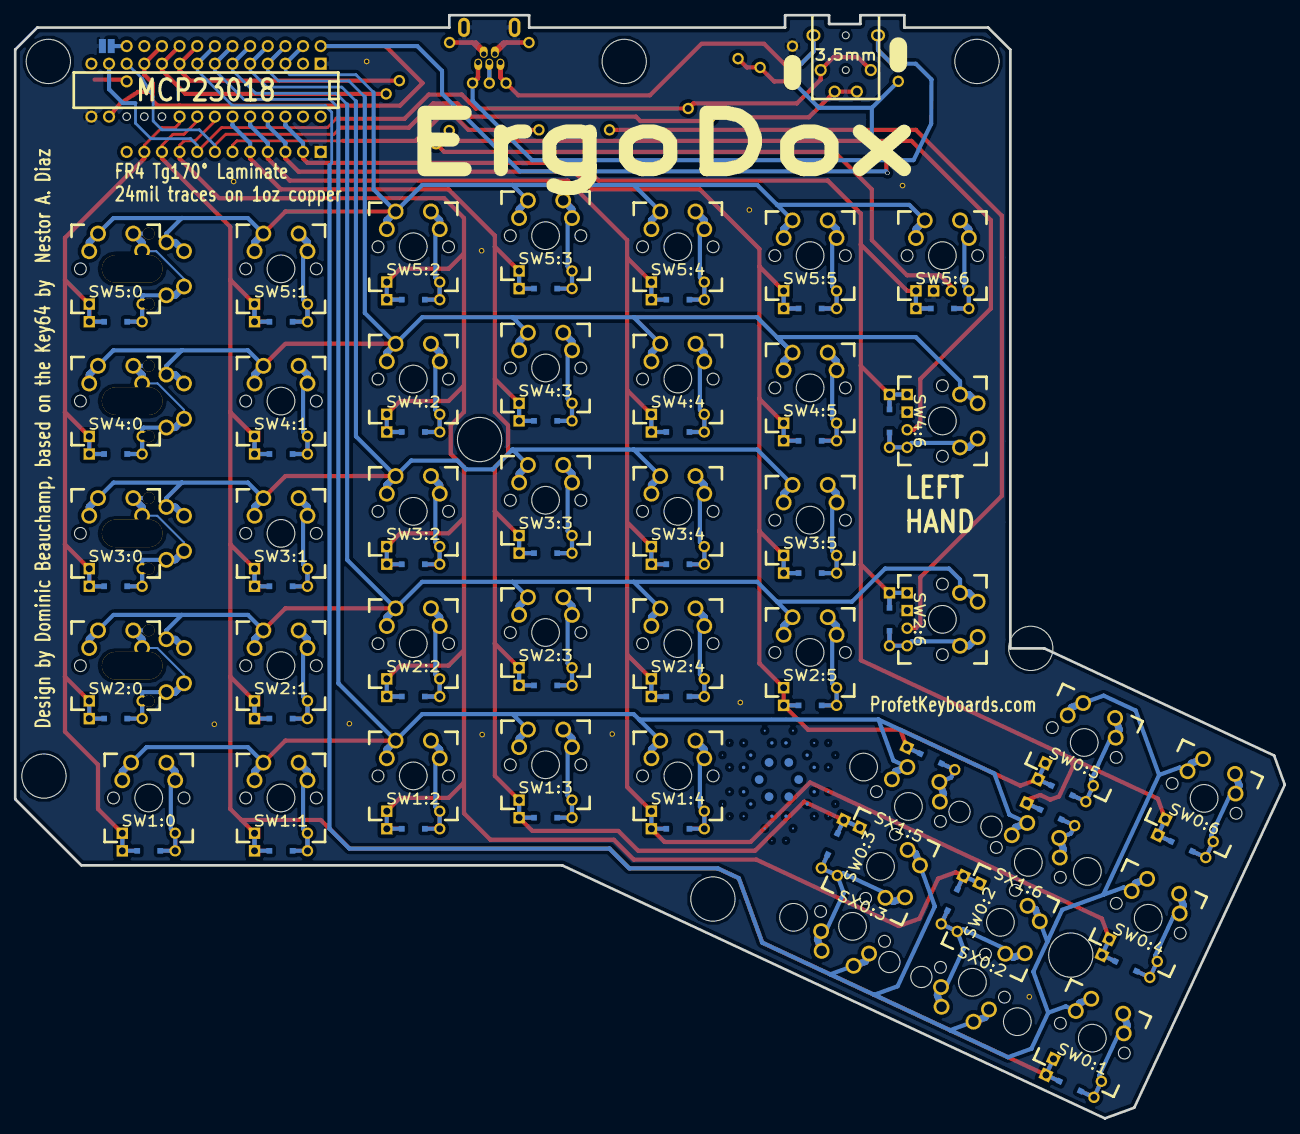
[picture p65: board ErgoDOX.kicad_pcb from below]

Board: 2 copper layers, 182.8 x 158.9 mm, 77 parts (4 on the bottom side), 66 nets.

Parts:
D1:7, D1:8: D; DIODE
H99: MECHANICAL; ErgoDOXmech
J1: USB; USBMINImod
J2: 3.5mm; 4pin35mmAudio
J3, J4: JMP; 100PITCH1X3
JP1, JP2: JUMPER; GAP
LED_A1: LEDa; MX_LED
LED_B1: LEDb; MX_LED
LED_C1: LEDc; MX_LED
R1, R2: 2.2kΩ; RESISTOR
RA1: LEDa; RESISTOR
RB1: LEDb; RESISTOR
RC1: LEDc; RESISTOR
S1, S2: STAB200; STAB_PCB940
STAR_1: STAR_FRONT; STAR
STAR_2: STAR_BACK; STAR
STITCHING_VIA: STITCHING_VIA
STITCHING_VIA#2, STITCHING_VIA#3, STITCHING_VIA#4, STITCHING_VIA#5, STITCHING_VIA#6, STITCHING_VIA#7, STITCHING_VIA#8, STITCHING_VIA#9, STITCHING_VIA#10, STITCHING_VIA#11: STITCHING_VIA
SW0:7: SW0:6; MX_FLIP_DIODE
SW0:8: SW0:5; MX_FLIP_DIODE
SW0:9: SW0:4; MX_FLIP_DIODE
SW0:10: SW0:3; MX_FLIP_DIODE
SW0:11: SW0:2; MX_FLIP_DIODE
SW0:12: SW0:1; MX_FLIP_DIODE
SW1:9: SW1:4; MX_FLIP_DIODE
SW1:10: SW1:3; MX_FLIP_DIODE
SW1:11: SW1:2; MX_FLIP_DIODE
SW1:12: SW1:1; MX_FLIP_DIODE
SW1:13: SW1:0; MX_FLIP_DIODE
SW2:7: SW2:6; MX_FLIP_DIODE
SW2:8: SW2:5; MX_FLIP_DIODE
SW2:9: SW2:4; MX_FLIP_DIODE
SW2:10: SW2:3; MX_FLIP_DIODE
SW2:11: SW2:2; MX_FLIP_DIODE
SW2:12: SW2:1; MX_FLIP_DIODE
SW2:13: SW2:0; MX_FLIP_XX
SW3:8: SW3:5; MX_FLIP_DIODE
SW3:9: SW3:4; MX_FLIP_DIODE
SW3:10: SW3:3; MX_FLIP_DIODE
SW3:11: SW3:2; MX_FLIP_DIODE
SW3:12: SW3:1; MX_FLIP_DIODE
SW3:13: SW3:0; MX_FLIP_XX
SW4:7: SW4:6; MX_FLIP_DIODE
SW4:8: SW4:5; MX_FLIP_DIODE
SW4:9: SW4:4; MX_FLIP_DIODE
SW4:10: SW4:3; MX_FLIP_DIODE
SW4:11: SW4:2; MX_FLIP_DIODE
SW4:12: SW4:1; MX_FLIP_DIODE
SW4:13: SW4:0; MX_FLIP_XX
SW5:7: SW5:6; MX_FLIP_DIODE
SW5:8: SW5:5; MX_FLIP_DIODE
SW5:9: SW5:4; MX_FLIP_DIODE
SW5:10: SW5:3; MX_FLIP_DIODE
SW5:11: SW5:2; MX_FLIP_DIODE
SW5:12: SW5:1; MX_FLIP_DIODE
SW5:13: SW5:0; MX_FLIP_XX
SW_RST1: SWITCH_PUSH; SW_SPST_B3U-1000P
SX0:10: SX0:3; MX_FLIP
SX0:11: SX0:2; MX_FLIP
SX1:7: SX1:6; MX_FLIP
SX1:8: SX1:5; MX_FLIP
U1: TEENSY2.0; TEENSY_2.0_WITH_RESET
U2: MCP23018; DIP28_300

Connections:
/COL0: SW1:13.4, SW2:13.4, SW3:13.4, SW4:13.4, SW5:13.4, U1.11, U2.20
/COL1: SW0:12.4, SW1:12.4, SW2:12.4, SW3:12.4, SW4:12.4, SW5:12.4, U1.10, U2.21
/COL4: SW0:9.4, SW1:9.4, SW2:9.4, SW3:9.4, SW4:9.4, SW5:9.4, U1.4, U2.24
/COL5: D1:8.2, SW0:8.4, SW2:8.4, SW3:8.4, SW4:8.4, SW5:8.4, U1.3, U2.25
/COL6: D1:7.2, SW0:7.4, SW2:7.4, SW4:7.4, SW5:7.4, U1.2, U2.26
/COL10: SW0:10.4, SW1:10.4, SW2:10.4, SW3:10.4, SW4:10.4, SW5:10.4, U1.5, U2.23
/COL11: SW0:11.4, SW1:11.4, SW2:11.4, SW3:11.4, SW4:11.4, SW5:11.4, U1.9, U2.22
/LED_A: RA1.1, U1.21, U2.10
/LED_B: RB1.1, U1.22, U2.9
/LED_C: RC1.1, U1.6
/ROW0: SW0:7.1, SW0:8.1, SW0:9.1, SW0:10.1, SW0:11.1, SW0:12.1, SX0:10.1, SX0:11.1, U1.23, U2.8
/ROW1: SW1:9.1, SW1:10.1, SW1:11.1, SW1:12.1, SW1:13.1, SX1:7.1, SX1:8.1, U1.24, U2.7
/ROW2: SW2:7.1, SW2:8.1, SW2:9.1, SW2:10.1, SW2:11.1, SW2:12.1, SW2:13.1, U1.25, U2.6
/ROW3: SW3:8.1, SW3:9.1, SW3:10.1, SW3:11.1, SW3:12.1, SW3:13.1, U1.26, U2.5
/ROW4: SW4:7.1, SW4:8.1, SW4:9.1, SW4:10.1, SW4:11.1, SW4:12.1, SW4:13.1, U1.27, U2.4
/ROW5: SW5:7.1, SW5:8.1, SW5:9.1, SW5:10.1, SW5:11.1, SW5:12.1, SW5:13.1, U1.28, U2.3
/RST: SW_RST1.1, U1.16
/SCLM: J2.3, J2.5, R2.2, U1.7, U2.12
/SDAM: J2.2, J2.6, R1.2, U1.8, U2.13
GND: J1.6, J3.3, J4.3, JP2.1, LED_A1.2, LED_B1.2, LED_C1.2, STITCHING_VIA.GND, STITCHING_VIA#2.GND, STITCHING_VIA#3.GND, STITCHING_VIA#4.GND, STITCHING_VIA#5.GND, STITCHING_VIA#6.GND, STITCHING_VIA#7.GND, STITCHING_VIA#8.GND, STITCHING_VIA#9.GND, STITCHING_VIA#10.GND, STITCHING_VIA#11.GND, SW_RST1.2, U1.1, U1.18, U2.1, U2.15
unnamed: D1:7.1, SX1:7.2
unnamed: D1:8.1, SX1:8.2
unnamed: J1.1, J2.4, J4.2
unnamed: J1.5, J2.1, J3.2
unnamed: LED_A1.1, RA1.2
unnamed: LED_B1.1, RB1.2
unnamed: LED_C1.1, RC1.2
unnamed: SW0:7.2, SW0:7.3
unnamed: SW0:8.2, SW0:8.3
unnamed: SW0:9.2, SW0:9.3
unnamed: SW0:10.2, SW0:10.3, SX0:10.2
unnamed: SW0:11.2, SW0:11.3, SX0:11.2
unnamed: SW0:12.2, SW0:12.3
unnamed: SW1:9.2, SW1:9.3
unnamed: SW1:10.2, SW1:10.3
unnamed: SW1:11.2, SW1:11.3
unnamed: SW1:12.2, SW1:12.3
unnamed: SW1:13.2, SW1:13.3
unnamed: SW2:7.2, SW2:7.3
unnamed: SW2:8.2, SW2:8.3
unnamed: SW2:9.2, SW2:9.3
unnamed: SW2:10.2, SW2:10.3
unnamed: SW2:11.2, SW2:11.3
unnamed: SW2:12.2, SW2:12.3
unnamed: SW2:13.2, SW2:13.3
unnamed: SW3:8.2, SW3:8.3
unnamed: SW3:9.2, SW3:9.3
unnamed: SW3:10.2, SW3:10.3
unnamed: SW3:11.2, SW3:11.3
unnamed: SW3:12.2, SW3:12.3
unnamed: SW3:13.2, SW3:13.3
unnamed: SW4:7.2, SW4:7.3
unnamed: SW4:8.2, SW4:8.3
unnamed: SW4:9.2, SW4:9.3
unnamed: SW4:10.2, SW4:10.3
unnamed: SW4:11.2, SW4:11.3
unnamed: SW4:12.2, SW4:12.3
unnamed: SW4:13.2, SW4:13.3
unnamed: SW5:7.2, SW5:7.3
unnamed: SW5:8.2, SW5:8.3
unnamed: SW5:9.2, SW5:9.3
unnamed: SW5:10.2, SW5:10.3
unnamed: SW5:11.2, SW5:11.3
unnamed: SW5:12.2, SW5:12.3
unnamed: SW5:13.2, SW5:13.3
VCC: J3.1, J4.1, JP1.1, R1.1, R2.1, U1.20, U1.29, U2.11, U2.16

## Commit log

2022-05-24 firt commit
    [ErgoDOX Case Layer 1 Top - Left.dxf, ErgoDOX Case Layer 1 Top - Right.dxf, ErgoDOX Case Layer 2 Spacer - Left.dxf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]
2022-05-25 modif 3D files
    [2022-05-24T083445.csv, LeftBottom.stl, MergePlateTopLeft.stl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]
